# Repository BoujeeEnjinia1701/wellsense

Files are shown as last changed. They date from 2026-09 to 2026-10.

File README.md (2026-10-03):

# WellSense

     

**Area:** Water Security · **TRL:** 3 of 9 (proof of concept on paper) · **Value-engineering target:** $200 USD for WellSense parts (estimated $262.40), FieldNode core costed separately · **Difficulty:** 2 of 5

A well and borehole water level logger with a submersible pressure sensor and FieldNode telemetry, showing seasonal drawdown so communities can manage shared groundwater.

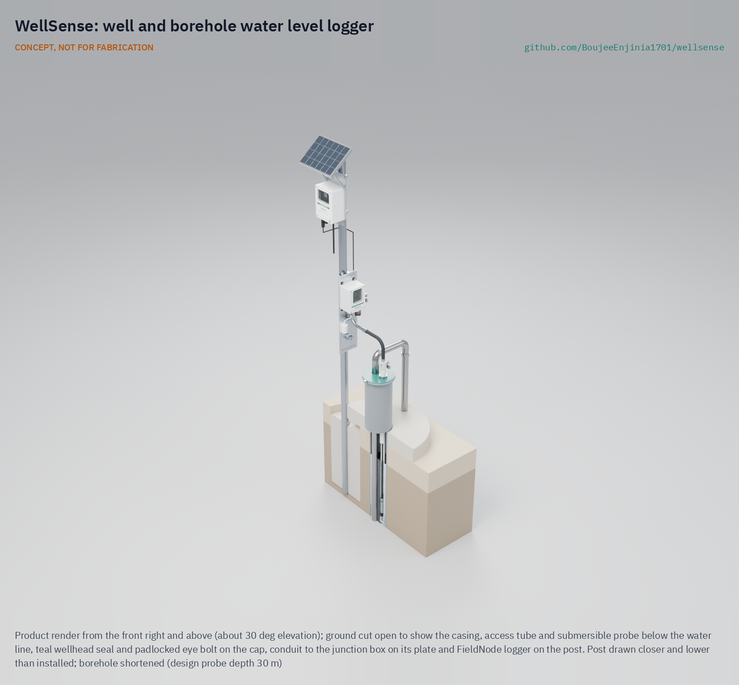
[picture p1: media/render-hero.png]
WellSense: well and borehole water level logger, product render


[Exploded render](media/render-exploded.png) · [Detail render](media/render-detail.png) · [Interactive 3D model](media/viewer.html) · [Concept blueprint (PDF)](media/concept-blueprint.pdf) · [General arrangement WLS-DWG-001 (PDF)](cad/drawings/WLS-DWG-001.pdf) · [Sizing calculations](docs/04-calcs/01-sizing.md) · [Prototype build plan](docs/05-build-plan.md) · [Design decisions register](docs/06-design-decisions.md) · [Review note](docs/REVIEW.md)

## Concept rationale

Measurement is the first step to shared management of an aquifer. A vented pressure transducer hung in a well gives a continuous water level record with millimetre resolution, and it is the same method groundwater agencies use ([USGS, 2011](https://pubs.usgs.gov/tm/1a1/)). WellSense puts that method in the wells people already draw from, on the lab's shared FieldNode core, so the only new parts are the probe, an access tube, a wellhead seal and a small interface board. A manual tape check each quarter keeps the record honest.

It is open and garage-buildable because the communities that share falling aquifers are rarely the ones that own monitoring equipment. Commercial loggers are closed and costly; a design built from plumbing parts, a stock industrial transducer and off-the-shelf modules can be made, checked and repaired locally, and its data belong to the community that hosts the well.

## Burning platform

Groundwater provides about half of the water withdrawn for domestic use worldwide, including drinking water for most rural people, and about 25 % of irrigation water ([UNESCO, WWDR 2022](https://www.unesco.org/reports/wwdr/2022/en)). Across 1,693 aquifer systems, rapid declines of more than 0.5 m a year are widespread in the twenty-first century, and declines have accelerated over four decades in 30 % of regional aquifers ([Jasechko et al., Nature, 2024](https://www.nature.com/articles/s41586-023-06879-8)).

When levels fall unmeasured, the response is to drill deeper: in the United States, typical wells are being built deeper 1.4 to 9.2 times more often than shallower, which the authors call an unsustainable stopgap ([Perrone and Jasechko, 2019](https://www.nature.com/articles/s41893-019-0325-z)). The same global study shows that levels recover where pumping is regulated, as in the Bangkok basin, so a shared record that people trust is worth having early.

## Where it could be used

### By industry

| Industry | Use |
| --- | --- |
| Rural water supply and WASH programmes | Warn handpump and borehole committees before the static level nears the pump intake |
| Irrigated agriculture | Let farmer groups see seasonal drawdown in their own wells and agree pumping or cropping rules |
| Groundwater agencies and utilities | Densify official networks with low-cost community wells between observation boreholes |
| Drought early warning | Feed well levels into local drought indicators alongside rainfall |
| Mining, construction and dewatering | Track the effect of dewatering on neighbouring wells |
| Education and research | Teach aquifer response to pumping, recharge and air pressure with open data |

### By country or region

| Country or region | Why it matters there |
| --- | --- |
| India | The largest groundwater user in the world, over a quarter of the global total; groundwater serves more than 60 % of irrigated agriculture and 85 % of drinking water supplies ([World Bank](https://www.worldbank.org/en/news/feature/2012/03/06/india-groundwater-critical-diminishing)). |
| Sub-Saharan Africa | Groundwater storage is estimated at more than 100 times annual renewable freshwater, and boreholes can support handpumps ([MacDonald et al., 2012](https://iopscience.iop.org/article/10.1088/1748-9326/7/2/024009)), yet about one in four handpumps is out of service at any time ([Foster et al., 2019, via IRC](https://www.ircwash.org/resources/functionality-handpump-water-supplies-review-data-sub-saharan-africa-and-asia-pacific)). |
| Iran and the Arabian Peninsula | Named among regions of rapid decline in the global synthesis, which also reports slowing decline in the Saq aquifer after policy changes ([Jasechko et al., 2024](https://www.nature.com/articles/s41586-023-06879-8)). |
| United States (California) | The 2014 Sustainable Groundwater Management Act requires local agencies to reach sustainability within 20 years under monitored plans ([California DWR](https://water.ca.gov/programs/groundwater-management/sgma-groundwater-management)). |
| Southeastern Spain | Aquifer declines there are too small in area for satellite gravity to detect, so they must be measured in wells ([Jasechko et al., 2024](https://www.nature.com/articles/s41586-023-06879-8)). |
| Thailand (Bangkok) | Levels that fell in the late twentieth century recovered after regulation ([Jasechko et al., 2024](https://www.nature.com/articles/s41586-023-06879-8)), a case for measuring and managing early. |

## What sparked the idea

The starting point was the Andhra Pradesh Farmer Managed Groundwater Systems project, launched in 2003 in seven drought-prone districts of southern India ([FAO](https://www.fao.org/land-water/overview/projects/previous-projects/andhra-pradesh-farmer-managed-groundwater-systems/en/)). There, farmers took fortnightly measurements of static and pumping water levels in their own wells, kept rain gauges, and used the numbers to draw up a crop-water budget before each winter season; about half a million farmers in 661 habitations took part ([FAO, *Smallholders and Sustainable Wells*, 2013](https://www.fao.org/4/i3320e/i3320e.pdf)). The project showed that people who share an aquifer will manage it when they can see the water level themselves. WellSense asks what that practice looks like with a continuous, low-cost record in place of a hand reading every two weeks, so that the daily pumping cycle and the seasonal decline are visible between visits.

## Problem

Groundwater is falling in many regions, yet most wells have no measurement, so over-pumping is noticed only when wells run dry. Design with, not for: requirements must come from co-design with the communities that share the aquifer, through a local partner.

## Concept

A well and borehole water level logger with a submersible pressure sensor and FieldNode telemetry, showing seasonal drawdown so communities can manage shared groundwater. A vented 4 to 20 mA transducer hangs in its own access tube beside the pump, a sealed wellhead plate keeps the well clean, and the lab's FieldNode core reads it every 15 minutes and sends the level over LoRaWAN to an open dashboard.

TRL 3 calculations ([WLS-CAL-001](docs/04-calcs/01-sizing.md)): 0.52 mm resolution; 12.5 mm accuracy by root sum square after a two-point tape calibration with a 0.25 % class probe, 27.1 mm worst case, so the ±20 mm target is at risk; a 24 V boost on the interface board, because FieldNode's 12 V rail cannot drive the loop; 38.2 mWh a day of sensor energy, 1.6 % of FieldNode's allowance; a 22 mm probe with 2.3 mm radial clearance in the 1 in access tube; and $262.40 in WellSense parts at a 30 m probe depth for the constructable design with its locks, against a $200 value-engineering target, a hypothetical control target ($401.40 with the FieldNode core). Eight of sixteen requirements are met on paper; drinking water evidence (R9) is not. See the [design precis](docs/02-concept.md), [requirements](docs/03-requirements.md) and decision records [WLS-DDR-001](docs/decisions/0001-trl2-review-decisions.md), [WLS-DDR-002](docs/decisions/0002-recommendations-accepted.md) [WLS-DDR-003](docs/decisions/0003-panel-tilt-direction.md) and [WLS-DDR-004](docs/decisions/0004-design-for-construction.md).

Full design precis: [docs/02-concept.md](docs/02-concept.md)

## Key components

- Vented submersible pressure transducer, 4 to 20 mA, 0 to 10 m, 0.25 % class, 22 mm diameter or less
- Vented cable with desiccant breather
- 25 mm PVC access tube, drilled at the bottom, with a tube cap, cross bolt and cable support grip
- Split HDPE seal plate with spigot rings, EPDM gasket and wraps, rim band and tube collar
- Galvanized conduit with a flexible tail over the surface cable from the tube cap to the junction box
- 4 to 20 mA interface board with 24 V boost, and barometric reference sensor
- Junction box on an aluminium plate with V-blocks and band clamps
- FieldNode core (shared lab node, built to its own build plan) on a mounting post set in a concrete footing, with FieldNode's sun shield at hot sites
- Open community dashboard, plus a shared manual water level tape for checks

The priced bill of materials is in [bom/bom.csv](bom/bom.csv). The parametric model is `cad/src/model.py`, with STEP and STL exports in `cad/step/` and `cad/stl/`.

## Building the prototype

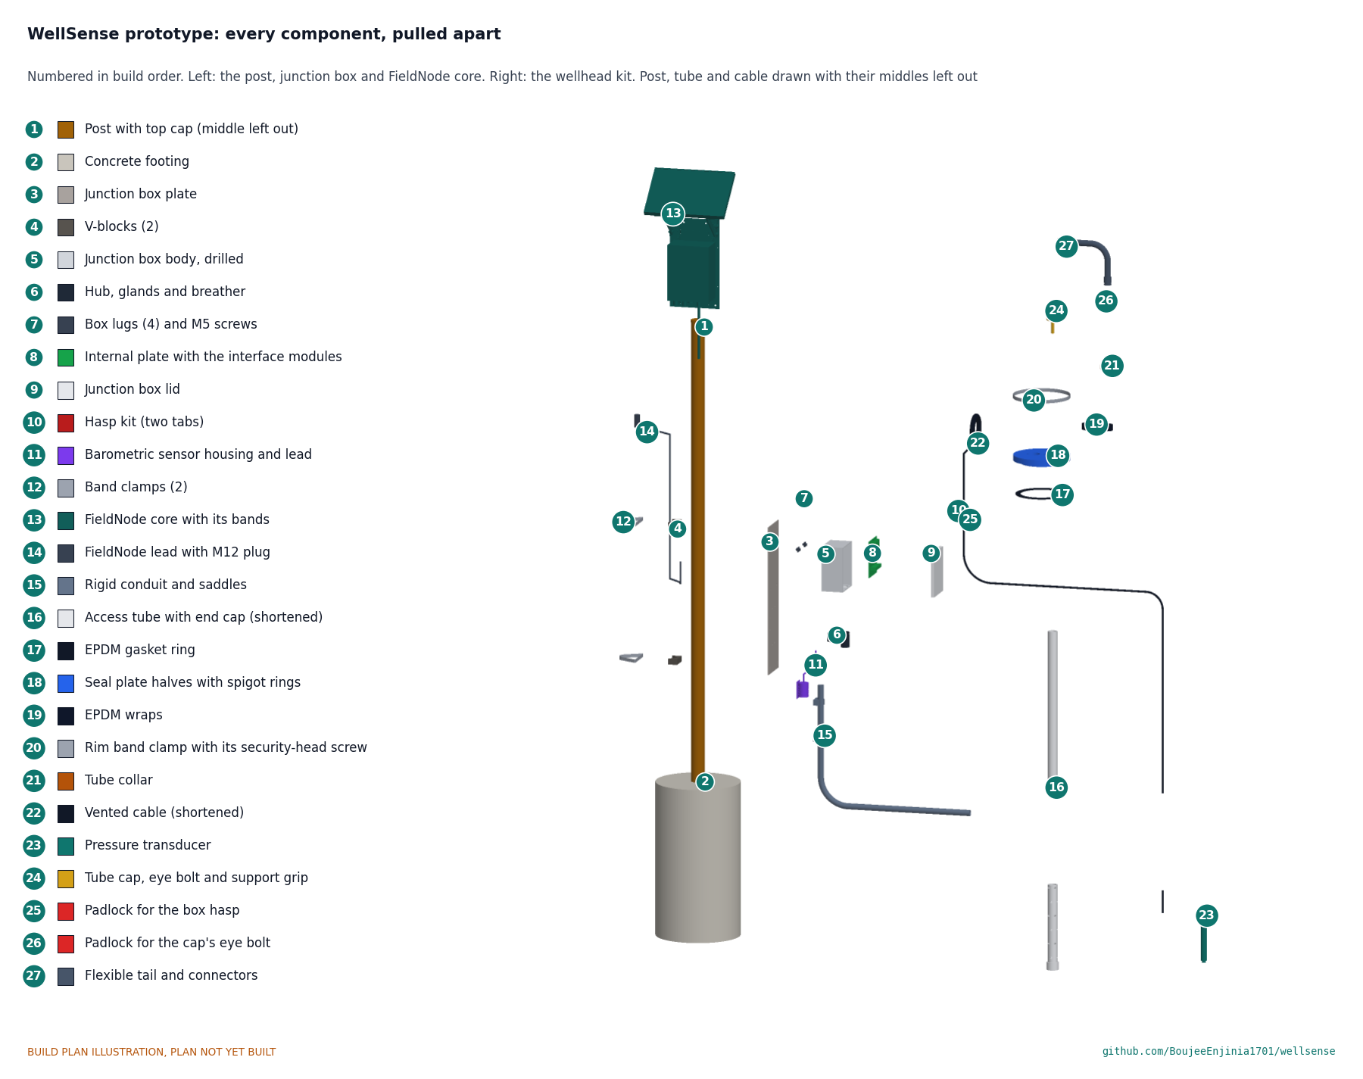
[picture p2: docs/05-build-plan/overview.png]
Every component of the WellSense prototype, pulled apart and numbered in build order


The [prototype build plan](docs/05-build-plan.md) (WLS-BLD-001, plan, not yet built) shows how to make each component and fit it to the next, in 9 making sketches, 11 joint close-ups and 18 assembly steps drawn from the model. The post, junction box plate, V-blocks and conduit are sawn, drilled and bent from steel and aluminium stock; the seal plate is cut from HDPE sheet with a jigsaw; the access tube and its cap are drilled PVC; the junction box's internal plate is 3D printed; the FieldNode core is built to its own plan. Writing the plan made the design constructable: eleven changes, such as a split seal plate that fits round an installed riser, a tube collar, a cross bolt and support grip that carry the probe, a flexible conduit tail so the cap can lift for calibration, and a junction box plate on V-blocks, are recorded in [WLS-DDR-004](docs/decisions/0004-design-for-construction.md). The parts now cost about $244, $44 over the $200 value-engineering target, a hypothetical control target; the [design decisions register](docs/06-design-decisions.md) lists the savings worth trying.

## Safety

> Keep the wellhead sealed to protect water quality and use materials suitable for drinking water contact for anything in the well. Disinfect everything lowered into a supply well.
>
> Isolate and lock off any mains-powered pump before working at the wellhead. Never leave an open well unattended; open wells are a fall and drowning hazard.
>
> The FieldNode core contains a lithium iron phosphate cell; follow its fusing and charging limits.

## Repository layout

| Folder | Contents |
| --- | --- |
| `docs/` | Problem, concept, requirements, calculations and design decisions |
| `cad/src/` | build123d Python source, the source of truth for all geometry |
| `cad/step/`, `cad/stl/` | Exported models for FreeCAD, other CAD tools and printing |
| `cad/drawings/` | 2D sketches and dimensioned drawings |
| `bom/` | Bill of materials |
| `electronics/` | KiCad schematics and PCB layouts |
| `firmware/` | Microcontroller code |
| `media/` | Renders, perspectives and photos |
| `build-log/` | Dated prototyping notes |

## Documentation

Controlled documents follow the portfolio [documentation standard](.kit/STANDARDS.md). Each carries a document ID (WLS-PRC-001 for the precis), a version and a revision history. Branded PDFs are built with `python .kit/render.py` and attached to GitHub Releases when a document is tagged, for example `WLS-PRC-001/v1.0`.

## Credits

Designed by Amish Chadha. See [CONTRIBUTORS.md](CONTRIBUTORS.md) for roles. To cite this design, use [CITATION.cff](CITATION.cff) (GitHub shows it as "Cite this repository").

AI assistance (Claude) was used to accelerate concept renders, prototype documentation and first-pass sizing calculations. Design direction and all decisions are Amish Chadha's, recorded in this repository's decision records (`docs/decisions/`).

## Licenses

- **Hardware** (CAD, drawings, BOM, electronics): [CERN-OHL-S v2](LICENSE)
- **Software** (firmware, scripts, notebooks): [MIT](LICENSE-SOFTWARE)

A project of the [Design Molecule](https://designmolecule.com) lab.

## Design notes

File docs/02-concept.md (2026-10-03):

---
doc_id: WLS-PRC-001
title: WellSense design precis
project: WellSense
doc_type: Design precis
version: "0.8"
status: Draft
date: '2026-10-02'
author: Amish Chadha
license: CERN-OHL-S-2.0
revisions:
- version: "0.1"
  date: '2026-09-25'
  author: Amish Chadha
  change: Initial scaffold
- version: "0.2"
  date: '2026-09-25'
  author: Amish Chadha
  change: Populate to TRL 2 (architecture, first-order numbers, safety, media)
- version: "0.3"
  date: '2026-09-25'
  author: Amish Chadha
  change: TRL 3 update from WLS-CAL-001 and WLS-DDR-001 (24 V loop boost, 0.25 % class probe, two-point calibration, numbers checked, choices adopted for TRL 3 pending review)
- version: "0.4"
  date: '2026-09-25'
  author: Amish Chadha
  change: Recommendations accepted by Amish (DDR-002)
- version: "0.5"
  date: '2026-09-26'
  author: Amish Chadha
  change: Budget approved by Amish; parts within the $200 budget
- version: "0.6"
  date: '2026-10-02'
  author: Amish Chadha
  change: Constructable design (WLS-DDR-004) and build plan WLS-BLD-001; cost against the value-engineering target
- version: "0.7"
  date: '2026-10-02'
  author: Amish Chadha
  change: Pinout, battery-only, hot-site, locking and partner points from Amish's decisions of 2026-10-02 (WLS-DEC-001)
- version: "0.8"
  date: '2026-10-02'
  author: Amish Chadha
  change: Locks modelled and priced (BOM line 16); cost USD 262.40; R16 met on design review; figures and tables brought into line with WLS-CAL-001 v0.5
---

# WellSense design precis

## Summary

WellSense hangs a vented submersible pressure transducer in its own access tube inside an existing well and reads it every 15 minutes through the lab's shared FieldNode core, which sends the level over LoRaWAN to an open community dashboard. The TRL 3 calculations (WLS-CAL-001) give 0.52 mm resolution and a sensor load of 38.2 mWh a day, 1.6 % of FieldNode's 100 mW allowance. They also found that FieldNode's 12 V rail cannot drive the current loop, so the interface board carries a 24 V boost. After a two-point field calibration against a manual tape, a 0.25 % class probe reaches 12.5 mm by root sum square against the ±20 mm target, but 27.1 mm if every error adds, so accuracy is at risk. Amish accepted all recommendations on 2026-09-25 (WLS-DDR-002): the budget rises to $190 for the 30 m design well, the probe is limited to 22 mm so it runs freely in the 1 in access tube (2.3 mm radial clearance), a galvanized conduit protects the surface cable, FieldNode's sun shield is fitted at hot sites, and pumping tests on a public network send every 30 min. Writing the prototype build plan (WLS-BLD-001) made the design constructable (WLS-DDR-004): a split HDPE seal plate that closes round the riser and pump cable, a collar that carries the tube, a cross bolt and support grip that carry the probe, a flexible conduit tail so the cap can lift for calibration, and a junction box on a plate with V-blocks. Value-engineering target: USD 200. Estimated cost of the constructable design: USD 262.40 at a 30 m probe depth (USD 62.40 over the target), and $401.40 with the FieldNode core. The design choices below are decided by Amish (WLS-DDR-001 and WLS-DDR-002); the changes for construction were accepted by Amish on 2026-10-02 (WLS-DEC-001).

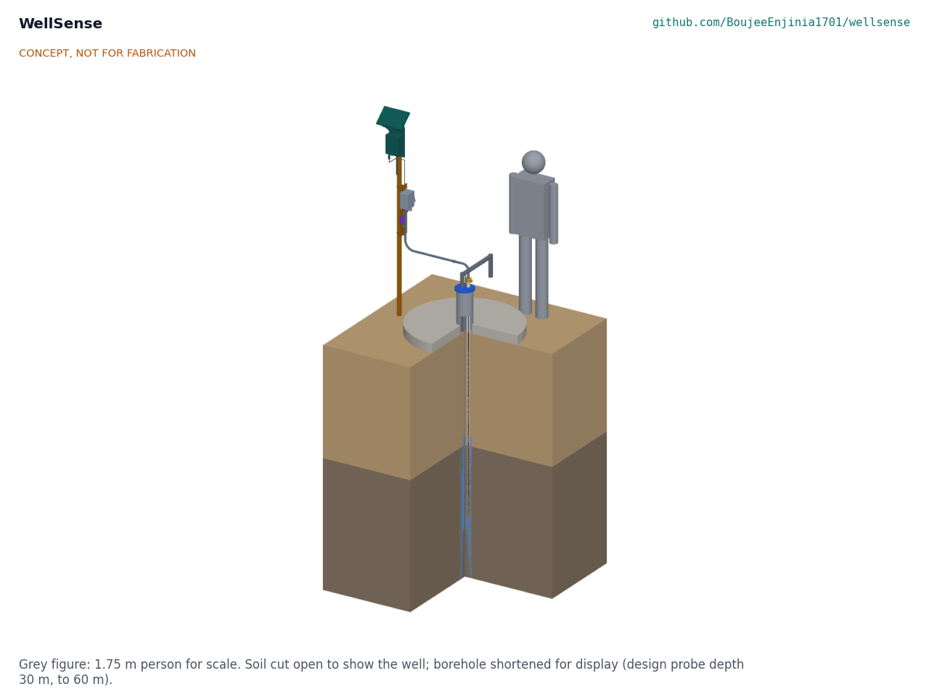
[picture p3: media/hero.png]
Hero render


Figure 1. Concept massing model in a borehole with a pump and riser, soil cut open, 1.75 m person for scale. The borehole is shortened for display. CONCEPT, NOT FOR FABRICATION.

## How it works

1. **Sense.** The transducer measures the pressure of the water column above it. Its cable carries a capillary vent tube to the surface, so the sensor reads gauge pressure and air pressure changes cancel out. Water above the probe is h = p / (ρg), about 102 mm per kPa.
2. **Keep clear of the pump.** The probe, 22 mm in diameter or less, hangs at a recorded depth inside a 25 mm PVC access tube, slotted at the bottom, so it cannot tangle with the pump cable or riser and can be pulled for checks without touching the pump.
3. **Seal the wellhead.** A split HDPE seal plate replaces or supplements the existing well cap: its two halves close round the riser, the pump cable and the access tube on EPDM wraps, a spigot ring locates it in the casing and a band round its rim holds it shut. A collar on the tube rests on the plate. The probe hangs from a cable support grip on a cross bolt in the tube cap; the cable leaves the cap through a short flexible tail and runs to the junction box inside a 1/2 in galvanized conduit.
4. **Read.** FieldNode switches its 12 V rail on sensor port 1 for about 2 s every 15 min. A boost on the interface board raises it to 24 V, because 12 V leaves the transducer 4.44 V short of its 12 V minimum through the shunt and 62 m of cable (WLS-CAL-001, section B). The 4 to 20 mA loop current develops 0.6 to 3.0 V across a 150 Ω precision shunt, read by a 16-bit ADC over I2C. A barometric sensor on the post logs air pressure.
5. **Convert and send.** Firmware converts current to water above the probe, then to depth to water below the measuring point: depth = probe depth below the measuring point minus water above the probe. FieldNode stores each reading and sends it in a short LoRaWAN uplink. During a pumping test at 1 min, readings are batched: every 15 min on a private TwinKit gateway, every 30 min on a public network to stay within fair use (22.7 s a day at SF9).
6. **Show.** An open dashboard plots level below ground, daily pumping drawdown and recovery, and the change against the same month last year. The community owns the data and can export CSV.
7. **Check.** At installation a caretaker measures depth to water with a manual electric tape, as in USGS procedures ([Cunningham and Schalk, 2011](https://pubs.usgs.gov/tm/1a1/)), then lifts the cap and probe a measured 1 m, the cable feeding from a service loop in the junction box, and reads again; the two points fix offset and span. Each quarter a tape reading checks and corrects drift.

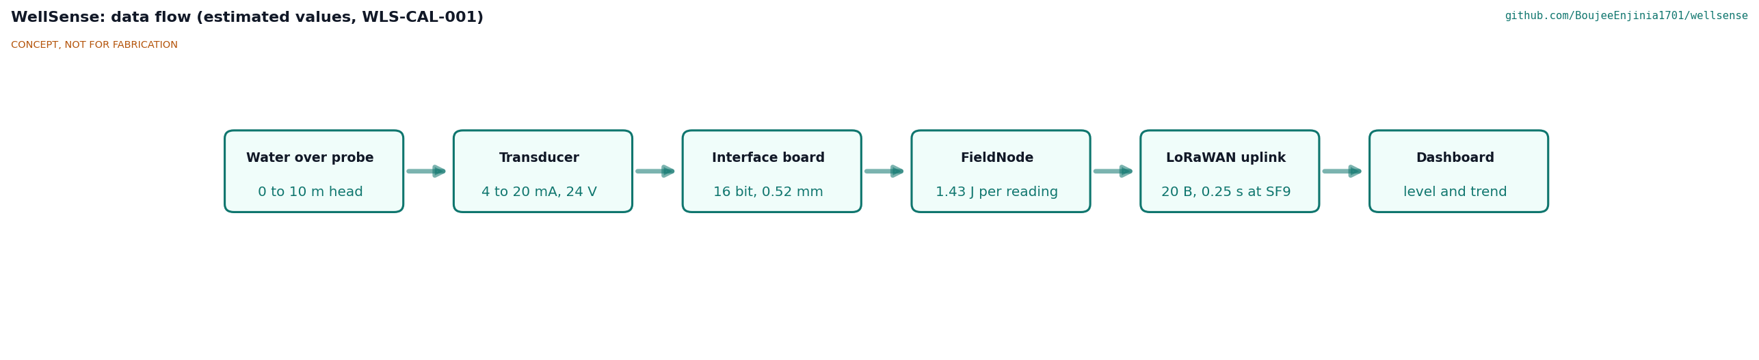
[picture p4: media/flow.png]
Data flow


Figure 2. Data flow from probe to dashboard. Values are estimates from WLS-CAL-001.

## Main components

Table 1. Main components, numbered as in the BOM and the exploded view.

| # | Component | Adopted choice | Notes |
| --- | --- | --- | --- |
| 1 | Pressure transducer | Vented 4 to 20 mA, 0 to 10 m, 0.25 % full scale class, 316 stainless, 22 mm diameter or less, IP68 | Range and type per DDR-001, D2 and D3; diameter per DDR-002 |
| 2 | Vented cable | PU or PE jacket, two 0.2 mm² cores, 400 N strain member, vent capillary, about 7 mm | Probe depth plus 2.7 m, to 60 m |
| 3 | Access tube | 25 mm (1 in) Sch 40 PVC, 26.6 mm bore, drilled with 8 mm holes over the bottom 0.5 m, slip cap on the end | Where a pump or riser shares the casing (DDR-001, D4); 2.3 mm radial clearance for a 22 mm probe (DDR-002) |
| 4 | Wellhead seal plate | Two 20 mm HDPE halves, 200 mm diameter, with spigot rings, EPDM gasket and wraps, a rim band with a security-head screw and a tube collar, for 150 mm casing | Fits round an installed riser and pump cable; keeps surface water and insects out |
| 5 | Tube cap and support grip | PVC slip cap with an M5 eye bolt as the cross bolt, padlocked; stainless cable support grip | Sets and records probe depth; lifts off for calibration |
| 6 | Junction box | IP66 box with lugs, a padlock hasp, two glands, a conduit hub and a silica gel breather in its floor | Desiccant changed every visit |
| 7 | Interface board | 150 Ω 0.1 % 10 ppm/K shunt, 16-bit ADC with series input resistor, 12 to 24 V boost, 3.3 V regulator, TVS surge protection | Off-the-shelf modules, no custom PCB |
| 8 | FieldNode core | Lab shared node: enclosure, 6 W panel, LiFePO4 cell, LoRaWAN radio; sun shield at hot sites | See the FieldNode repo (FND-DDR-002 for the shield) |
| 9 | Barometric sensor | BMP390 or BME280 class, in a vented housing on the post | Aquifer air pressure response; vent check |
| 10 | Mounting post | 48.3 mm galvanized pipe, 2.7 m, 2.1 m above ground, 0.75 m from the well; junction box plate with V-blocks and band clamps | FieldNode base at 1.75 m (FND-DDR-001, D11) |
| 13 | Post footing | 300 mm diameter, 0.6 m deep, one 25 kg bag of concrete | Added at TRL 3 |
| 14 | Surface cable conduit | 1/2 in (21.3 mm OD) galvanized rigid conduit, about 0.95 m with one bend, on two saddles; 0.3 m flexible tail to the tube cap | Added under DDR-002 for R16; tail and saddles under DDR-004 |
| 15 | FieldNode lead | Four-core lead with an M12 plug, junction box to FieldNode port A (pins 1 to 4 of FieldNode's standard pinout) | Added under DDR-004 |
| 16 | Locking | One security-head screw and bit, two keyed-alike padlocks, one hasp kit | Decided 2026-10-02 (WLS-DEC-001); lockable steel wellhead cover only at exposed sites |

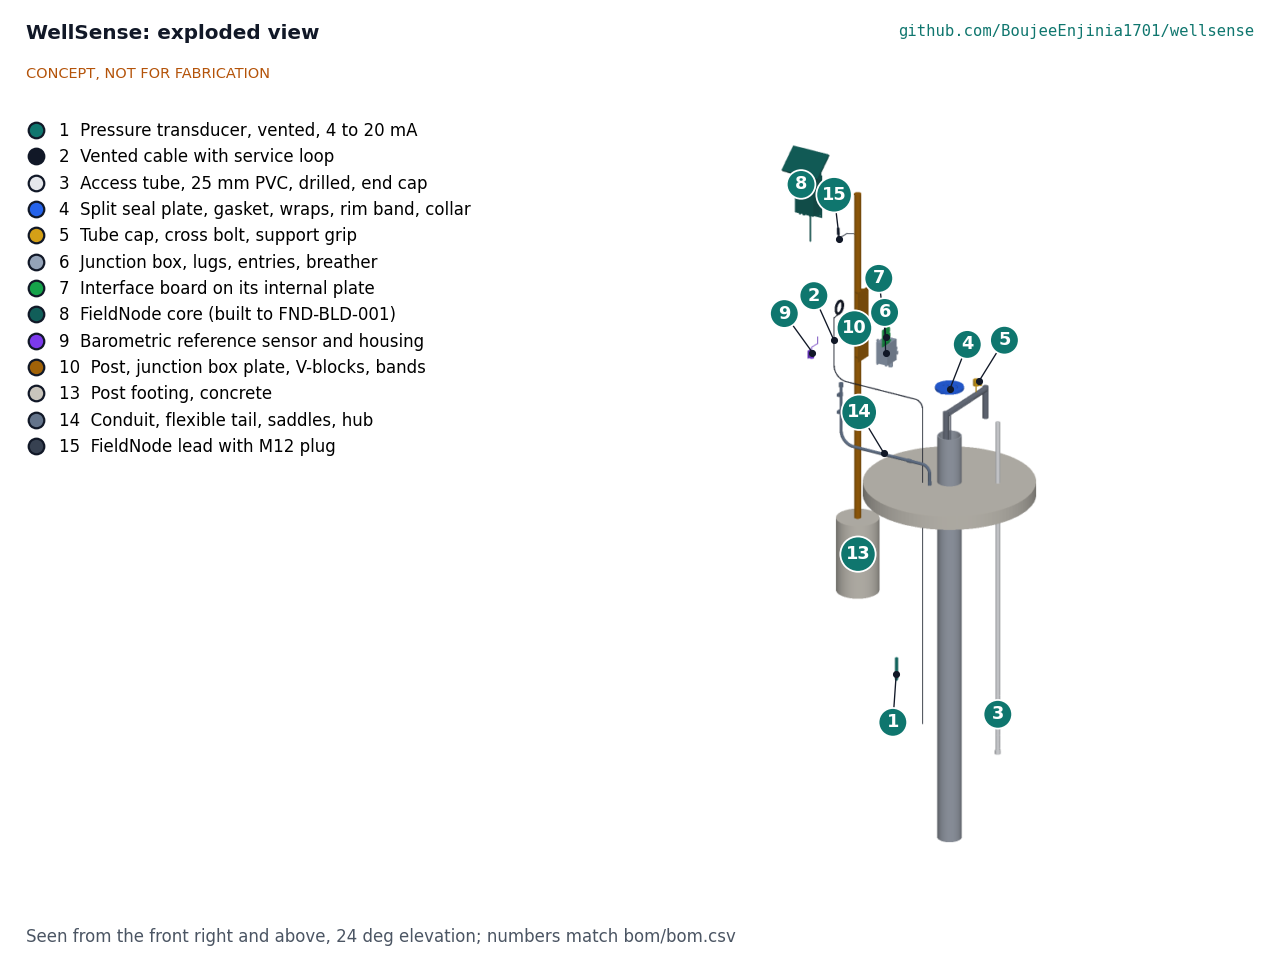
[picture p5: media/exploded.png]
Exploded view


Figure 3. Exploded view with BOM callouts. CONCEPT, NOT FOR FABRICATION.

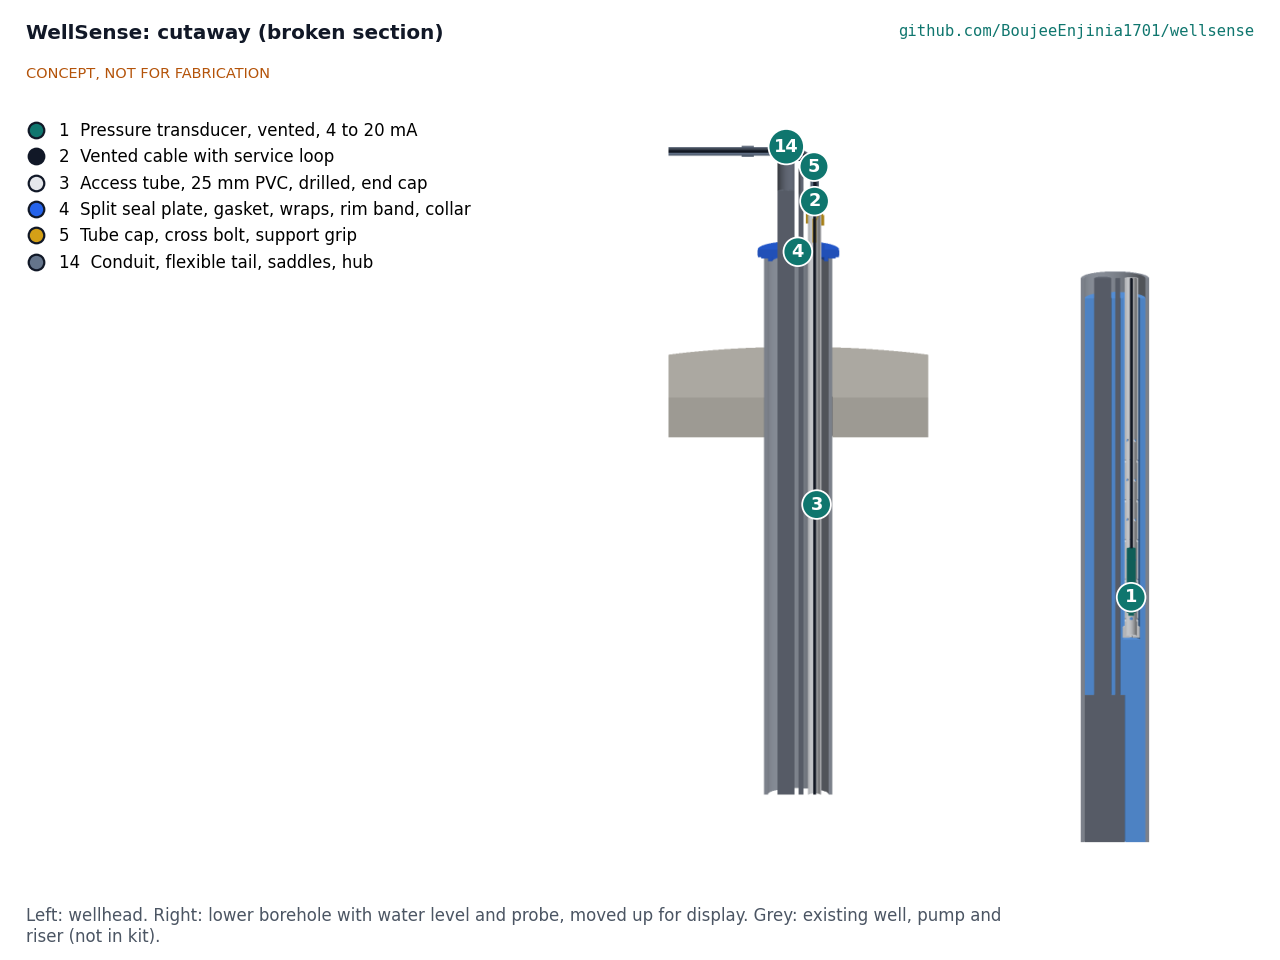
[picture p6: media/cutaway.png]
Cutaway


Figure 4. Broken section: wellhead (left) and lower borehole with water level and probe (right).

## Numbers checked at TRL 3

All values come from WLS-CAL-001, where the assumptions are stated.

Table 2. Key numbers from WLS-CAL-001.

| Quantity | Value | Basis | Requirement |
| --- | --- | --- | --- |
| Full-scale pressure | 98.07 kPa | 10 m × 1,000 kg/m³ × 9.80665 m/s² | R1 met |
| Resolution | 0.52 mm | 16 mA × 150 Ω = 2.4 V; 125 µV ADC step; 19,200 steps over 10 m | R3 met |
| Loop voltage at the transducer | 7.56 V from 12 V; 20.16 V with the 24 V boost | 22 mA, 150 Ω shunt, 62 m of cable, diode | 12 V minimum; boost required |
| Accuracy, datasheet only | 50 mm (0.5 % class); 25 mm (0.25 % class) | Percentage of 10 m full scale | |
| Accuracy after two-point calibration | 12.5 mm RSS; 27.1 mm worst case | 0.25 % class probe; Table 2 of WLS-CAL-001 | R4 at risk |
| Density change, 4 to 25 °C | 0.29 %, 29 mm at 10 m | Fixed site density in firmware | |
| Absolute sensor without compensation | ±306 mm | ±3 kPa weather swing | Reason for the vented design |
| Energy per reading | 1.43 J | 24 V × 22 mA × 2 s through boost and rail, plus the controller | |
| Sensor energy per day | 38.2 mWh | 96 readings | R8 met: 1.6 % of 100 mW |
| Pumping test airtime, public network | 22.7 s/day | 30-reading batch every 30 min at SF9 | R6 met, within 30 s fair use |
| Energy at 1 min interval | 0.573 Wh/day | 1,440 readings | 24 % of the allowance during tests |
| Storage per year | 1.12 MB | 35,040 readings × 32 bytes | R7 met: 6.7 % of 16 MB |
| Probe clearance in the tube | 2.3 mm radial | 22 mm probe in 26.6 mm bore | R10 at risk (pump may need pulling) |
| Hanging loads at 60 m | 35 N cable (factor 11.5); 264 N tube (factor 58) | Dry, worst case | R2 met |
| WellSense parts per well | $262.40 | bom/bom.csv, 30 m probe depth, constructable design with its locks | R12: $62.40 over the $200 value-engineering target |
| With FieldNode core | $401.40 | Adds line 8 ($139.00, FND-CAL-001 v0.3); $410.40 with the hot-site shield | Counted in the FieldNode repo (DDR-001, D1) |
| Depth-dependent cost | $1.80 per metre | Cable plus access tube | |

## Key design choices

Decided by Amish, 2026-09-25: go with recommendation (WLS-DDR-001 and WLS-DDR-002).

- **Vented 4 to 20 mA transducer rather than an absolute-pressure sensor with barometric compensation (D2).** The current loop is robust over long cables and the reading needs no compensation. The costs are desiccant maintenance at the vent and a 24 V boost, since the loop needs more than FieldNode's 12 V rail. A sealed absolute sensor with RS-485 and a surface barometer is kept as a variant.
- **0 to 10 m range (D3),** with a 0 to 20 m variant for wells whose seasonal swing plus drawdown exceeds 9 m.
- **Own access tube where a pump is present (D4).** Standard practice to protect the probe and the pump; also the hardest part to fit in an existing well (R10 at risk). The tube ends above the pump.
- **FieldNode as the core (D8).** Reuses the lab's shared enclosure, solar charging, storage and radio, so WellSense designs only the well side. The interface board connects to sensor port 1 (switched 12 V rail and I2C); WellSense signs off FieldNode's proposed standard pinout (pin 1 switched rail, pin 2 data A, pin 3 ground, pin 4 data B, pin 5 analog), with I2C on data A and B, and keeps the standard core with its panel; no battery-only variant is asked for (decided by Amish, 2026-10-02, WLS-DEC-001).
- **Manual tape as the reference (D6).** A shared electric tape sets the datum and the two-point calibration at installation and checks drift each quarter.
- **Levels only (D7).** No camera, audio or pump data; the dashboard shows water level so that sharing the data carries little risk.
- **1 in access tube with a probe of 22 mm or less (DDR-002).** Keeps the tube small enough to pass a centered riser in 150 mm casing; a 1-1/4 in tube would fit only 200 mm casing.
- **Galvanized conduit over the surface cable (DDR-002).** Protects the cable from livestock, mowing and tampering between the tube cap and the junction box.
- **Hot sites (DDR-002).** R15 stays at 55 °C; where the design maximum air temperature exceeds 30 °C (FND-CAL-001 v0.2), the FieldNode core carries FieldNode's sun shield (FND-DDR-002). Until FieldNode confirms the shielded core at 55 °C ambient, WellSense is not sited where the design maximum exceeds 45 °C (decided by Amish, 2026-10-02, WLS-DEC-001).
- **Pumping-test uplinks (DDR-002).** Every 30 min on a public network, every 15 min on a private TwinKit gateway.

## Safety

> **Safety:** Drinking water. Anything lowered into a supply well can contaminate it. Disinfect the probe, cable and tube before installation (for example with a chlorine solution as local water authorities advise), use only materials suitable for drinking water contact, and keep the wellhead sealed so surface water, insects and animals cannot enter. Involve the well owner or water authority before opening a public supply well.

> **Safety:** Electrical and pump hazards. Many wells contain a submersible pump on mains power. Isolate and lock off the pump supply before working at the wellhead, and keep the logger wiring separate from the pump cable. WellSense itself runs at 24 V or less (extra-low voltage).

> **Safety:** Lithium cell. The FieldNode core contains a lithium iron phosphate cell of about 19 Wh; follow the FieldNode safety notes on fusing and charging temperature limits.

> **Safety:** Working at an open well. An open dug well or large borehole is a fall and drowning hazard, especially for children. Never leave a wellhead open, and cover large-diameter wells while working.

> **Safety:** Lifting and cable handling. A long cable with a probe and tube can be heavy; lower it slowly with two people so it does not run away into the well, and never let the cable carry more than the rated load of its strain member.

## Open questions

- [ ] Can an access tube be added beside an installed pump without pulling it? Only an installation trial can tell.
- [ ] Real long-term drift of low-cost vented transducers; is a quarterly tape check enough?
- [ ] Which drinking water material certifications can low-cost suppliers show for cable, seals and probe?
- [ ] How should the dashboard present drawdown so that non-specialists read it correctly? To be answered in co-design.
- [x] Locking of the seal plate, tube cap and junction box (R16): a security-head screw on the rim band, a padlock through the eye of the cross bolt (an eye bolt) and a padlockable hasp with a padlock on the box, fitted from the start; a lockable steel cover at exposed sites (decided by Amish, 2026-10-02, WLS-DEC-001). In the model and the BOM (line 16, $16.50, and $1.50 for the eye bolt).
- [ ] First partner and region for co-design: approach ACWADAM in Pune, India, the first candidate (decided by Amish, 2026-10-02, WLS-DEC-001).
- [x] Cost at the 30 m design depth with the conduit included ($197.60). Budget set to $200 to cover the priced BOM: decided by Amish, 2026-09-26 (WLS-DDR-002). Since 2026-10-01 the $200 is a value-engineering target; the constructable design with its locks is estimated at $262.40.

Open decisions are tracked in the [design decisions register](06-design-decisions.md).

Concept media: [blueprint sheet](../media/concept-blueprint.pdf), [interactive 3D model](../media/viewer.html).

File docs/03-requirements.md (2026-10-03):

---
doc_id: WLS-REQ-001
title: WellSense requirements
project: WellSense
doc_type: Requirements
version: "0.8"
status: Draft
date: '2026-10-02'
author: Amish Chadha
license: CERN-OHL-S-2.0
revisions:
- version: "0.1"
  date: '2026-09-25'
  author: Amish Chadha
  change: Initial scaffold
- version: "0.2"
  date: '2026-09-25'
  author: Amish Chadha
  change: First measurable requirements for TRL 2, with status against the concept
- version: "0.3"
  date: '2026-09-25'
  author: Amish Chadha
  change: TRL 3 status from WLS-CAL-001; R1, R6 and R12 restated under WLS-DDR-001 (D1, D3, D5); assumptions updated
- version: "0.4"
  date: '2026-09-25'
  author: Amish Chadha
  change: Recommendations accepted by Amish (DDR-002)
- version: "0.5"
  date: '2026-09-26'
  author: Amish Chadha
  change: Budget approved by Amish; R12 target $200, status Not met to Met
- version: "0.6"
  date: '2026-10-02'
  author: Amish Chadha
  change: Constructable design (WLS-DDR-004); R12 reported against the $200 value-engineering target; R2 status names the tube collar
- version: "0.7"
  date: '2026-10-02'
  author: Amish Chadha
  change: R15 and R16 notes record Amish's decisions of 2026-10-02 (WLS-DEC-001); no status changed
- version: "0.8"
  date: '2026-10-02'
  author: Amish Chadha
  change: Locks modelled and priced (BOM line 16); R16 now Met on design review; R12 restated at $262.40; R11 estimate 125 min
---

# WellSense requirements

These requirements are checked by calculation in WLS-CAL-001 v0.5 against the constructable design of WLS-DDR-004 and WLS-PRC-001 v0.8. Targets remain proposals, to be revised after co-design. Under WLS-DDR-001 (decided by Amish, 2026-09-25: go with recommendation), R1 names the 0 to 10 m range (D3), R6 states how 1 min readings are sent (D5), and R12 costs the WellSense parts only, with the FieldNode core costed in the FieldNode repo (D1). Under WLS-DDR-002, R12 is restated at $190 for the 30 m design well (raised to $200 by Amish on 2026-09-26 to cover the priced BOM), R10 limits the probe to 22 mm in the 1 in tube, R6 adds the 30 min uplink rule for pumping tests on public networks, and R15 requires FieldNode's sun shield at hot sites. No target was relaxed. Under the 2026-10-01 portfolio rule, `budget_usd` is a value-engineering target, a hypothetical control target rather than a limit, so R12 is reported as over or under that target. On paper, 8 requirements are met, 3 are at risk, 1 is not met (R9), 3 cannot be verified at TRL 3, and R12 is $62.40 over its value-engineering target.

Table 1. Requirements and status at TRL 3 (WLS-CAL-001 v0.5, Table 3).

| ID | Requirement | Target | Verification (TRL 3 or later) | Status at TRL 3 |
| --- | --- | --- | --- | --- |
| R1 | Measurement range (water above the probe) | 0 to 10 m (DDR-001, D3), with a 0 to 20 m variant | Datasheet | Met: 98.07 kPa full scale; swings to 9 m fit with 1 m headroom |
| R2 | Installation depth below the wellhead | Probe to 60 m or more | Cable and tube length; hanger load | Met: cable factor 11.5 and tube factor 58 at 60 m; a split collar carries the tube on the seal plate (0.24 MPa bearing) |
| R3 | Resolution | 1 mm or better | ADC and shunt calculation | Met: 0.52 mm (1.04 mm on the 20 m variant) |
| R4 | Accuracy after field calibration against a manual tape | ±20 mm over the range | Calculation, then side-by-side with a manual tape | **At risk:** 12.5 mm root sum square, 27.1 mm worst case, with a 0.25 % class probe and two-point calibration; a 0.5 % class probe does not meet it |
| R5 | Long-term drift | 20 mm a year or less, checked by a manual reading each quarter | Field record | Not verifiable at TRL 3: drift of low-cost transducers is not published; a quarterly check leaves at most 5 mm uncorrected |
| R6 | Reading interval | 15 min default; 1 min during a pumping test, logged and sent in batches (DDR-001, D5); on a public network a test sends every 30 min, on a private TwinKit gateway every 15 min (DDR-002) | Firmware configuration | Met by design: 30 min batches use 22.7 s a day at SF9, within 30 s fair use |
| R7 | Local storage | 1 year of 15 min readings without a link | Storage calculation | Met: 1.12 MB a year, 6.7 % of FieldNode flash |
| R8 | Energy | Probe and interface use 5 % or less of the FieldNode sensor energy budget at 15 min | Power budget | Met: 38.2 mWh a day, 1.6 % of the 100 mW allowance |
| R9 | Water safety | All wetted parts 316 stainless steel or materials certified for drinking water contact; well sealed against surface water | Material certificates | **Not met on evidence:** no certificate in hand for low-cost cable, seals or probe |
| R10 | Compatibility with the existing pump | Probe of 22 mm or less in its own 1 in access tube (DDR-002); no contact with pump, riser or pump cable | Design review, installation trial | **At risk:** tube and probe fit the 150 mm design well with 2.3 mm radial clearance, but fitting a tube may need the pump pulled |
| R11 | Installation | Two trained people, hand tools, 2 h or less when an access tube already exists | Installation trial | Not verifiable at TRL 3: 125 min estimate with the locks fitted, 5 min over the limit |
| R12 | Cost | Value-engineering target: WellSense parts $200 per well at a 30 m probe depth (`budget_usd`, a hypothetical control target), plus $1.80 per metre beyond; FieldNode core costed in the FieldNode repo (DDR-001, D1) | Priced BOM | **Over the target:** $262.40 at 30 m for the constructable design with its locks (WLS-DDR-004, WLS-DEC-001), $62.40 over; $401.40 with the FieldNode core |
| R13 | Data use | Dashboard shows level below ground, daily drawdown and change against the same month last year on a basic phone; CSV export | Demonstration with sample data | Not verifiable at TRL 3 (software not started) |
| R14 | Data ownership and privacy | Water level, time and well ID only; the hosting community controls sharing | Design review | Met by design |
| R15 | Environment | Probe IP68 at 1.5 times range; above-ground parts IP65, -10 to 55 °C; FieldNode sun shield fitted at hot sites (DDR-002) | Datasheets, later field test | **At risk:** met on datasheets for WellSense parts; with its shield the FieldNode core stays at 48.5 to 52.2 °C inside at 45 °C ambient (FND-CAL-001 v0.2), but it is rated to 45 °C ambient, not 55 °C. Until FieldNode confirms 55 °C, sites above 45 °C are not used (decided by Amish, 2026-10-02, WLS-DEC-001) |
| R16 | Tamper resistance | Wellhead parts lockable; no exposed cable at reachable height | Design review | **Met on design review:** the surface cable runs in galvanized conduit and a short flexible tail from the tube cap to the junction box (DDR-002, DDR-004), and the locking decided by Amish on 2026-10-02 (WLS-DEC-001) is modelled and priced (BOM line 16, $16.50, and $1.50 for the eye bolt): a security-head screw on the rim band, a padlock through the eye of the cap's cross bolt and a padlockable hasp with a padlock on the box. The padlock on the cap stops the eye bolt being unscrewed; it does not stop the cap being lifted off the tube, which the lockable steel wellhead cover does at exposed sites |

## Assumptions

- The full list of assumptions is in WLS-CAL-001, Table 1. The main ones follow.
- Water density 1,000 kg/m³ nominal; 1 m of water is 9.81 kPa. Density changes by 0.29 % between 4 and 25 °C, so firmware uses a fixed site density set from the groundwater temperature at installation, and local gravity rather than standard gravity.
- A vented (gauge) transducer (DDR-001, D2), so the reading is already referenced to air pressure. The barometric sensor records the aquifer's response to air pressure and detects a blocked vent.
- Accuracy after a two-point field calibration: the tape reading at installation and again after lifting the probe a measured 1 m. Nonlinearity, hysteresis and repeatability of a 0.25 % class probe taken as 0.10 % of full scale (typical, not measured).
- Loop powered at 24 V from a boost on the interface board, fed by FieldNode's switched 12 V rail at 90 % efficiency; 22 mA for 2 s per reading.
- Design case: 150 mm casing, 4 in pump on a 1-1/4 in riser, probe 30 m below the top of the casing.

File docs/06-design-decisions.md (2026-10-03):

---
doc_id: WLS-DEC-001
title: WellSense design decisions register
project: WellSense
doc_type: Design decisions register
version: "0.3"
status: Draft
date: '2026-10-02'
author: Amish Chadha
license: CERN-OHL-S-2.0
revisions:
  - version: "0.1"
    date: '2026-10-02'
    author: Amish Chadha
    change: Register opened with the build plan; budget treated as a value-engineering target
  - version: "0.2"
    date: '2026-10-02'
    author: Amish Chadha
    change: Amish approved the recommendations for open items 1 to 9 on 2026-10-02 (WLS-DDR-004 accepted with A1 and A2, ACWADAM as first candidate partner, standard FieldNode core and pinout, R15 kept with hot sites held, render items); moved to decisions made
  - version: "0.3"
    date: '2026-10-02'
    author: Amish Chadha
    change: Locks modelled and priced (BOM line 16); value-engineering cost restated at USD 262.40
---

# WellSense design decisions register

Every design decision still to be made, and every decision made, in one place. Each decision is argued in full in its decision record under `docs/decisions/`; this register is the index Amish works from. The build plan (`docs/05-build-plan.md`) describes the design as it stands and does not list open decisions.

## Open decisions

None. All open decisions were decided on 2026-10-02.

## To confirm when parts are bought

| # | What to confirm | Why it matters | Source |
| --- | --- | --- | --- |
| 1 | Drinking-water certificates for the probe, the vented cable, the HDPE sheet and the EPDM (gasket and wraps) | R9 is not met without them | WLS-REQ-001, R9; WLS-DDR-004 |
| 2 | The riser and pump cable diameters at the well | They set the seal plate's split holes (designed for a 42.2 mm riser and a 12 mm cable) | WLS-DDR-004, P6 |
| 3 | The junction box model, its boss spacing (80 x 110 mm assumed) and its lug kit | They set the internal plate holes and the lug holes in the plate | WLS-DDR-004, P3 |
| 4 | The shaft collar's rated axial grip on PVC pipe, at least 264 N | It carries the tube at 60 m | WLS-CAL-001, [D5] |
| 5 | The cable support grip suits 6 to 8 mm cable and carries at least 35 N | It carries the probe and cable at 60 m | WLS-CAL-001, [D6] |
| 6 | The probe body is 22 mm or less, and its supplier's price | 2.3 mm radial clearance in the tube; the BOM assumes the 26 to 28 mm class price | WLS-DDR-002; BOM line 1 |
| 7 | The flexible tail's connector fits a 22.5 mm hole in a 1 in PVC cap, with its locknut inside | The cap is the connector's only support | WLS-DDR-004, P5 and P8 |

## Value engineering

Value-engineering target: USD 200 (a hypothetical control target, not a limit). Estimated cost of the constructable design: USD 262.40 for the WellSense parts at the 30 m design depth (USD 62.40 over the target); USD 401.40 with the FieldNode core, which is costed in the FieldNode repo. Main cost drivers and savings worth trying:

- The largest lines are the transducer (USD 50), the access tube (USD 31 at 30 m), the post with its plate, V-blocks and bands (USD 32), the vented cable (USD 26.40 at 30 m), the seal plate set (USD 23) and the conduit set (USD 20). Cable and tube scale with depth at USD 1.80 a metre.
- Making the design constructable added USD 46.80: the seal plate set (+8), tube cap and grip (+4), junction box lugs, glands and internal plate (+6), terminal strip (+1), junction box plate and V-blocks (+10), flexible tail, saddles and hub (+10), the FieldNode lead (+7) and 1 m more cable (+0.80).
- The locks decided on 2026-10-02 added USD 18.00: line 16 (security-head screw and bit USD 3.50, two padlocks USD 9.00, hasp kit USD 4.00) and USD 1.50 for the eye bolt in line 5. The lockable steel wellhead cover is priced only when a site visit calls for it.
- Savings worth trying: fit the conduit set only where livestock or tampering is likely (USD 20); leave the access tube out where no pump shares the casing (USD 31 at 30 m, already the rule); mount the barometric module inside the junction box, which breathes through its desiccant, instead of in its own housing (about USD 4); buy the junction box with a pole-mount kit if one is offered at less than the plate, V-blocks and bands (up to USD 10); cut the seal plate from offcuts shared across several wells.

## Decisions made

| Date | Decision | Decided by | Record |
| --- | --- | --- | --- |
| 2026-09-25 | TRL 2 items D1 to D8: FieldNode core costed in its own repo; vented 4 to 20 mA transducer; 0 to 10 m range; own access tube where a pump shares the casing; 15 min readings, 1 min in pumping tests; quarterly manual tape check; levels only, community controls sharing; FieldNode as the core | Amish: "i accept all your recommendations, go with them across all repos." | WLS-DDR-001, WLS-DDR-002 |
| 2026-09-25 | TRL 3 items A9 to A13: design depth 30 m; 1 in tube with a probe of 22 mm or less; galvanized conduit over the surface cable; FieldNode sun shield at hot sites; pumping tests send every 30 min on a public network | Amish, same instruction | WLS-DDR-002 |
| 2026-09-26 | `budget_usd` set to $200 | Amish: "i approve all the budget items." | WLS-DDR-002, N1 |
| 2026-09-27 | FieldNode panel tilt corrected to face the way the node faces | Amish: "resolve the challenges for ConePro, BridgePulse, Grainguard and WellSense." | WLS-DDR-003 |
| 2026-09-30 | Make the design physically buildable while drawing the build plan | Amish: "If you are realising that the design cannot be built as per concept - fix the design assumptions to match and be physically feasible as you draw the illustrations." Changes made under this instruction; open for his review (open decision 1) | WLS-DDR-004 |
| 2026-10-01 | `budget_usd` is a value-engineering target, not a limit | Amish: "the budgets are a hypothethical control target to ensure we are thinking along a value engineering lens. its ok to ensure wording reflects that the hypothesis budget was x - the real cost being accrued is y" | STANDARDS section 18; this register |
| 2026-10-02 | Design for construction accepted: the changes P1 to P11 of WLS-DDR-004, as made | Amish: "APPROVED: The open decisions from the last wave (TremorTrace to ZeerBox) came in after the review and aren't on the page either." | WLS-DDR-004 |
| 2026-10-02 | Locking (R16): option (a) is fitted on the prototype from the start: a security-head screw on the rim band, a padlock through the cross bolt's head and a padlockable hasp kit on the junction box; the lockable steel wellhead cover is used at sites where the first site visit shows open access or livestock | Amish: "APPROVED: The open decisions from the last wave (TremorTrace to ZeerBox) came in after the review and aren't on the page either." | WLS-DDR-004, A1; WLS-PRC-001 open questions |
| 2026-10-02 | First partner and region: a participatory groundwater management group in India that works with farmer groups on shared aquifers; the first candidate to approach is ACWADAM in Pune, with its well sizes setting the design well and the FieldNode core at its sites on the IN865 band | Amish: "APPROVED: The open decisions from the last wave (TremorTrace to ZeerBox) came in after the review and aren't on the page either." | WLS-DDR-001, O1 |
| 2026-10-02 | Battery-only FieldNode variant: the standard FieldNode core with its panel is kept; no battery-only variant is asked of FieldNode until a site shows the panel cannot be placed | Amish: "APPROVED: The open decisions from the last wave (TremorTrace to ZeerBox) came in after the review and aren't on the page either." | WLS-DDR-001, O2 |
| 2026-10-02 | FieldNode sensor port pinout: FieldNode's proposed standard pinout is signed off for port A (pin 1 switched rail, pin 2 data A, pin 3 ground, pin 4 data B, pin 5 analog), with data A and B carrying I2C; the switched rail voltage is confirmed against the boost module input | Amish: "APPROVED: The open decisions from the last wave (TremorTrace to ZeerBox) came in after the review and aren't on the page either." | FND-DDR-001, O2; FND-DEC-001 |
| 2026-10-02 | FieldNode core above 45 °C: R15 stays at 55 °C, as decided on 2026-09-25 (WLS-DDR-002, A12); the FieldNode project is asked to confirm the shielded core at 55 °C ambient, and until it does WellSense is not sited where the design maximum exceeds 45 °C | Amish: "APPROVED: The open decisions from the last wave (TremorTrace to ZeerBox) came in after the review and aren't on the page either." | REVIEW.md, cross-repo actions; WLS-DDR-002, A12 |
| 2026-10-02 | FieldNode geometry in `cad/vendor/`: kept as a copy and re-exported whenever FieldNode's general arrangement is revised, as a line in the review checklist | Amish: "APPROVED: The open decisions from the last wave (TremorTrace to ZeerBox) came in after the review and aren't on the page either." | WLS-DDR-004, A2 |
| 2026-10-02 | Photoreal render layout: the post drawn closer to the well and lower than installed is accepted, for renders only | Amish: "APPROVED: The open decisions from the last wave (TremorTrace to ZeerBox) came in after the review and aren't on the page either." | REVIEW.md, 2026-09-26, render item 1 |
| 2026-10-02 | Exploded render: grouping the post, tube and cable together is accepted | Amish: "APPROVED: The open decisions from the last wave (TremorTrace to ZeerBox) came in after the review and aren't on the page either." | REVIEW.md, 2026-09-26, render item 5 |

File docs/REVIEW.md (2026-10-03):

# Review note: WellSense

## Session 2026-09-25: /populate to a strong TRL 2

### What was done

- `docs/01-problem.md` (WLS-PRB-001 v0.2): problem with cited figures, users and context, constraints, prior work, out of scope, open questions; co-design checklist kept.
- `docs/03-requirements.md` (WLS-REQ-001 v0.2): 16 measurable requirements (R1 to R16) with targets, verification and a status column that marks what is not met.
- `docs/02-concept.md` (WLS-PRC-001 v0.2): how it works, numbered components, first-order numbers with assumptions, design choices, safety section, open questions.
- `cad/src/concept_media.py`: massing model of a 150 mm borehole with an existing pump and riser (grey, not in kit), the WellSense parts in color with BOM numbers, and the FieldNode core on a post. The hero is re-rendered with the soil cut open; the cutaway is a broken section (wellhead and lower borehole side by side) so the 24 mm probe is readable. The borehole is shortened for display and captions say so.
- `media/`: `hero.png`, `concept-blueprint.png`, `.pdf` and `.svg`, `exploded.png` (callouts 1 to 10), `cutaway.png`, `flow.png` (data flow, estimated values), `model.glb` and `viewer.html`. Temporary `_views*` folders are removed by the script.
- `bom/bom.csv`: 12 rows with indicative prices, rows 1 to 10 matching the exploded view; `bom/bom-notes.md` explains what is and is not in the per-well cost.
- `README.md`: hero and links line, concept rationale, burning platform, where it could be used (by industry and by country or region), what sparked the idea, and updated concept, components and safety.
- `docs/pdf/`: branded PDFs of the three controlled documents.
- `project.yaml`: unchanged. The pitch and problem remain accurate.

### Key results (estimates, to be checked at TRL 3)

| Quantity | Estimate | Requirement |
| --- | --- | --- |
| Range | 0 to 10 m of water (98 kPa) | R1 met |
| Resolution | about 0.5 mm | R3 met |
| Datasheet accuracy | about ±50 mm (0.5 % of full scale) | **R4 (±20 mm) not met** |
| Sensor energy | about 18 mWh a day at 15 min, about 0.6 % of FieldNode's sensor budget | R8 met |
| Storage | about 0.3 MB a year | R7 met |
| WellSense parts per well (30 m) | about $170 | R12 met with FieldNode counted separately |
| Complete logger with FieldNode core | about $296 | **Over the $180 budget** |
| Depth-dependent cost | about $1.80 per metre | |

Requirements not met or at risk:

- **R4 accuracy not met:** about ±50 mm on datasheet against ±20 mm; needs a 0.25 % sensor plus two-point field calibration, unverified.
- **R5 drift unverified and at risk:** long-term drift of low-cost transducers is not published.
- **R9 water safety not met on evidence:** drinking water certification of low-cost cable and seals is unknown.
- **R10 pump compatibility at risk:** fitting an access tube may require pulling the pump.
- **R12 not met if the FieldNode core is counted** in the WellSense budget.
- **R16 tamper resistance at risk:** the cable run from wellhead to post is exposed in the concept.
- R11 and R13 are unverified (installation trial and dashboard not started).

### Proposed, awaiting Amish (status updated 2026-09-25: items 1 to 7 decided; 8 and 9 still open)

1. **Budget treatment of FieldNode.** Options: (a) count the FieldNode core in the FieldNode repo and hold WellSense to $180 for its own parts (about $170 now); (b) raise `budget_usd` to about $300 for a complete logger; (c) cut cost with a battery-only node or cheaper transducer. Recommendation: (a), with the complete cost stated in the README as done here. `budget_usd` is unchanged. **Decided by Amish, 2026-09-25: go with recommendation** (WLS-DDR-002).
2. **Sensor type.** Option A: vented 4 to 20 mA gauge transducer (proposed; simple, no compensation, needs desiccant care). Option B: sealed absolute sensor with RS-485 and surface barometric compensation (no vent; adds error and a digital probe). Recommendation: A for the first build, with B kept as a variant. **Decided by Amish, 2026-09-25: go with recommendation** (WLS-DDR-002).
3. **Range.** 0 to 10 m (recommended; better resolution and accuracy) or 0 to 20 m for wells with large pumping drawdown. **Decided by Amish, 2026-09-25: go with recommendation** (WLS-DDR-002).
4. **Access tube** fitted wherever a pump shares the casing (recommended), versus hanging the probe freely where there is no pump. **Decided by Amish, 2026-09-25: go with recommendation** (WLS-DDR-002).
5. **Default interval** of 15 min, with 1 min during pumping tests. **Decided by Amish, 2026-09-25: go with recommendation** (WLS-DDR-002).
6. **Manual tape check** each quarter as part of the method, with one shared tape per community or partner. **Decided by Amish, 2026-09-25: go with recommendation** (WLS-DDR-002).
7. **Data ownership:** levels only, community controls sharing, CSV export. **Decided by Amish, 2026-09-25: go with recommendation** (WLS-DDR-002).
8. **First partner and region** for co-design (an Indian farmer group, an African handpump programme, or a US groundwater agency).
9. **Battery-only FieldNode variant** without the panel, given the very small load; to be discussed with the FieldNode project, not changed here.

### Safety concerns

- Contamination of a drinking water well by the probe, cable, tube or an unsealed wellhead.
- Mains-powered submersible pumps at the wellhead; isolation and lock-off before work.
- Open wells as fall and drowning hazards, especially for children.
- Lithium iron phosphate cell in the FieldNode core.
- Heavy cable and probe running away into the well during installation.

### Problems and notes

- The web search budget for this session ran out before searching; all citations were checked by fetching the source pages directly. Figures for community groundwater programmes in India (for example Atal Bhujal Yojana) and for Mexico could not be verified, so they were left out.
- The transducer and cable prices are estimates from general market knowledge, not quotes.
- The exploded view shows the tube cap (item 5) and probe (item 1) small at full-well scale; the cutaway shows both clearly.
- The legacy `cad/src/model.py` placeholder is untouched (TRL 3 work).

### Recommended next step

Review this note and the media, then decide items 1 to 3. If approved, run `/advance-trl3` to check accuracy, drift allowance, energy and cable load by calculation and produce the parametric model and drawing sheet.

## Session 2026-09-25: TRL 3

On 2026-09-25 Amish asked for this batch of repos to go through the usual process with the instruction "you know the drill, nothing gets past TRL 3". He has not reviewed this repo's TRL 2 items one by one, so every item that carried a recommendation is adopted as recommended for TRL 3 under Amish's 2026-09-25 instruction, open for his review. This session ran `/advance-trl3` on that basis and stopped at TRL 3.

### What was done

- `docs/decisions/0001-trl2-review-decisions.md` (WLS-DDR-001 v0.1, status proposed): eight items adopted as recommended for TRL 3, open for Amish's review (D1 to D8), and two left open (O1, O2).
- `docs/04-calcs/01-sizing.md` (WLS-CAL-001 v0.1) and `docs/04-calcs/sizing.py`: range and resolution, loop supply and energy, accuracy error budget and drift, fit in the casing and hanging loads, storage and airtime, vent desiccant, installation time and cost, with a status for every requirement. The script imports the model, reads the BOM and `project.yaml`, prints every number the note quotes and writes `docs/04-calcs/results.csv`.
- `cad/src/model.py`: parametric build123d model (existing casing, pump and riser as grey context; access tube with slots and plug, probe, seal plate with glands, tube cap and hanger, vented cable, post and footing, junction box, interface board, barometric sensor, and a FieldNode core massing with dimensions copied from the FieldNode model). The borehole is shortened for display; the 30 m design case lives in `DESIGN`. Exports `cad/step/` and `cad/stl/` for `wellsense-assembly`, `wellsense-wellhead`, `wellsense-probe` and `wellsense-post`.
- `cad/src/sheets.py` and `cad/drawings/WLS-DWG-001.svg`, `.pdf`, `.png`: general arrangement at Rev P1, 1:25 above z = -700 mm, with a 1:5 detail of the probe zone, marked "CONCEPT, NOT FOR FABRICATION" and "PRELIMINARY, NOT FOR FABRICATION". WLS-DWG-001 was free because the concept blueprint is WLS-DWG-010.
- `bom/bom.csv` (13 lines, all priced with a supplier or supplier type) and `bom/bom-notes.md`: $187.60 for WellSense parts against the $180 budget.
- `cad/src/concept_media.py` now builds from the model; all of `media/` was re-rendered and every image checked; temporary `_views` folders are deleted by the script.
- WLS-PRB-001, WLS-PRC-001 and WLS-REQ-001 revised to v0.3; `README.md` (badge, TRL line, links, concept figures, key components) and `project.yaml` (`trl: 3`, `trl_target: 3`, evidence list) updated. The pitch and problem lines are unchanged, since no rewording was recommended. PDFs rebuilt in `docs/pdf/`.

### Requirement status (WLS-CAL-001, Table 3)

2 not met, 4 at risk, 3 not verifiable at TRL 3, 7 met.

| ID | Status | Key number |
| --- | --- | --- |
| R9 Water safety | **Not met** (no evidence) | No drinking water certificate in hand for low-cost cable, seals or probe |
| R12 Cost | **Not met** | $187.60 at 30 m against $180; met to 25.8 m; $313.60 with the FieldNode core |
| R4 Accuracy | At risk | 12.5 mm RSS, 27.1 mm worst case after two-point calibration (0.25 % class); 0.5 % class misses |
| R10 Pump compatibility | At risk | 1.3 mm radial clearance for a 24 mm probe in a 1 in tube; fitting may need the pump pulled |
| R15 Environment | At risk | FieldNode rated to 45 °C ambient against WellSense's 55 °C |
| R16 Tamper resistance | At risk | Cable exposed from the wellhead to the post |
| R5, R11, R13 | Not verifiable at TRL 3 | Drift unknown; install 120 min estimate at the limit; dashboard not started |
| R1, R2, R3, R6, R7, R8, R14 | Met | 98.07 kPa; factors 11.5 and 58 at 60 m; 0.52 mm; 1.12 MB a year; 38.2 mWh/day (1.6 %) |

Key numbers and changes from TRL 2: the FieldNode 12 V rail leaves the transducer 7.56 V against its 12 V minimum, so the interface board gains a 24 V boost (20.16 V at the probe); energy per reading rises from 0.66 J to 1.43 J and daily energy from 18 to 38.2 mWh; storage uses FieldNode's 32-byte record (1.12 MB a year, not 0.3 MB); parts rise from about $170 to $187.60.

### Decisions recorded (WLS-DDR-001)

Adopted as recommended for TRL 3 under Amish's 2026-09-25 instruction (now decided by Amish, 2026-09-25: go with recommendation; see WLS-DDR-002): D1 budget covers WellSense parts, FieldNode core costed in its own repo, `budget_usd` unchanged (R12 restated); D2 vented 4 to 20 mA transducer, absolute RS-485 sensor as a variant; D3 0 to 10 m range, 0 to 20 m variant; D4 access tube wherever a pump shares the casing; D5 15 min default, 1 min in pumping tests; D6 quarterly manual tape check with a shared tape; D7 levels only, community controls sharing, CSV export; D8 FieldNode as the core. Detail choices within D2 and D8 that Amish should see: 24 V boost and 3.3 V regulator on the interface board, 0.25 % class probe, two-point calibration by lifting the probe 1 m, a longer post for FieldNode's 1.75 m mounting height, and a footing concrete line.

### Still awaiting Amish (status updated 2026-09-25: items 3 to 7 decided; O1 and O2 still open)

1. **O1, first partner and region for co-design.** No preference stated.
2. **O2, battery-only FieldNode variant.** For discussion with the FieldNode project; no recommendation to adopt.
3. **New, cost at the design depth (R12).** Options: (a) keep $180 and state R12 at a 25 m design depth; (b) raise `budget_usd` to $190 to cover a 30 m design well, with $1.80 per metre beyond; (c) cost down, for example a cheaper probe (fails R4) or no access tube where there is no pump. Recommendation: (b), $190. Not applied; `budget_usd` stays at $180. **Decided by Amish, 2026-09-25: go with recommendation** (WLS-DDR-002).
4. **New, access tube bore (R10).** Options: (a) keep the 1 in tube and require a probe of 22 mm or less; (b) 1-1/4 in tube, which takes 24 to 28 mm probes but fits beside a centered riser only in 200 mm casing. Recommendation: (a). Not applied. **Decided by Amish, 2026-09-25: go with recommendation** (WLS-DDR-002).
5. **New, surface cable protection (R16).** Options: (a) galvanized conduit from the seal plate to the junction box, about $10 (estimate); (b) a buried conduit; (c) accept the exposed run. Recommendation: (a). Not applied and not in the BOM total. **Decided by Amish, 2026-09-25: go with recommendation** (WLS-DDR-002).
6. **New, hot-site rating (R15).** FieldNode is rated -20 to +45 °C ambient, and its own review recommends a sun shield for hot-climate sites. Options: (a) keep R15 at 55 °C and require the FieldNode shield at hot sites; (b) restate R15 to FieldNode's range. Recommendation: (a), following FieldNode's item 4. Not applied. **Decided by Amish, 2026-09-25: go with recommendation** (WLS-DDR-002).
7. **New, pumping-test uplinks.** A 1 min test batch uses 31.6 s a day at SF9, over public fair use. Recommendation: on a public network send every 30 min during a test; use a TwinKit gateway where possible. Not applied. **Decided by Amish, 2026-09-25: go with recommendation** (WLS-DDR-002).

### Cross-repo consistency

- FieldNode (read-only): cost $126.00, 12 V switched rail, M12 port with the candidate pinout (pin 1 rail, 2 and 4 data, 3 ground, 5 analog), 32-byte records in 16 MB flash, 90 % rail efficiency and the 100 mW allowance (115 mW ceiling) are all used as FieldNode states them. WellSense fits either allowance (1.6 % or 1.4 %).
- Conflict 1: WellSense R15 asks for 55 °C above-ground parts; FieldNode is rated to 45 °C ambient and misses its interior temperature target in hot sun (FND-CAL-001). Recorded here as item 6; FieldNode not edited.
- Conflict 2: the WellSense loop needs 24 V, which a FieldNode port does not offer; the boost sits on the WellSense interface board, so FieldNode needs no change. The FieldNode port pinout is still open (FND-DDR-001, O2); WellSense assumes I2C on port 1.
- TwinKit is assumed as the private gateway, as FieldNode does. No other shared component is used. No other repo was edited.

### Safety concerns

- Drinking water contamination by the probe, cable, tube, seal plate or an unsealed wellhead; R9 has no evidence yet. Disinfection and certified materials remain conditions of any installation.
- Mains-powered submersible pumps at the wellhead: isolate and lock off before work; keep logger wiring apart from the pump cable. WellSense itself is extra-low voltage (24 V boost).
- A tube lowered past an installed riser may snag the pump cable and damage its insulation; this is part of the R10 risk.
- Open wells as fall and drowning hazards; heavy cable and tube (up to 264 N of tube at 60 m) running away into the well during installation; the seal plate needs a tube clamp.
- Lithium iron phosphate cell and heat in the FieldNode core, as in the FieldNode review.

### Gaps and notes

- Citations: the TRL 2 note flagged no unchecked citations. It left out figures for Atal Bhujal Yojana and Mexico; one WebFetch attempt (World Bank press page 404; the scheme's site timed out) did not verify them, so they stay out.
- Transducer, cable, tube and board prices are estimates, not quotes. The accuracy budget's largest term (nonlinearity, 0.10 % of full scale) is a typical value.
- The kit's cutaway was not used (`cut=False`, as at TRL 2); `concept_media.py` renders its own broken section of the wellhead and the probe zone. The exploded view still shows the small wellhead parts (callouts 4, 5, 6 and 7) small at full-installation scale; the cutaway and drawing detail A show them clearly.
- Existing material beyond TRL 3: `build-log/README.md` (scaffold) is present, untouched and not extended. No test, build or firmware material exists.

### Recommended next step

TRL 4 is on hold by Amish's instruction; this repo stops at TRL 3. Amish's review is needed on items 3 to 7 above, on O1 and O2, and on the adopted items D1 to D8. For the record only, TRL 4 would need: a bench build of the interface board with a chosen transducer; a lab test report (TST, `environment: lab`) covering calibration and linearity against a water column, loop supply at the far end of 60 m of cable, temperature drift of the shunt and ADC, and probe fit in the chosen access tube; supplier drinking water certificates for wetted parts; and build log entries. None of this has been started.

## Session 2026-09-25: recommendations accepted

On 2026-09-25 Amish wrote: "i accept all your recommendations, go with them across all repos." Every item in this note and in WLS-DDR-001 that carried a recommendation is now decided by Amish, 2026-09-25: go with recommendation. The decisions and their effects are recorded in `docs/decisions/0002-recommendations-accepted.md` (WLS-DDR-002 v0.1).

### Decisions applied and what changed

| Decision | Before | After |
| --- | --- | --- |
| D1 to D8 (WLS-DDR-001) | Adopted for TRL 3, open for review | Decided; no design change beyond the items below |
| Cost at the design depth, option (b) | `budget_usd` $180; R12 at $180 | `budget_usd` $190 for a 30 m design well, $1.80 per metre beyond; R12 restated |
| Access tube bore, option (a) | 24 mm probe, 1.3 mm radial clearance in the 1 in tube | Probe 22 mm or less, 2.3 mm radial clearance; model, BOM line 1, R10 updated |
| Surface cable protection, option (a) | Cable exposed from the tube cap to the junction box; not in the BOM | Galvanized 1/2 in conduit, BOM line 14, $10.00; modeled and on the drawing |
| Hot-site rating, option (a) | R15 at risk on the FieldNode 45 °C rating | R15 kept at 55 °C with FieldNode's sun shield required at hot sites (48.5 to 52.2 °C inside at 45 °C, FND-CAL-001 v0.2); still at risk above 45 °C ambient |
| Pumping-test uplinks | 15 min batches, 31.6 s a day at SF9, over public fair use | Every 30 min on a public network: 22.7 s a day; 15 min on a TwinKit gateway; R6 text updated. Firmware on hold (TRL 4) |
| WellSense parts at 30 m | $187.60 ($7.60 over $180); $313.60 with FieldNode | $197.60 ($7.60 over $190); $323.60 with FieldNode; $331.60 with the hot-site shield |

Files changed: `project.yaml` (`budget_usd`, evidence list); `bom/bom.csv` (line 1 respecified, line 14 added) and `bom/bom-notes.md`; `cad/src/model.py` (probe 22 mm, `conduit` part) and re-exported STEP and STL; `cad/src/sheets.py` and WLS-DWG-001 at Rev P2; `cad/src/concept_media.py` and all of `media/` re-rendered (hero, blueprint, exploded and cutaway checked; `_views` folders deleted); `docs/04-calcs/sizing.py`, `results.csv` and WLS-CAL-001 v0.2; WLS-PRB-001 v0.4, WLS-PRC-001 v0.4, WLS-REQ-001 v0.4, WLS-DDR-001 v0.2, new WLS-DDR-002 v0.1; `README.md` (budget, concept figures, components, and a rewritten "What sparked the idea" citing the Andhra Pradesh Farmer Managed Groundwater Systems project). All PDFs rebuilt, and all generated files now carry designmolecule.com.

### Requirement status (WLS-CAL-001 v0.2, Table 3)

2 not met, 4 at risk, 3 not verifiable at TRL 3, 7 met.

| ID | Status | Key number |
| --- | --- | --- |
| R9 Water safety | **Not met** (no evidence) | No drinking water certificate in hand for low-cost cable, seals or probe |
| R12 Cost | **Not met** | $197.60 at 30 m against $190 ($187.60 without the conduit); met to 25.8 m |
| R4 Accuracy | At risk | 12.5 mm RSS, 27.1 mm worst case |
| R10 Pump compatibility | At risk | 2.3 mm radial clearance with a 22 mm probe; fitting a tube may need the pump pulled |
| R15 Environment | At risk | Shielded FieldNode core rated to 45 °C ambient against 55 °C |
| R16 Tamper resistance | At risk | Cable now in conduit; locking of the seal plate, tube cap and box not specified |
| R5, R11, R13 | Not verifiable at TRL 3 | Drift unknown; install 120 min estimate; dashboard not started |
| R1, R2, R3, R6, R7, R8, R14 | Met | R6 now with the 30 min public-network rule (22.7 s a day) |

### Still awaiting Amish

1. **O1, first partner and region for co-design.** No preference stated.
2. **O2, battery-only FieldNode variant.** No recommendation to adopt.
3. **New, N1, cost with the conduit.** The $190 budget and the $10.00 conduit together give $197.60 at 30 m. Options: (a) raise `budget_usd` to $200; (b) keep $190 and state R12 at a 25 m design depth; (c) keep $190 and fit the conduit only where livestock or tampering is likely. No option applied. **Decided by Amish, 2026-09-26: budget set to $200** (WLS-DDR-002).

### Cross-repo actions (other repos not edited)

- **FieldNode:** confirm how the shielded core behaves at 55 °C ambient, or state the limit, since WellSense R15 asks for 55 °C and FieldNode is rated to 45 °C ambient.
- **FieldNode:** WellSense now cites only the published 100 mW sensor allowance (no longer 115 mW), and uses the sun shield (BOM line 14, $8.00) at hot sites.
- **FieldNode:** the sensor port pinout (FND-DDR-001, O2) is still open; WellSense assumes I2C on port 1.

### TRL 4

TRL 4 remains on hold by Amish's instruction. `trl` and `trl_target` stay at 3. The firmware uplink rule, the interface board build, the probe fit test, supplier drinking water certificates and any purchasing are decided in principle where recommended but have not been started.

## Session 2026-09-26: budget approved

Amish wrote on 2026-09-26: "i approve all the budget items." Budget set to $200 to cover the priced BOM: decided by Amish, 2026-09-26. This closes N1.

- `project.yaml` `budget_usd` $190 to **$200**. The priced WellSense parts are unchanged at $197.60 at a 30 m probe depth (lines 1 to 7, 9, 10, 13 and 14; the FieldNode core and the shared tape stay outside the budget).
- R12 (cost): target $190 to $200; status **Not met to Met**, $2.40 under, and the budget now holds to a 31.3 m probe depth (was 25.8 m). Requirement status is now 1 not met (R9), 4 at risk (R4, R10, R15, R16), 3 not verifiable at TRL 3 (R5, R11, R13), 8 met.
- Files changed: `project.yaml`, `README.md`, WLS-PRB-001 v0.5, WLS-PRC-001 v0.5, WLS-REQ-001 v0.5, WLS-CAL-001 v0.3 (`sizing.py` and `results.csv` rerun; R12 status now computed from the budget), WLS-DDR-002 v0.2, `bom/bom-notes.md`, `cad/src/concept_media.py` (blueprint key figure); media and PDFs regenerated, temporary `media/_views*` folders deleted.
- Still awaiting Amish: O1 (co-design partner and region) and O2 (battery-only FieldNode variant). `trl: 3` and `trl_target: 3` are unchanged; TRL 4 remains on hold.

## Session 2026-09-26: product appearance model and photoreal renders

Amish chose WellSense for the first batch of product renders on 2026-09-26. This session adds an appearance model for photoreal renders; the renders themselves (`media/render-hero.png`, `media/render-exploded.png`, `media/render-detail.png`) are produced later by the orchestrator.

### What was done

- `cad/src/product_model.py` (new): `product_parts()` returns 84 parts (48 shell, 11 internal, 15 accessory, 10 context), each valid and tessellating, with material, BOM line, group and exploded-view offset. It also defines `TITLE` and three `RENDER_VIEWS`: hero (front right, about 30 deg, ground cut open), exploded (front right, about 28 deg) and detail (front right, about 14 deg, the logger on its post without the well).
- What the appearance model adds:
  - FieldNode core (line 8): filleted enclosure with side ribs, lid parting line and gasket, lid screws, clear lid window over the controller board, lit green status light, lid label, M12 port 1 with the WellSense lead plugged in and port 2 capped, whip antenna, 6 W panel with frame and cell grid on flat-bar legs, back plate with V-blocks and band clamps.
  - Junction box (line 6) and interface board (line 7): filleted IP66 box with side ribs, lid gasket and screws, clear lid window over the board (shunt, ADC and boost modules, inductor, terminal block, lit power light), WellSense label with the teal band, top cable gland, galvanized conduit hub and a clear desiccant breather showing orange indicating silica gel.
  - Barometric sensor (line 9): louvered housing on a small bracket.
  - Wellhead: teal split seal plate (line 4) with a split line, EPDM gasket, stainless bolts and glands; PVC tube cap with a stainless cable-grip hanger (line 5); galvanized conduit (line 14) with swept bends and a compression gland at the tube cap.
  - In the well: slotted access tube (line 3) with an end plug, shown in half section; the 22 mm stainless transducer (line 1) with a black nose guard, teal band and strain relief, on its vented cable (line 2).
  - Context: a compact block of ground cut open on the viewer's side (dry soil over the saturated aquifer), a small concrete apron, the steel casing in half section, the pump riser and the well water (clear).
- `README.md`: hero image now `media/render-hero.png`; an exploded render link added at the start of the links line.
- Self-check previews (matplotlib, clear parts left out) were reviewed for all three views; they are scratch files and are not in the repo.

### Differences from model.py (appearance model only)

Each is **Proposed, awaiting Amish**. `model.py`, the BOM, the drawing and the docs are unchanged.

1. **Render layout.** For a compact render the post is drawn 330 mm from the well instead of 750 mm, and everything on it 350 mm lower than installed (FieldNode base 1.40 m instead of 1.75 m, junction box center 0.90 m instead of 1.25 m); the relative positions on the post and all part sizes are unchanged. The borehole is shortened further than in `model.py` (probe tip 0.58 m and water 0.15 m below the ground, against a 30 m design depth), and the concrete apron is drawn 640 mm across instead of 1.2 m. The hero caption says the post is drawn closer and lower and the borehole is shortened. Recommendation: accept for renders only; the installed layout stays in `model.py` and WLS-DWG-001.
2. **Solar panel tilt direction.** `model.py` rotates the FieldNode panel by -40 deg about X, which turns its cells toward +Y (toward the post) with the high edge at the front. The FieldNode model (FND-DWG-001) tilts the panel toward -Y, the direction the node faces, and the product model follows FieldNode. Recommendation: correct the sign in `model.py` in the next media refresh, so the massing, the drawing and the renders agree with FieldNode.
3. **Conduit route at the tube cap.** `model.py` leaves the cap vertically for 30 mm and then runs a short diagonal up to the 720 mm route height; the product model rises vertically to 720 mm and turns with a 42 mm bend radius. End points, route height and the entry under the junction box are unchanged. Recommendation: accept; a single bend is what a rigid conduit installer would fit.
4. **Seal plate gasket.** The lower 2.5 mm of the 25 mm seal plate is drawn as the EPDM gasket, so the plate top stays at 475 mm. Recommendation: accept as appearance only.
5. **Groups for the views.** The post, access tube and vented cable are drawn in two parts each; the lower post, footing, upper tube and upper cable are grouped with the context so the exploded view stays compact, and the probe is shown on the slotted bottom section. Recommendation: accept.

### Status

Appearance only: no tolerances, no fabrication detail, nothing past TRL 3. `trl: 3` and `trl_target: 3` are unchanged, and TRL 4 remains on hold. Still awaiting Amish: O1 (co-design partner and region), O2 (battery-only FieldNode variant) and the five render items above.

## Session 2026-09-27: owner decision applied

On 2026-09-27 Amish wrote: "resolve the challenges for ConePro, BridgePulse, Grainguard and WellSense." For WellSense this applies the recommendation for render item 2 of the 2026-09-26 session (solar panel tilt direction). Decided by Amish on 2026-09-27.

### What changed

- `cad/src/model.py`: `derived()` adds `panel_rot_x` (+40 deg about X), and `build_parts()` rotates the FieldNode panel by it instead of -40 deg, so the cells face -Y (the way the node faces, as in FND-DWG-001) with the high edge at the back toward the post. The two panel legs now end at the panel underside 60 mm behind its center line so they still meet the tilted panel. Tilt angle, panel size and center, enclosure, post and every interface are unchanged; the overall height stays 2,206 mm and the FieldNode massing is one valid solid clear of the post.
- `cad/src/product_model.py`: the panel rotation now comes from `derived()["panel_rot_x"]` instead of its own opposite-sign rotation of `fnd_tilt`; the docstring and comment say so. The product geometry is unchanged (still 84 valid parts).
- `cad/src/sheets.py`: WLS-DWG-001 reissued at Rev P3 ("FieldNode panel tilt corrected to face -Y (WLS-DDR-003)", 2026-09-27).
- `docs/decisions/0003-panel-tilt-direction.md` (new, WLS-DDR-003 v0.1), listed in `project.yaml` `trl_evidence` and linked from `README.md`.
- Regenerated: `cad/step/*.step`, `cad/stl/*.stl`, `cad/drawings/WLS-DWG-001.*`, `media/hero.png`, `media/concept-blueprint.*`, `media/cutaway.png`, `media/exploded.png`, `media/flow.png`, `media/model.glb`, `media/viewer.html` and `docs/pdf/`.
- No other document stated the old tilt direction; the BOM, requirements and calculations are unaffected.

### Result

The massing model, the drawing and the appearance model now agree with FieldNode: the panel faces -Y in all three. Photoreal renders (`media/render-*.png`) do **not** need regenerating: the appearance model already drew the panel facing -Y, and no part in the hero, exploded or detail views changes shape, size or position.

### Still awaiting Amish

O1 (co-design partner and region), O2 (battery-only FieldNode variant) and render items 1, 3, 4 and 5 of the 2026-09-26 session remain "Proposed, awaiting Amish". `trl: 3` and `trl_target: 3` are unchanged, and TRL 4 remains on hold.

## Session 2026-09-27: kit 1.5.0 and image quality

- Kit 1.5.0 synced: STANDARDS v1.5 (sections 12 to 15: product renders, storefront images and image quality, public release, authorship and signing), `.kit/cards.py`, `.kit/image_qc.py`, `.kit/release_gate.py`, issue templates, and the `/render-product` and `/release` commands. `CLAUDE.md` now matches `.kit/CLAUDE.md`.
- Every `media/render-*.png` recaptioned from its original render with the new layout: the title, concept label and repository sit in a band above the render and the view note in a band below it, each line wrapped to the image width, so no text overlaps other text or the render or runs off the image. `media/card.png` and `media/social-preview.png` regenerated with the same rules.
- `python .kit/image_qc.py` and `python .kit/release_gate.py` pass. trl stays 3.

## Session 2026-10-02: kit 1.7.0, design for construction and prototype build plan

Kit 1.7.0 installed (`.kit/`, `.claude/commands/`; `CLAUDE.md` now matches `.kit/CLAUDE.md`). Following Amish's 2026-09-30 instruction ("If you are realising that the design cannot be built as per concept - fix the design assumptions to match and be physically feasible as you draw the illustrations"), the model was checked with build123d and made constructable, and the prototype build plan and the design decisions register were written. TRL stays 3; nothing was built or tested.

### Design changes made for construction (WLS-DDR-004, open for Amish's review)

| # | Change |
| --- | --- |
| P1 | FieldNode core is now FieldNode's constructable design on its own V-blocks and bands, geometry vendored from the FieldNode model (`cad/vendor/`); WellSense uses sensor port A (the massing floated 17.9 mm off the post). |
| P2 | Junction box on a 140 x 530 x 3 mm aluminium plate with two V-blocks and two band clamps through slots; box held by its maker's four lugs (it was drawn into the post, overlapping it by 602 mm³). |
| P3 | Junction box hollow with moulded bosses; printed internal plate carrying the interface modules and a terminal strip; four entries in the floor (hub, M16 gland, M12 gland, breather). |
| P4 | Barometric housing screwed to the plate below the box, lead through the M12 gland (it floated beside the post). |
| P5 | Rigid conduit with one 100 mm radius bend, a hub and two spacer saddles; 0.3 m flexible tail to the tube cap; 1.1 m service loop in the box so the probe can be lifted 1 m for calibration (the conduit was a solid rod with mitred corners fixed to the cap). |
| P6 | Split seal plate: two 20 mm HDPE halves with spigot half rings, EPDM gasket and wraps, a rim band; adds a split hole for the pump's power cable. |
| P7 | Split shaft collar on the tube, resting on the seal plate, carries the tube (264 N at 60 m). |
| P8 | Tube cap: slip cap (not glued) with a conduit connector, an M5 cross bolt and a cable support grip that carries the probe. |
| P9 | Access tube drilled with ten rings of 8 mm holes instead of lengthwise slots; bought slip cap with a drain hole on the bottom. |
| P10 | New FieldNode lead with an M12 plug through a gland in the box floor with a drip loop (BOM line 15). |
| P11 | Push-in cap on the post. |

The model now runs 99 constructability checks (`python cad/src/model.py --check`): all pass.

### What was done

- `cad/src/model.py`: rewritten as components (`build_components`) with the changes above and the checks; `cad/vendor/fieldnode-node.step` and `fieldnode-bands.step` exported read-only from the approved FieldNode model; STEP and STL regenerated.
- `bom/bom.csv`: lines 2 to 10 and 14 respecified or repriced, line 15 added; `bom/bom-notes.md` rewritten.
- `docs/04-calcs/sizing.py` and WLS-CAL-001 v0.4: surface cable run 2.7 m (loop margin still 8.16 V), new load-path checks [D5] collar on HDPE 0.24 MPa and [D6] cross bolt on the cap walls 0.79 MPa, cost against the value-engineering target.
- `cad/drawings/WLS-DWG-001` Rev P5 (`cad/src/sheets.py`); making sketches WLS-DWG-101 to 109.
- `cad/src/build_plan_media.py`: overview, 9 making sketches, 3 hole layouts (plate, box floor, seal plate), 9 joint pictures (joints 6 to 8 as true 2D sections), 17 assembly step pictures and a block-level wiring diagram, in `docs/05-build-plan/` and `cad/drawings/`.
- `docs/05-build-plan.md` (WLS-BLD-001 v0.1), `docs/06-design-decisions.md` (WLS-DEC-001 v0.1), `docs/decisions/0004-design-for-construction.md` (WLS-DDR-004 v0.1, Draft).
- WLS-REQ-001 v0.6 and WLS-PRC-001 v0.6 updated; `project.yaml` (`design_state: constructable`, evidence list); `README.md` (links line, "Building the prototype" section, key components, value-engineering wording).
- Concept media regenerated from the model (`python cad/src/concept_media.py`); PDFs rebuilt for every controlled document changed.

### Key results

- Value-engineering target: USD 200. Estimated cost of the constructable design: USD 244.40 at a 30 m probe depth (USD 44.40 over the target); $383.40 with the FieldNode core ($139.00, FND-CAL-001 v0.3). The register lists savings worth trying.
- Requirement status: 1 not met (R9, no drinking-water certificates), 4 at risk (R4, R10, R15, R16), 3 not verifiable at TRL 3 (R5, R11, R13), 7 met, R12 over its value-engineering target.

### Proposed, awaiting Amish

All open items are in the design decisions register, `docs/06-design-decisions.md`: review of WLS-DDR-004 (P1 to P11); locking of the wellhead and box (R16; recommendation: security screw on the rim band, padlock through the cross bolt, hasp kit on the box); first partner and region (O1); battery-only FieldNode (O2); FieldNode port pinout and 55 °C rating (FieldNode decisions); keeping the vendored FieldNode geometry up to date; render items 1 and 5.

### Render items (made on Amish's Mac)

The photoreal renders and storefront images need regenerating with Blender from the appearance model; see the 2026-10-02 section "Approved follow-ups carried out", which brings the appearance model and render scenes up to date.

### Safety

Unchanged hazards (drinking water contamination, mains-powered pumps, open wells, lithium cell in the FieldNode core, cable and tube running away during lowering) are carried as safety stops S1 to S8 in the build plan. New: the seal plate now carries the tube's weight through a friction collar, whose grip rating must be confirmed at purchase.

### Recommended next step

Amish reviews WLS-DDR-004 and the register. TRL 4 remains on hold; if approved, TRL 4 would build this plan and record the first checks of WLS-BLD-001 section 5 in a test report.

## Session 2026-10-02: open decisions decided

Amish, 2026-10-02: "APPROVED: The open decisions from the last wave (TremorTrace to ZeerBox) came in after the review and aren't on the page either." This approves the recommendation written for each open decision in the design decisions register (WLS-DEC-001), as he did for the other 555 open decisions ("i approve your recommendations for all 555 open decisions."). trl stays 3; no build or test work was done, and the model, BOM quantities and prices, and pictures are unchanged.

### Decisions recorded

Nine decisions, all moved to Decisions made in WLS-DEC-001, dated 2026-10-02:

1. Design for construction accepted: the changes P1 to P11 of WLS-DDR-004, as made.
2. Locking (R16): option (a) is fitted on the prototype from the start: a security-head screw on the rim band, a padlock through the cross bolt's head and a padlockable hasp kit on the junction box; the lockable steel wellhead cover is used at sites where the first site visit shows open access or livestock.
3. First partner and region: a participatory groundwater management group in India that works with farmer groups on shared aquifers; the first candidate to approach is ACWADAM in Pune, with its well sizes setting the design well and the FieldNode core at its sites on the IN865 band.
4. Battery-only FieldNode variant: the standard FieldNode core with its panel is kept; no battery-only variant is asked of FieldNode until a site shows the panel cannot be placed.
5. FieldNode sensor port pinout: FieldNode's proposed standard pinout is signed off for port A (pin 1 switched rail, pin 2 data A, pin 3 ground, pin 4 data B, pin 5 analog), with data A and B carrying I2C; the switched rail voltage is confirmed against the boost module input.
6. FieldNode core above 45 °C: R15 stays at 55 °C, as decided on 2026-09-25 (WLS-DDR-002, A12); the FieldNode project is asked to confirm the shielded core at 55 °C ambient, and until it does WellSense is not sited where the design maximum exceeds 45 °C.
7. FieldNode geometry in `cad/vendor/`: kept as a copy and re-exported whenever FieldNode's general arrangement is revised, as a line in the review checklist.
8. Photoreal render layout: the post drawn closer to the well and lower than installed is accepted, for renders only.
9. Exploded render: grouping the post, tube and cable together is accepted.

### Documents changed

- `docs/06-design-decisions.md` (WLS-DEC-001 v0.2): open decisions moved to Decisions made.
- `docs/decisions/0004-design-for-construction.md` (WLS-DDR-004 v0.2): acceptance recorded in the status line; A1 and A2 decided (record stays Draft).
- `docs/decisions/0001-trl2-review-decisions.md` (WLS-DDR-001 v0.3) and `docs/decisions/0002-recommendations-accepted.md` (WLS-DDR-002 v0.3): O1 and O2 recorded as decided.
- `docs/01-problem.md` (WLS-PRB-001 v0.6): partner and region answered.
- `docs/02-concept.md` (WLS-PRC-001 v0.7): pinout, battery-only, hot-site, locking and partner points.
- `docs/03-requirements.md` (WLS-REQ-001 v0.7): R15 and R16 notes; no status changed.

### Follow-up actions to carry approved decisions into the design

1. Decision 2 (model): Model the security-head screw on the rim band, the padlock through the tube cap's cross bolt and the padlockable hasp kit on the junction box, with clearance checks.
2. Decision 2 (BOM): Add the security-head screw and bit, two padlocks and the hasp kit to the BOM with a price basis.
3. Decision 2 (calculations): Re-run the cost (R12) and restate R16's status in WLS-CAL-001 once the locking parts are priced and modelled.
4. Decision 2 (pictures): Show the locks in the general arrangement, the wellhead and junction box build plan pictures and a locking step in the build plan.
5. Decision 5 (pictures): Redraw the FieldNode lead wiring (build plan section 3.5.1) to FieldNode's standard pinout, with I2C on pins 2 and 4 and the rail on pin 1.
6. Decision 3 (docs): Approach ACWADAM in Pune for the design well sizes and the first sites; record IN865 for the FieldNode core at those sites as a cross-repo note to FieldNode.
7. Decisions 5 and 6 (docs): Cross-repo: send WellSense's sign-off of the standard pinout to FieldNode, with the request to confirm the switched rail voltage and the shielded core at 55 °C ambient.

### Points found in the review

- Item 5 is no longer only a FieldNode decision: FieldNode decided its proposed standard pinout on 2026-10-02 and is waiting for adopting projects to sign it off.
- Item 3 puts the first WellSense site outside North America, so the FieldNode core there uses IN865 rather than FieldNode's default US915 (a cross-repo point for FieldNode).
- Item 6 overlaps a decision already made: on 2026-09-25 Amish kept R15 at 55 °C with FieldNode's sun shield at hot sites (WLS-DDR-002, A12); the open point is only FieldNode's confirmation at 55 °C.
- BOM line 8 prices the FieldNode core at USD 139.00 (its constructable design) while other repos still quote USD 126.00.

## Session 2026-10-02: approved follow-ups carried out

Amish, 2026-10-02: "497 follow-up actions that need CAD, drawing, picture, BOM or calculation work ... APPROVED CHANGES, COMPLETE THESE", and the product renders are to be redone afterwards. trl stays 3; nothing was built or tested.

### Follow-ups

| # | Follow-up | Result |
| --- | --- | --- |
| 1 | Model the locks, with clearance checks | Done. `cad/src/model.py`: security-head screw on the rim band housing; the cross bolt is now an M5 eye bolt with a padlock hung through its eye; hasp tabs on the box body and lid with a padlock through both holes. 19 checks added (118 of 118 pass), including that each shackle passes through its eye or holes and stays clear of every neighbour. STEP and STL regenerated. |
| 2 | Add the locks to the BOM with a price basis | Done. Line 16 added at $16.50 (screw $1.00, bit $2.50, two padlocks $9.00, hasp kit $4.00, marketplace listing prices) and line 5 repriced to $11.50 for the eye bolt (+$1.50). |
| 3 | Re-run R12 and restate R16 | Done. WLS-CAL-001 v0.5: R12 over the target by $62.40 (was $44.40); R16 restated from At risk to Met on design review, with the limit that the cap can still be lifted off the tube and the steel wellhead cover is what stops that at exposed sites; installation estimate 125 min (5 min over the R11 limit), new check [D7]. |
| 4 | Show the locks in the general arrangement, build plan pictures and a locking step | Done. WLS-DWG-001 Rev P6; WLS-DWG-109 Rev P2; new joint pictures 10 (cap padlock) and 11 (hasp) and step 18 (fit the padlocks); overview, step 14 and step 16 redrawn; build plan WLS-BLD-001 v0.2. |
| 5 | Redraw the FieldNode lead wiring to FieldNode's standard pinout | Done. The wiring picture names port A pins 1 (rail), 2 (data A, SDA), 3 (ground), 4 (data B, SCL) and 5 (analog, not used); build plan section 3.5.1 and the lead's parts line match. |
| 6 | Approach ACWADAM in Pune; record IN865 for the FieldNode core as a cross-repo note | Not done: outreach by Amish. The IN865 note for FieldNode is listed under Cross-repo actions. |
| 7 | Send the pinout sign-off to FieldNode with the 55 degC and rail-voltage requests | The WellSense side is done (the wiring is drawn to the standard pinout, and the 12 V switched rail feeds the boost module's 12 to 24 V input in WLS-CAL-001 [B1]); sending it is a cross-repo action, listed below. |

### Key results

- Value-engineering target: USD 200. Estimated cost of the constructable design: USD 262.40 (USD 62.40 over the target); USD 401.40 with the FieldNode core. `budget_usd` is unchanged. The repo records no mass figure, so none was updated.
- Requirement status: R16 At risk to Met (design review); R12 still over its target, now by $62.40; R11 still not verifiable, estimate 125 min. Counts: 1 not met, 3 at risk, 3 not verifiable at TRL 3, 8 met, R12 over its target.
- Honest limit of the cap lock: the padlock hung through the eye of the cross bolt stops the bolt being unscrewed, so the grip and probe cannot be freed, but a slip cap that lifts off for calibration can still be lifted. At sites with open access or livestock the lockable steel wellhead cover (decision 2) is what closes that.

### Pictures and models regenerated

- General arrangement WLS-DWG-001 Rev P6; making sketch WLS-DWG-109 Rev P2.
- Build plan: overview, step 14, step 16, step 18 (new), joint 10 and joint 11 (new), wiring.
- Concept media (hero, blueprint, cutaway, exploded, flow, model.glb and viewer) from the model.
- Appearance model `cad/src/product_model.py` brought into line with the constructable design: the plate, V-blocks, bands, lugs, hasp, padlocks, split seal plate with rim band, security screw and collar, slip cap with eye bolt, flexible tail, conduit hub, saddles, barometric housing on the plate, drilled tube with slip end cap and the lead come from the constructable parts in `cad/src/model.py`. Render scenes exported to `/home/claude/renders/wellsense`: hero, exploded and detail (one .npz and .json each, and `wellsense__jobs.json`). Photoreal renders, `media/card.png` and `media/social-preview.png` are for Amish's Mac.

### Proposed, awaiting Amish

- The rigid conduit in the render scene uses a 70 mm bend radius instead of 100 mm, because the junction box is drawn 350 mm lower than installed (decision 8 accepts the post layout for renders only). Appearance deviation for renders only.

### Documents changed

WLS-BLD-001 v0.2, WLS-CAL-001 v0.5, WLS-REQ-001 v0.8, WLS-PRC-001 v0.8, WLS-DEC-001 v0.3, WLS-DDR-004 v0.3; `bom/bom.csv`, `bom/bom-notes.md`, `README.md`.

### Cross-repo actions

- FieldNode: WellSense signs off the standard sensor port A pinout (pin 1 switched rail, 2 data A, 3 ground, 4 data B, 5 analog), with data A and B carrying I2C. Asked of FieldNode: confirm the switched rail voltage against the boost module input (12 V assumed in WLS-CAL-001 [B1]) and confirm the shielded core at 55 degC ambient (R15).
- FieldNode: record IN865 for the FieldNode core at the first sites, if ACWADAM (Pune) is approached.
- Any repo that quotes WellSense at $244.40 or $383.40 (parts or with the FieldNode core) should quote $262.40 and $401.40.

### Safety

No new hazard. The padlocks and security-head screw keep people out of the wellhead and the box; they do not make an open well safe, and the pump isolation and lock-off stops S1 to S8 are unchanged.

### Recommended next step

Amish reviews the cap lock limit (the cap can be lifted) and renders the scenes on his Mac. TRL 4 remains on hold.

## 2026-10-02: photoreal renders redone on the constructable design

Rendered with Blender Cycles on Amish's Mac from the updated appearance model; captioned with `.kit/photo_caption.py`; `media/card.png` and `media/social-preview.png` regenerated with `.kit/cards.py`. Views: hero, exploded, detail. image_qc passes. Appearance deviations are those logged above as proposed, awaiting Amish.

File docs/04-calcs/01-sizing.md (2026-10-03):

---
doc_id: WLS-CAL-001
title: WellSense sizing calculations
project: WellSense
doc_type: Calculation
version: "0.5"
status: Draft
date: '2026-10-02'
author: Amish Chadha
license: CERN-OHL-S-2.0
revisions:
- version: "0.1"
  date: '2026-09-25'
  author: Amish Chadha
  change: First issue for TRL 3 (range and resolution, loop supply and energy, accuracy and drift, fit in the well and hanging loads, storage and airtime, vent desiccant, installation, cost)
- version: "0.2"
  date: '2026-09-25'
  author: Amish Chadha
  change: Recommendations accepted by Amish (DDR-002)
- version: "0.3"
  date: '2026-09-26'
  author: Amish Chadha
  change: Budget approved by Amish; budget $200 covers the priced BOM, so R12 is met and holds to 31.3 m (WLS-DDR-002 v0.2)
- version: "0.4"
  date: '2026-10-02'
  author: Amish Chadha
  change: Constructable design (WLS-DDR-004); surface cable run, wellhead load paths and cost recomputed; budget treated as a value-engineering target
- version: "0.5"
  date: '2026-10-02'
  author: Amish Chadha
  change: Locks added under WLS-DEC-001 decision 2; cost, R16 status and installation time recomputed; new check [D7]
---

# WellSense sizing calculations

On paper, WellSense meets eight of its sixteen requirements, has three at risk, misses one, leaves three that only field work can settle and is over its value-engineering target on cost. The miss is water safety. With the decisions of WLS-DDR-002 applied (a 22 mm probe in the 1 in tube, a galvanized conduit over the surface cable and a 30 min uplink rule for pumping tests on public networks) and the design made constructable under WLS-DDR-004, the WellSense parts cost $262.40 at the 30 m design depth, locks included. Value-engineering target: USD 200 (`budget_usd`, a hypothetical control target, not a limit). Estimated cost of the constructable design: USD 262.40 (USD 62.40 over the target). No drinking water certificate is in hand for the low-cost cable, seal or probe (R9). The calculations changed the interface: the FieldNode 12 V rail cannot drive a 4 to 20 mA loop through a 150 Ω shunt and 62 m of cable to the transducer's 12 V minimum (it delivers 7.56 V), so the interface board gains a 24 V boost. That doubles the sensor energy of the TRL 2 estimate to 38.2 mWh a day, still only 1.6 % of the FieldNode allowance. Accuracy (R4) is at risk rather than not met: a 0.25 % class probe after a two-point field calibration against a manual tape gives 12.5 mm by root sum square against the ±20 mm target, but 27.1 mm if every term adds. Every number in this note is printed by `docs/04-calcs/sizing.py`; the tag in brackets, for example [B3], is the line of that script's output that carries it.

> **Safety:** These are first-principles estimates for a paper proof of concept. They do not show that anything lowered into a well is safe for drinking water, that the wellhead is sealed, or that work at a well with a mains-powered pump is safe. See WLS-PRC-001, Safety.

## Scope and method

The note checks every requirement in WLS-REQ-001 v0.4 against the design in WLS-PRC-001 v0.4 and the parametric model `cad/src/model.py`. The script imports the model's `PARAMS`, `DESIGN` and `derived()`, so the tube, probe, casing, post and seal plate used here are the ones in the STEP files and in drawing WLS-DWG-001. It also reads `bom/bom.csv` and `budget_usd` in `project.yaml`. Run it from the repo root with `python docs/04-calcs/sizing.py`; it also writes `docs/04-calcs/results.csv`.

The design case is a 150 mm (6 in) borehole with a 4 in submersible pump on a 1-1/4 in riser, the probe hung 30 m below the top of the casing (up to 60 m for R2) in a 1 in PVC access tube, and a FieldNode core on a post 0.75 m from the well, reading every 15 min (DDR-001, D5).

## Assumptions

*Table 1. Main assumptions.*

| Area | Assumption | Basis |
| --- | --- | --- |
| Pressure | Water 1,000 kg/m³ nominal; standard gravity 9.80665 m/s² in the sensor's kPa calibration; local gravity from the WGS 84 formula | Physical constants |
| Loop | 150 Ω shunt; ADS1115 class 16-bit ADC at ±4.096 V; loop ceiling 22 mA; rail on 2 s per reading; FieldNode 12 V rail 5 % low, 90 % efficient; boost to 24 V at 85 %; transducer minimum supply 12 V; two 0.2 mm² copper cores at 0.087 Ω/m; 0.3 V reverse-polarity diode | BOM lines 1, 2 and 7; FND-CAL-001 for the rail |
| Node | Controller awake 2 s at 8 mA, 3.3 V, per reading; published sensor allowance 100 mW; 32-byte stored record; 16 MB flash; 20-byte uplink | FND-CAL-001 v0.2 |
| Accuracy | After a two-point calibration: nonlinearity, hysteresis and repeatability 0.10 % of full scale (0.25 % class) or 0.20 % (0.5 % class); probe thermal effect 0.02 % of full scale per K over 2 K of groundwater change; shunt 10 ppm/K and ADC gain 7 ppm/K over 30 K in the junction box; tape reading ±3 mm (0.01 ft) | Typical datasheet ranges and USGS tape practice; not measured |
| Mechanical | Vented cable 0.055 kg/m, probe 0.25 kg, strain member 400 N; PVC 1,400 kg/m³ and 48 MPa tensile | Typical catalogue values |
| Fit | 3 mm running clearance; 2 mm radial clearance for a probe in its tube; riser coupling OD 40 mm (1 in riser in 100 mm casing), 52 mm (1-1/4 in, in 125 and 150 mm casing), 73 mm (2 in, in 200 mm casing); tube coupling OD 40 mm (1 in) and 50 mm (1-1/4 in) | Common pipe sizes |
| Desiccant | 1.4 L of air in the junction box, 1.5 mm vent capillary, 30 K daily swing, 24 g/m³ humid air, 10 g of silica gel with 20 % usable uptake | Screening values |

## A. Range and resolution (R1, R3)

- **Range.** Full scale is 10 m of water, 98.07 kPa; 1 kPa is 102.0 mm of water [A1]. R1 is met by the 0 to 10 m transducer (DDR-001, D3).
- **Resolution.** The 150 Ω shunt turns 4 to 20 mA into 0.60 to 3.00 V. At 125 µV per ADC step that is 19,200 steps, or 0.52 mm per step over 10 m, and 1.04 mm on the 0 to 20 m variant [A2]. R3 is met; the 20 m variant just misses 1 mm.
- **Placement.** With the probe at least 1 m below the lowest pumping level, seasonal swing plus pumping drawdown of up to 9 m stays in range with 1 m of headroom; larger swings need the 0 to 20 m variant [A3].

## B. Loop supply and energy (R8)

- **The 12 V rail cannot drive the loop.** At 22 mA through 63 m of cable (10.9 Ω; 60 m down the well plus the 2.7 m surface run of WLS-DDR-004) and the shunt, the transducer gets 7.56 V from a rail 5 % low, 4.44 V short of its 12 V minimum. A 24 V boost on the interface board gives it 20.16 V, a margin of 8.16 V [B1]. The boost and a 3.3 V regulator for the ADC and barometric sensor are added to BOM line 7 (+$2).
- **ADC protection.** A 25 mA fault puts 3.75 V on the shunt, above the ADC's 3.6 V limit at a 3.3 V supply, so the ADC input needs a series resistor [B1b].
- **Energy.** Each reading takes 1.38 J in the loop (24 V at 22 mA for 2 s, through the boost and the FieldNode rail) plus 0.053 J for the controller, 1.43 J in all [B2]. At 15 min that is 38.2 mWh a day, 1.59 mW on average: 1.6 % of FieldNode's published 100 mW allowance [B3]. **R8 is met.** During a pumping test at 1 min the load is 0.573 Wh a day, 23.9 mW, or 24 % of the allowance [B4]. The TRL 2 estimate, 0.66 J and 18 mWh a day, assumed the loop ran straight from the 12 V rail [B5].

## C. Accuracy and drift (R4, R5)

- **Gravity and density.** Converting kPa to head with standard gravity misreads 10 m by +27 mm at the equator, so firmware uses local gravity and the calibration absorbs the rest [C1]. Water density falls 0.29 % from 4 to 25 °C, 29 mm at 10 m [C2]; groundwater temperature at one well changes little, so firmware uses a fixed site density set at installation.
- **Calibration method.** At installation the caretaker reads depth to water with the tape, then lifts the probe a measured 1 m in its tube and reads again. The two points fix offset and span, removing the datasheet offset and span error, the gravity error and the cable length error. What remains is in Table 2.

*Table 2. Error budget at full scale after a two-point calibration, 0.25 % class probe [C3.1] to [C4].*

| Term | Error |
| --- | --- |
| Nonlinearity, hysteresis and repeatability | 10.0 mm |
| Probe thermal effect, 2 K | 4.0 mm |
| Density at a fixed site value, 2 K | 3.2 mm |
| Shunt drift, 30 K | 3.8 mm |
| ADC gain drift, 30 K | 2.6 mm |
| ADC resolution | 0.5 mm |
| Manual tape reference | 3.0 mm |
| Root sum square | 12.5 mm |
| Worst-case sum | 27.1 mm |

- **R4 is at risk.** The root sum square meets ±20 mm; the worst-case sum does not, and the nonlinearity figure, the largest term, is a typical value rather than a measured one [C4]. A 0.5 % class probe gives 21.4 mm root sum square and 37.1 mm worst case, so it does not meet R4 even after calibration [C5]; BOM line 1 is therefore specified in the 0.25 % class. Without field calibration the datasheet figures are 50 mm and 25 mm [C6]. An absolute sensor without barometric compensation would read weather as water level, ±306 mm for ±3 kPa [C7], which is why the vented design was adopted (DDR-001, D2).
- **R5 cannot be verified at TRL 3.** A quarterly tape check leaves at most 5 mm of a 20 mm-a-year drift uncorrected between checks, close to the 3 mm tape uncertainty [C8]. The real drift of low-cost probes is unknown.

## D. Fit in the well and hanging loads (R2, R10)

- **Model.** In the 150 mm design well the tube sits 32.2 mm clear of the riser and 18.3 mm from the casing wall. Under WLS-DDR-002 the 1 in tube is kept and the probe body is limited to 22 mm, which gives 2.3 mm radial clearance in the 26.6 mm bore of 1 in Sch 40 PVC [D1], against 1.3 mm for the 24 mm probe of v0.1. Joints must be flush inside so a solvent bead does not catch the probe.
- **Tube size.** The 1 in tube takes probes up to 22 mm with 2 mm of radial clearance and fits beside a centered riser in 150 and 200 mm casings, and beside a riser against the wall in all four sizes checked. A 1-1/4 in tube takes probes up to 28 mm but fits beside a centered riser only in 200 mm casing [D2]. The tube ends above the pump, so the pump body does not limit the fit.
- **R10 is at risk.** The tube and a 22 mm probe fit the design well, but lowering a tube past the riser, cable ties and pump cable of an installed pump may snag them or need the pump pulled. Only an installation trial can settle it.
- **Loads.** Cable and probe hanging 60 m in air weigh 35 N against a 400 N strain member, a factor of 11.5 [D3]. Sixty metres of tube hanging dry weigh 264 N, a stress of 0.82 MPa against 48 MPa, a factor of 58; a split collar on the tube carries the 264 N onto the seal plate [D4]. **R2 is met.**
- **Load paths of the constructable wellhead (WLS-DDR-004).** The collar bears on the 20 mm HDPE seal plate at 0.24 MPa, about a factor of 82 under HDPE's compressive strength; the collar's grip on the tube is its maker's rating, to be confirmed at purchase [D5]. The probe and cable (35 N at 60 m) hang from a cable support grip on an M5 eye bolt (the cross bolt) through the tube cap; the bolt bears on the two 4.4 mm cap walls at 0.79 MPa against about 50 MPa for PVC, and the cap sits on the tube end, so the load reaches the collar through the tube [D6]. The padlock hung on the eye adds 1.0 N (0.81 MPa on the cap walls); it stops the eye bolt being unscrewed but not the cap being lifted off the tube, so exposed sites need the lockable steel wellhead cover [D7].

## E. Storage and airtime (R6, R7)

- **R7 is met.** A year of 15 min readings is 35,040 records of 32 bytes, 1.12 MB, 6.7 % of the FieldNode's 16 MB flash [E1]. A 7-day pumping test at 1 min adds 0.32 MB [E2].
- **R6 is met.** The 15 min default and the 1 min test rate are firmware settings. At 1 min the readings are logged and sent 15 at a time in the normal 15 min uplink. That 38-byte batch takes 328.7 ms at SF9, 31.6 s a day, slightly over the 30 s a day fair use of a public network; on a private TwinKit gateway only the regional duty cycle applies [E3]. Under WLS-DDR-002, a test on a public network sends every 30 min instead: a 30-reading batch of 68 bytes takes 472.1 ms, 22.7 s a day, within fair use [E4]. On a private TwinKit gateway the 15 min batch is kept.

## F. Vent desiccant (maintenance)

The vent capillary holds 111 mL at 62.7 m. With the box and vent breathing 0.15 L a day at a 30 K swing, humid air carries at most 3.6 mg of water a day; 10 g of gel would last about 552 days even if the whole box breathed through it, a factor of 6.1 over the quarterly change [F1]. The quarterly desiccant change has ample margin, provided the box gaskets are intact.

## G. Installation (R11)

With an access tube already in place, ten steps from isolating the pump to fitting the padlocks are estimated at 125 min for two people, 5 min over the R11 limit once the locks are fitted, with the post footing set and cured on an earlier visit [G1]. **R11 cannot be verified at TRL 3**; only a timed installation can.

## H. Cost (R12)

- **BOM.** All 16 lines are priced. The design case uses 33 m of cable (30 m down the well and a 2.7 m surface run that includes a 1.1 m service loop in the junction box for the 1 m calibration lift) and 30.61 m of tube (31 m in the BOM) [H1].
- **R12, over the value-engineering target.** Value-engineering target: USD 200 (`budget_usd`, a hypothetical control target, not a limit). Estimated cost of the constructable design: USD 262.40 for lines 1 to 7, 9, 10 and 13 to 16 (USD 62.40 over the target); with the $139.00 FieldNode core (FND-CAL-001 v0.3) the complete logger is $401.40, and $410.40 at a hot site with FieldNode's $9.00 sun shield [H2]. Making the design constructable (WLS-DDR-004) repriced lines 4, 5, 6, 7, 10 and 14 and added line 15, the FieldNode lead; the concept total was $197.60 [H2c]. The locks decided on 2026-10-02 add $18.00: line 16 at $16.50 and $1.50 for the eye bolt in line 5 [H2d]. Without the $20.00 conduit set (line 14) the parts would be $242.40 [H2b]. The fixed parts alone are $208.40, so the target is not met at any depth. Cable and tube add $1.80 per metre of depth; at 60 m the parts cost $316.40, and without an access tube (no pump in the casing) $231.40 [H3]. Savings worth trying are listed in the design decisions register (WLS-DEC-001).

## L. Results against every requirement

*Table 3. Requirement status from this note [L].*

| ID | Requirement | Value | Target | Status |
| --- | --- | --- | --- | --- |
| R9 | Water safety | No drinking water certificate in hand for low-cost cable, seal or probe | Wetted parts 316 stainless or certified for drinking water; well sealed | **Not met** (no evidence) |
| R4 | Accuracy after field calibration | 12.5 mm RSS, 27.1 mm worst case (0.25 % class) | ±20 mm | **At risk** |
| R10 | Pump compatibility | 2.3 mm radial clearance with a 22 mm probe; tube may need the pump pulled | Own tube, no contact with pump, riser or cable | **At risk** |
| R15 | Environment | Probe IP68 on datasheet; FieldNode shield at hot sites gives 48.5 to 52.2 °C inside at 45 °C; FieldNode rated to 45 °C ambient | Above-ground parts IP65, -10 to 55 °C; FieldNode shield at hot sites | **At risk** |
| R16 | Tamper resistance | Cable in galvanized conduit from the tube cap to the box; by design review the seal plate (security-head screw), cross bolt (padlock on its eye) and junction box (hasp and padlock) are each lockable; lifting the cap at exposed sites needs the steel cover [D7] | Lockable; no exposed cable at reachable height | **Met** (design review) |
| R5 | Long-term drift | Unknown; a quarterly check leaves at most 5 mm | 20 mm a year or less | Not verifiable at TRL 3 |
| R11 | Installation | 125 min estimate with the locks fitted [G1] | 2 h or less with a tube in place | Not verifiable at TRL 3 |
| R13 | Data use | Dashboard not started | Level, drawdown, year-on-year, CSV | Not verifiable at TRL 3 |
| R1 | Range | 0 to 10 m, 98.07 kPa | 0 to 10 m; 0 to 20 m option | Met |
| R2 | Installation depth | Cable factor 11.5, tube factor 58 at 60 m | 60 m or more | Met |
| R3 | Resolution | 0.52 mm | 1 mm or better | Met |
| R6 | Reading interval | 15 min; 1 min logged, sent every 30 min on a public network (22.7 s/day) | 15 min; 1 min in tests | Met |
| R7 | Local storage | 1.12 MB a year, 6.7 % of flash | 1 year | Met |
| R8 | Energy | 38.2 mWh/day, 1.6 % of 100 mW | 5 % or less | Met |
| R12 | Cost | $262.40 at 30 m; $401.40 with FieldNode | Value-engineering target $200 for WellSense parts at 30 m | Over the target by $62.40 |
| R14 | Data ownership | Levels, time and well ID only | Community controls sharing | Met (by design) |

Counts: 1 not met, 3 at risk, 3 not verifiable at TRL 3, 8 met, and R12 over the value-engineering target.

## Checks against the TRL 2 figures

| TRL 2 claim (WLS-PRC-001 v0.2) | This note | Action |
| --- | --- | --- |
| Resolution about 0.5 mm | 0.52 mm | Stands |
| Datasheet accuracy about ±50 mm | 50 mm (0.5 %), 25 mm (0.25 %); 12.5 mm RSS after calibration | Precis and REQ updated; R4 now at risk |
| Energy about 0.66 J per reading, 18 mWh/day | 1.43 J and 38.2 mWh/day with the 24 V boost | Precis updated |
| About 0.6 % of a 2.8 Wh/day allowance | 1.6 % of 100 mW (2.4 Wh/day) | Precis updated |
| Storage about 0.3 MB a year at 8 bytes | 1.12 MB at FieldNode's 32-byte record | Precis and REQ updated |
| Parts about $170; about $296 with FieldNode | $187.60 and $313.60 in v0.1; $197.60 and $323.60 in v0.2 | Precis, README and REQ updated |
| Depth-dependent about $1.80 per metre | $1.80 per metre | Stands |
| 12 V rail powers the loop directly | Short by 4.44 V; 24 V boost needed | Precis and BOM updated |

## Changes in v0.2 (WLS-DDR-002)

| Item | v0.1 | v0.2 |
| --- | --- | --- |
| `budget_usd` | $180 | $190; $200 in v0.3 (approved by Amish, 2026-09-26) [H2] |
| Probe body and clearance | 24 mm, 1.3 mm radial | 22 mm maximum, 2.3 mm radial [D1] |
| Surface cable | Exposed from the tube cap to the box | Galvanized conduit, BOM line 14, $10.00 |
| WellSense parts at 30 m | $187.60 ($7.60 over $180) | $197.60 ($7.60 over $190; $2.40 under the $200 budget of v0.3) [H2] |
| Pumping test uplinks, public network | 15 min batches, 31.6 s/day | 30 min batches, 22.7 s/day [E4] |
| R15 hot sites | FieldNode 45 °C rating only | FieldNode shield required at hot sites (FND-DDR-002) |
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

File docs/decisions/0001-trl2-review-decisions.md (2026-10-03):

---
doc_id: WLS-DDR-001
title: WellSense TRL 2 review decisions
project: WellSense
doc_type: Design decision record
version: "0.3"
status: Draft
date: '2026-10-02'
author: Amish Chadha
license: CERN-OHL-S-2.0
revisions:
- version: "0.1"
  date: '2026-09-25'
  author: Amish Chadha
  change: Record the TRL 2 review recommendations adopted for TRL 3 work under Amish's 2026-09-25 instruction, and the items that remain open
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

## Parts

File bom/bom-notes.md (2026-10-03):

# BOM notes

All costs are indicative estimates in USD at quantity 1 (September 2026), not quotes. Every line is priced, with a supplier or supplier type. The total is compared with the value-engineering target, `budget_usd` in `project.yaml`, by `docs/04-calcs/sizing.py` (WLS-CAL-001, section H). `budget_usd` is a hypothetical control target that keeps the design on a value-engineering lens, not a spending limit (Amish, 2026-10-01).

- Rows 1 to 10 and 13 to 16 are numbered to match the parts in `cad/src/model.py` and the callouts in `media/exploded.png`. Rows 11 and 12 are not modeled. Row 16 (locking) is modelled as the security-head screw on the rim band (shown with row 4), the eye bolt and padlock on the tube cap (with row 5) and the hasp tabs and padlock on the junction box (with row 6).
- The design case is a probe 30 m below the top of the casing: 33 m of cable (30 m plus a 2.7 m surface run that includes a 1.1 m service loop in the junction box) and 31 m of access tube.
- Value-engineering target: USD 200. Estimated cost of the constructable design (rows 1 to 7, 9, 10 and 13 to 16): **USD 262.40** (USD 62.40 over the target); USD 244.40 before the locking parts of row 16 and the eye bolt of row 5 were added. The concept, before the design was made constructable, was $197.60.
- Changes for construction (WLS-DDR-004): row 4 becomes a split HDPE seal plate with spigot rings, EPDM gasket and wraps, a rim band and a tube collar (+$8.00); row 5 a drilled slip cap with a cross bolt and cable support grip (+$4.00); row 6 gains lugs and glands (+$6.00); row 7 a terminal strip and printed internal plate (+$1.00); row 10 a junction box plate, two V-blocks and a post cap (+$10.00); row 14 a flexible tail, spacer saddles and a hub (+$10.00); row 15, the FieldNode lead, is new (+$7.00); row 2 is 1 m longer (+$0.80).
- Row 8, the FieldNode core, is now FieldNode's constructable base node ($139.00 in FND-CAL-001 v0.3, was $126.00) and is costed in the FieldNode repo under WLS-DDR-001, D1. With it a complete logger is $401.40, and $410.40 at a hot site with FieldNode's $9.00 sun shield (FND-DDR-002).
- Locking (WLS-DEC-001, decision 2, 2026-10-02): row 16 is new (+$16.50: security-head screw $1.00 and bit $2.50, two keyed-alike padlocks at $4.50, hasp kit $4.00, all marketplace listing prices) and row 5 gains an eye bolt for a plain bolt (+$1.50), +$18.00 in all. The lockable steel wellhead cover for exposed sites is priced only when a site visit calls for it.
- Changes at TRL 3: row 1 specified in the 0.25 % class (+$5, to reach R4 after calibration); row 7 gains a 12 to 24 V boost and a 3.3 V regulator (+$2), because the FieldNode 12 V rail cannot drive the loop; rows 2 and 3 are priced per metre; row 10 is lengthened so the FieldNode core sits at 1.75 m (+$2); row 13, footing concrete, is new (+$6).
- Changes under WLS-DDR-002: row 1 limited to a 22 mm body (price assumed unchanged, to be confirmed); row 14, galvanized surface conduit, added (+$10.00).
- Row 11, the manual water level meter, is shared by a community or partner and is not in the per-well cost.
- The LoRaWAN gateway (TwinKit or a public network) is not included.
- Cable and access tube scale with probe depth: $1.80 per metre of depth together. Savings worth trying are listed in the design decisions register (`docs/06-design-decisions.md`).

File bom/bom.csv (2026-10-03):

item | qty | spec | supplier | unit_cost_usd | make_buy | notes
1 Pressure transducer | 1 | Submersible gauge (vented) level transducer, 0 to 10 m water (0 to 98 kPa), 4 to 20 mA two-wire, 12 to 30 V supply, 0.25 % full scale class, 316 stainless body 22 mm diameter or less (WLS-DDR-002), IP68 | Industrial sensor distributor or online marketplace | 50.00 | buy | Indicative price (estimate); 0.25 % class assumed about $5 above the 0.5 % class; 22 mm bodies are narrower than the common 26 to 28 mm class and the price is assumed unchanged | [' to be confirmed with suppliers; range and type adopted for TRL 3 (WLS-DDR-001 D2 and D3); wetted materials must be certified for drinking water (R9)']
2 Vented cable (per metre) | 33 | Vented polyurethane or polyethylene jacketed cable, two cores of 0.2 mm2 or more, aramid strain member rated 400 N or more, capillary vent tube, about 7 mm diameter | Supplied with the transducer or by the metre from the same distributor | 0.80 | buy | Indicative price per metre (estimate); 30 m probe depth plus a 2.7 m surface run (tube top to the terminals, including a 1.1 m service loop coiled in the junction box for the 1 m calibration lift; WLS-DDR-004); sized per well to 60 m
3 Access tube (per metre), drilled, with end cap | 31 | 25 mm (1 in) Sch 40 PVC pressure pipe, 33.4 mm OD, 26.6 mm bore, in 3 m lengths with solvent-weld couplings; bottom 0.5 m drilled with 8 mm holes, four to a ring, rings 50 mm apart; 1 in Sch 40 slip cap solvent-welded on the bottom end | Local plumbing supplier | 1.00 | buy | Indicative price per metre (estimate), end cap and couplings included; probe depth plus 0.5 m below and 0.1 m above the casing; only where a pump or riser shares the casing (WLS-DDR-001 D4); drilled holes replace the concept's sawn slots (WLS-DDR-004) | [' with a probe of 22 mm or less for 2.3 mm radial clearance (WLS-DDR-002)']
4 Split seal plate, gasket, wraps, rim band and collar | 1 | Two half plates cut from one 200 mm disc of 20 mm HDPE (drinking-water grade), split on the line through the riser, pump cable and tube holes; two 10 mm HDPE spigot half rings (148 mm OD, 128 mm ID) screwed underneath; 3 mm EPDM gasket ring (184 x 150 mm, cut once); 2 mm EPDM wrap strips for the riser, pump cable and tube; stainless worm-drive band clamp round the rim (180 to 210 mm); split aluminium shaft collar for 1-5/16 in (33.4 mm) pipe; stainless screws | Plastics stockist, rubber supplier, hardware store | 23.00 | make | Indicative price (estimate); made in the workshop (drawing WLS-DWG-101); fits round an installed riser and pump cable without pulling the pump; the collar carries the hanging tube (264 N at 60 m); HDPE and EPDM must be certified for drinking water (R9); replaces the concept's one-piece plate with glands (WLS-DDR-004)
5 Tube cap, cross bolt and support grip | 1 | 1 in Sch 40 PVC slip cap (not glued), drilled 22.5 mm in the top for the conduit connector and 5 mm across for a stainless M5 x 50 eye bolt (swing eye, eye about 7.5 mm inside) with nyloc nut as the cross bolt; stainless single-eye cable support grip for 6 to 8 mm cable hooked on the cross bolt | Plumbing supplier, electrical wholesaler | 11.50 | buy | Indicative price (estimate); the grip carries the probe and cable (35 N at 60 m) and sets the recorded probe depth; the cap lifts off with the probe for the two-point calibration (WLS-DDR-004); eye bolt instead of a plain bolt so a padlock can hang from it (+$1.50: marketplace price of a stainless M5 eye bolt about $2.00 against $0.50 for a plain M5 x 50 bolt; WLS-DEC-001 decision 2)
6 Junction box, lugs, entries and breather | 1 | IP66 polycarbonate box 160 x 120 x 90 mm with four moulded bosses inside the back wall and the maker's kit of four external mounting lugs; one M16 gland (4 to 8 mm cable) and one M12 gland (3 to 6.5 mm); replaceable silica gel breather (about 10 g) in an M20 hole; four M5 x 16 button-head screws with nyloc nuts | Electrical supplier | 18.00 | buy | Indicative price (estimate); bottom face drilled for four entries (drawing WLS-DWG-106); desiccant changed every quarterly visit; lugs and glands added for construction (WLS-DDR-004)
7 4 to 20 mA interface board with 24 V boost | 1 | 150 ohm 0.1 % 10 ppm/K shunt, 16-bit ADC (ADS1115 class) with a series input resistor, 12 to 24 V boost module, 3.3 V regulator for the ADC and barometric sensor, reverse polarity diode and TVS surge protection, pluggable terminal strip; on a 3D-printed ASA internal plate (100 x 130 x 3 mm) on the box's bosses with M3 screws and nylon standoffs; I2C to FieldNode sensor port A | Electronics distributor | 13.00 | buy | Indicative price (estimate); boost added at TRL 3 because the 12 V rail cannot supply the loop (WLS-CAL-001 section B); no custom PCB for the first build; internal plate and terminal strip added for construction (WLS-DDR-004)
8 FieldNode core | 1 | Lab shared node built to the FieldNode build plan (FND-BLD-001): IP65 enclosure, 6 W panel on its bracket, LiFePO4 cell, power modules, STM32WL-class LoRaWAN radio, two M12 sensor ports, back plate with V-blocks and two band clamps for a 48 mm pole | See the fieldnode repo (FND-CAL-001 v0.3) | 139.00 | make | Cost of the constructable base node from FND-CAL-001 v0.3 (was $126.00); counted in the FieldNode repo and not in the WellSense value-engineering target (WLS-DDR-001 D1); geometry vendored from the FieldNode model in cad/vendor/
9 Barometric reference sensor | 1 | BMP390 or BME280 class module in a small louvred housing, 36 mm diameter x 50 mm, with a flat mounting flange (two M4 screws) and a 0.3 m lead into the junction box through the M12 gland | Electronics distributor | 8.00 | buy | Indicative price (estimate); housing on the junction box plate below the box (WLS-DDR-004); logs air pressure for barometric response and as a vent check
10 Post, junction box plate, V-blocks and bands | 1 | 48.3 x 3.2 mm (1-1/2 in) galvanized pipe 2.7 m long, 2.1 m above ground, push-in top cap; junction box plate 140 x 530 x 3 mm aluminium (5052 or 6061 class) with band slots; two V-blocks 60 x 33 x 20 mm from 60 x 40 mm aluminium bar; two 12 mm stainless worm-drive band clamps; M4 countersunk and M5 screws with nyloc nuts | Local steel and aluminium supplier, hardware store | 32.00 | buy | Indicative price (estimate); the plate and V-blocks replace the concept's two bands round the box, which could not hold a flat box on a round post (WLS-DDR-004); FieldNode's own band clamps are in line 8
11 Manual water level meter (shared) | 1 | Electric tape water level meter, 50 m, for the install datum, two-point calibration and quarterly checks | Well and drilling supplier | 80.00 | buy | Indicative price (estimate); one per community or partner and not in the per-well cost; not modeled
12 Dashboard | 1 | Open web dashboard: level below ground, drawdown, season comparison, CSV export | Open source (this repo) | 0.00 | make | Software; not modeled; not started
13 Post footing concrete | 1 | 25 kg bag of premixed concrete for a 300 mm diameter, 0.6 m deep footing | Builders merchant | 6.00 | buy | Indicative price (estimate); added at TRL 3 (missing from the TRL 2 BOM)
14 Surface cable conduit, flexible tail, saddles and hub | 1 | 1/2 in (21.3 mm OD) galvanized rigid conduit, about 0.95 m with one 90 degree bend of 100 mm radius; 0.3 m of 1/2 in liquid-tight flexible conduit with two straight connectors (one into the tube cap, one to the rigid end); two 1/2 in spacer saddles; 1/2 in conduit hub into the junction box floor | Electrical supplier | 20.00 | buy | Indicative price (estimate); added under WLS-DDR-002 for R16 (no exposed cable at reachable height); flexible tail, saddles and hub added for construction (WLS-DDR-004) so the cap can lift off for calibration
15 FieldNode lead | 1 | 4-core screened sensor cable, about 0.2 mm2, 1.5 m, with an M12 A-coded 5-pin plug (IP67) on one end; cable ties | Electrical wholesaler or electronics distributor | 7.00 | buy | Indicative price (estimate); joins the junction box (M16 gland) to FieldNode sensor port A; missing from the concept (WLS-DDR-004)
16 Locking: security-head screw and bit, two padlocks, hasp kit | 1 | One stainless security-head (pin-in or one-way) screw for the rim band clamp, replacing its hex screw, with a bit for it; two keyed-alike 20 mm stainless padlocks with a 4 mm shackle (one on the eye bolt of line 5, one on the box hasp); one padlockable stainless hasp kit for the line 6 box (two tabs, one on the body and one on the lid, two M3 screws each with sealing washers) | Fastener and security hardware supplier, hardware store | 16.50 | buy | Indicative price (estimate): security screw $1.00 and bit $2.50 (marketplace listings for a single screw and a one-bit tool), padlocks 2 x $4.50 = $9.00 (marketplace price of a keyed-alike 20 mm stainless padlock, $4 to $5), hasp kit $4.00 (marketplace price of a small stainless hasp pair); keyed alike so one key opens both; fitted from the start on the prototype (WLS-DEC-001, decision 2); the lockable steel wellhead cover for exposed sites is not in this line and is priced when a site visit calls for it

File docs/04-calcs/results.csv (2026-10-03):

tag | result
A1 | Full scale 10 m of water = 98.07 kPa; 1 kPa = 102.0 mm of water
A2 | Shunt 150 ohm gives 0.60 to 3.00 V; ADC step 125 uV; 19,200 steps; resolution 0.52 mm (0 to 10 m), 1.04 mm (0 to 20 m variant)
A3 | Placement rule: probe at least 1 m below the lowest pumping level; seasonal swing plus pumping drawdown up to 9 m then stays in range with 1 m of headroom; larger swings need the 0 to 20 m variant
B1 | Loop at 22 mA, 63 m cable (10.9 ohm): from the 12 V rail (low 11.4 V) the transducer gets 7.56 V against 12 V minimum (short by 4.44 V); with a 24 V boost it gets 20.16 V (margin 8.16 V)
B1b | Shunt voltage at a 25 mA fault is 3.75 V, above the ADC's 3.6 V limit at 3.3 V supply; a series input resistor is needed
B2 | Per reading: loop 1.38 J (24 V x 22 mA x 2 s, boost 85 %, rail 90 %) + controller 0.053 J = 1.43 J
B3 | At 15 min: 38.2 mWh/day, 1.59 mW average; 1.6 % of FieldNode's published 100 mW allowance
B4 | At 1 min (pumping test): 0.573 Wh/day, 23.9 mW average; 24 % of the 100 mW allowance
B5 | TRL 2 figure for comparison: 0.66 J per reading, 18 mWh/day (12 V direct, 80 %)
C1 | Gravity 9.7803 m/s2 at the equator, 9.8062 at 45 deg, 9.8192 at 60 deg: using standard g misreads 10 m by +27 mm at the equator; firmware uses local g, and calibration absorbs the rest
C2 | Density 1000.00 kg/m3 at 4 degC, 999.13 at 15 degC, 997.08 at 25 degC: 0.29 % or 29 mm at 10 m across 4 to 25 degC
C3.1 | nonlinearity, hysteresis, repeatability: 10.0 mm
C3.2 | probe thermal effect, 2 K: 4.0 mm
C3.3 | density at a fixed site value, 2 K: 3.2 mm
C3.4 | shunt drift, 30 K: 3.8 mm
C3.5 | ADC gain drift, 30 K: 2.6 mm
C3.6 | ADC resolution: 0.5 mm
C3.7 | manual tape reference: 3.0 mm
C4 | 0.25 % class after two-point calibration: RSS 12.5 mm, worst-case sum 27.1 mm (target 20 mm)
C5 | 0.5 % class after two-point calibration: RSS 21.4 mm, worst-case sum 37.1 mm
C6 | Datasheet only, no field calibration: 50 mm (0.5 % class), 25 mm (0.25 % class)
C7 | Absolute sensor without compensation, +/-3 kPa weather: +/-306 mm
C8 | Drift: with a tape check every quarter, a transducer drifting 20 mm a year leaves at most 5 mm uncorrected between checks, close to the 3 mm tape uncertainty; real drift of low-cost probes is unknown
D1 | Model: probe 22 mm in a 26.6 mm bore: 2.3 mm radial clearance; tube 32.2 mm from the riser and 18.3 mm from the casing wall in the 150 mm design well
D2 1 in (DN25) | bore 26.6 mm takes probes up to 22 mm with 2 mm radial clearance; fits beside a centered riser in casings of 150, 200 mm; beside a riser against the wall in 100, 125, 150, 200 mm
D2 1-1/4 in (DN32) | bore 35.1 mm takes probes up to 28 mm with 2 mm radial clearance; fits beside a centered riser in casings of 200 mm; beside a riser against the wall in 100, 125, 150, 200 mm
D3 | Cable and probe hanging in air at 60 m: 35 N against a 400 N strain member (factor 11.5)
D4 | Access tube 320 mm2, 0.45 kg/m; 60 m hanging dry: 264 N, stress 0.82 MPa against 48 MPa (factor 58); the tube collar carries 264 N onto the seal plate
D5 | Collar on the HDPE seal plate: 264 N on 1087 mm2, 0.24 MPa bearing against about 20 MPa for HDPE (factor 82); the collar's friction grip on the tube is the maker's rating, to confirm at purchase
D6 | Probe and cable (35 N at 60 m) hang from the support grip on the M5 eye bolt (the cross bolt): bearing on the two 4.4 mm cap walls 0.79 MPa against about 50 MPa for PVC; the cap sits on the tube end, so the load reaches the collar through the tube
D7 | Locking (WLS-DEC-001): the padlock hangs from the eye bolt with 1.0 N, so the cap walls carry 36 N instead of 35 N (0.81 MPa); the cap still lifts off the tube once the padlock is open, so the padlock stops the eye bolt being unscrewed and the grip and probe being freed, and the lockable steel wellhead cover is what stops the cap being lifted at exposed sites
E1 | One year at 15 min: 35,040 readings x 32 B = 1.12 MB, 6.7 % of the 16 MB flash
E2 | A 7-day pumping test at 1 min adds 10,080 readings, 0.32 MB
E3 | Airtime at SF9: 20-byte uplink 246.8 ms, 23.7 s/day at 15 min (FieldNode figure); pumping test batch of 15 readings (38 bytes) 328.7 ms, 31.6 s/day, over the 30 s/day fair use on a public network; fits a private TwinKit gateway
E4 | Rule (WLS-DDR-002): on a public network a pumping test sends every 30 min, a batch of 30 readings (68 bytes) 472.1 ms, 22.7 s/day, within 30 s/day; on a private TwinKit gateway the 15 min batch is kept
F1 | Vent capillary 111 mL at 62.7 m; box and vent breathe 0.15 L/day at a 30 K swing, carrying 3.6 mg of water at worst; 10 g of gel lasts about 552 days if the whole box breathes through it (quarterly change: factor 6.1)
G1 | Estimated 125 min for two people (10 steps) against 120 min, 5 min over the limit with the locks fitted; post footing set and cured on an earlier visit
H1 | BOM 16 lines, 16 priced; cable 33 m and tube 30.61 m (BOM 31 m) at 30 m probe depth
H2 | WellSense parts (lines 1 to 7, 9, 10, 13 to 16): $262.40 against the $200 value-engineering target (budget_usd, a hypothetical control target, not a limit): $62.40 over the target; with the FieldNode core $401.40; with FieldNode's hot-site shield (+$9.00, FND-DDR-002) $410.40
H2c | Lines repriced or added for construction (WLS-DDR-004): 4 $23.00, 5 $11.50, 6 $18.00, 7 $13.00, 10 $32.00, 14 $20.00, 15 $7.00; the concept total was $197.60
H2d | Locking (WLS-DEC-001, decision 2): line 16 $16.50 (security-head screw and bit, two padlocks, hasp kit) and $1.50 more in line 5 for an eye bolt, $18.00 in all; without the locking parts the cost would be $244.40
H2b | Without the conduit (line 14, $20.00) the parts would be $242.40, $42.40 over the target
H3 | Depth-dependent $1.80/m; the fixed parts alone are $208.40, over the target even at zero depth; at 60 m $316.40; without an access tube (no pump in the casing) $231.40
L R9 | Not met: No drinking water certificate in hand for low-cost cable, seal or probe
L R4 | At risk: RSS 12.5 mm, sum 27.1 mm (0.25 % class, calibrated)
L R10 | At risk: 2.3 mm radial clearance with a 22 mm probe; tube may need the pump pulled
L R15 | At risk: FieldNode shield at hot sites (48.5 to 52.2 degC inside at 45 degC); FieldNode rated to 45 degC ambient against 55 degC
L R16 | Met: Cable in conduit from the tube cap to the box; by design review the seal plate, cross bolt and junction box are each lockable (security-head screw, padlock on the eye bolt, hasp and padlock); lifting the cap at exposed sites needs the steel cover
L R5 | Not verifiable at TRL 3: Drift unknown; quarterly check leaves 5 mm
L R11 | Not verifiable at TRL 3: 125 min estimate
L R13 | Not verifiable at TRL 3: Dashboard not started
L R1 | Met: 0 to 10 m, 98.07 kPa
L R2 | Met: Cable factor 11.5, tube factor 58 at 60 m
L R3 | Met: 0.52 mm
L R6 | Met: 15 min; 1 min logged, sent every 30 min on a public network (22.7 s/day)
L R7 | Met: 1.12 MB a year
L R8 | Met: 38.2 mWh/day, 1.6 % of 100 mW
L R12 | Over the value-engineering target: $262.40 at 30 m against the $200 target, $62.40 over
L R14 | Met: Levels, time and well ID only
L | 1 not met, 3 at risk, 8 met, 3 not verifiable at TRL 3, 1 over the value-engineering target

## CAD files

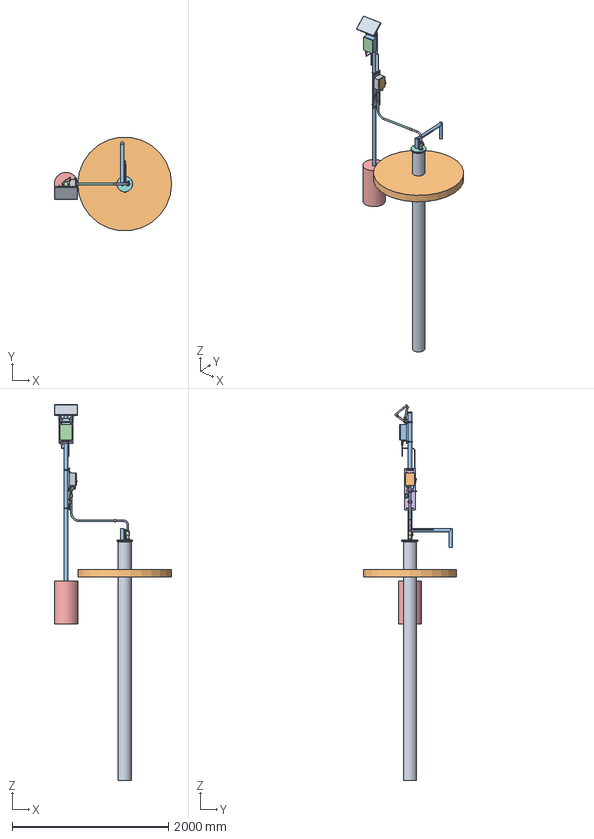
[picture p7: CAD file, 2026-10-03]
cad/step/wellsense-assembly.step
1500.0 x 1191.3 x 4805.8 mm

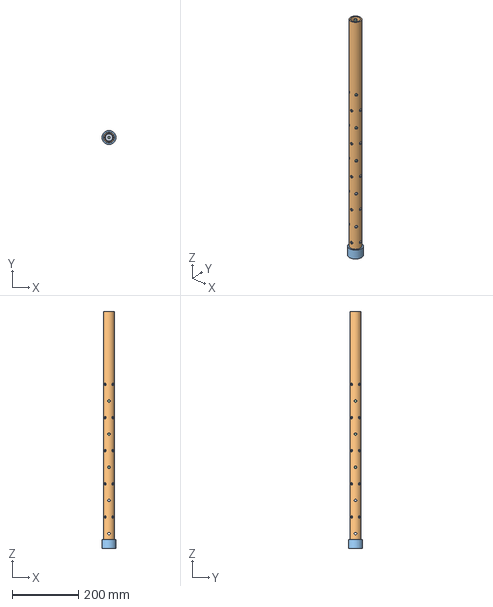
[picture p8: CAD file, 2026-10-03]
cad/step/wellsense-probe.step
42.2 x 42.2 x 715.0 mm

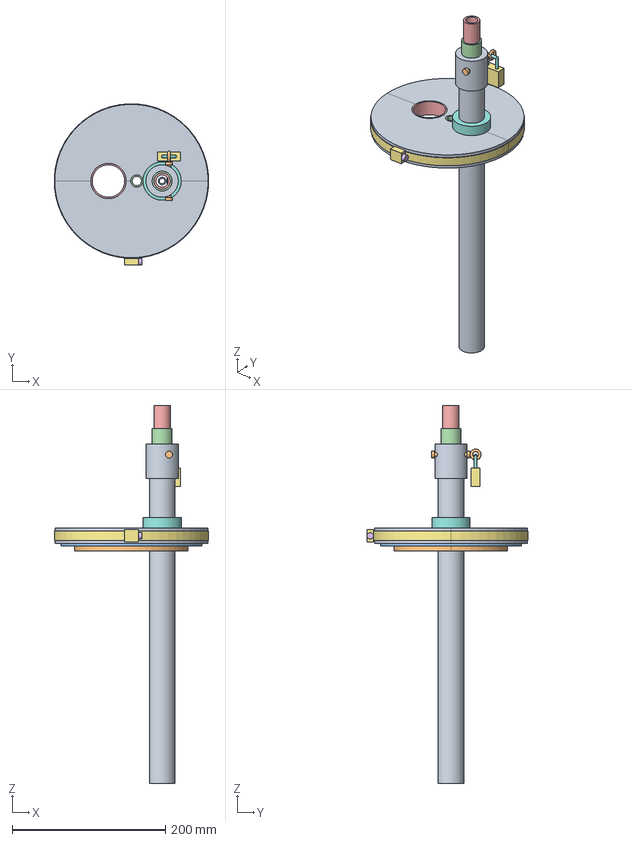
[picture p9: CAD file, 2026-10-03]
cad/step/wellsense-wellhead.step
201.5 x 210.5 x 493.0 mm

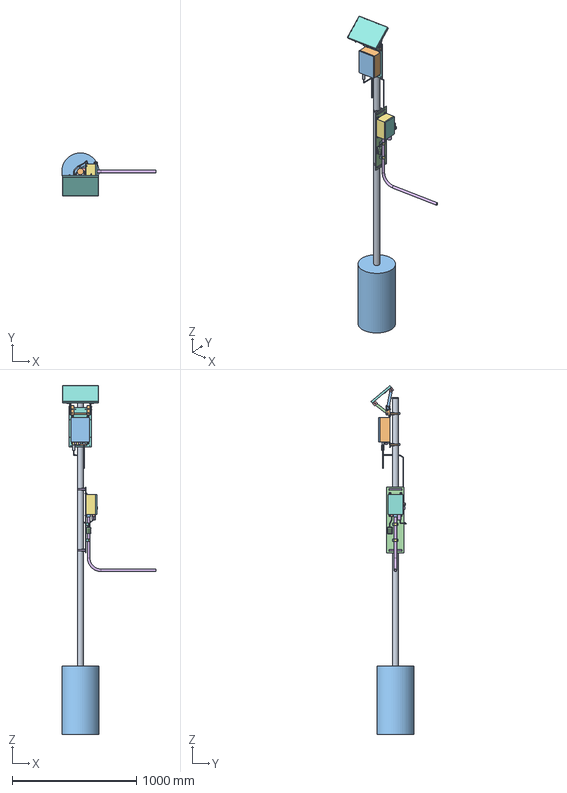
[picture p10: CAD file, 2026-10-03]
cad/step/wellsense-post.step
759.7 x 347.0 x 2805.8 mm

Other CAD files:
cad/stl/wellsense-assembly.stl
cad/stl/wellsense-post.stl
cad/stl/wellsense-probe.stl
cad/stl/wellsense-wellhead.stl

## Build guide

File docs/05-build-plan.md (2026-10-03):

---
doc_id: WLS-BLD-001
title: WellSense prototype build plan
project: WellSense
doc_type: Build plan
version: "0.2"
status: Draft
date: '2026-10-02'
author: Amish Chadha
license: CERN-OHL-S-2.0
revisions:
  - version: "0.1"
    date: '2026-10-02'
    author: Amish Chadha
    change: First build plan, with pictures by component and step; design made constructable (WLS-DDR-004)
  - version: "0.2"
    date: '2026-10-02'
    author: Amish Chadha
    change: Locks added as decided on 2026-10-02 (security-head screw, eye bolt and padlock, hasp and padlock, Figures 9a and 23a, step 18); wiring redrawn to FieldNode's standard port pinout
---

# WellSense prototype build plan

**Plan, not yet built.** How to build the first proof-of-concept prototype, component by component. Building and testing to it is TRL 4 work. The decisions behind the design are recorded in the design decisions register ([docs/06-design-decisions.md](06-design-decisions.md)).

## 1. What you are building

Figure 1. Every component, pulled apart and numbered in build order

*Figure 1. Every component pulled apart and numbered in build order. The access tube, cable and probe are drawn with the middle of the borehole left out.*

The prototype is one complete WellSense on a mock-up well: a short length of 150 mm casing standing in for the well, with a stand-in 1-1/4 in riser and pump cable, and the post set in the ground beside it. At a real well the steps are the same; only the access tube and cable are made to the well's depth. A vented pressure probe hangs on its cable inside a 1 in plastic access tube beside the riser. A split plastic seal plate closes the top of the casing round the riser, the pump cable and the tube. The cable leaves the tube through a cap, runs in a short flexible tail and a bent steel conduit to a junction box on the post, and the junction box feeds a FieldNode core higher up the same post. Figure 1 shows the 26 components in the order you make or fit them. Nine are made or worked in a small workshop: the post, the junction box plate, two V-blocks, the drilled junction box, the printed internal plate, the bent conduit, the seal plate with its spigot rings, the drilled access tube and the drilled tube cap. Everything else is bought and fitted, and the FieldNode core is built to its own plan. The work is sawing, drilling and filing aluminium, plastic and steel pipe, bending one length of conduit, one 3D print, cutting rubber sheet, and wiring bought modules with screw terminals. The WellSense parts cost about $262 at a 30 m probe depth, from the bill of materials.

> **Safety:** A real well is drinking water and often has a mains-powered pump. Before any work at a real well, isolate and lock off the pump supply, disinfect everything that goes into the well, and never leave the wellhead open. WellSense itself runs at 24 V or less. The FieldNode core holds a lithium iron phosphate cell of about 19 Wh: follow its build plan's safety stops. Cut aluminium and steel edges are sharp; printing ASA gives off fumes; concrete is caustic on skin.

## 2. What changed to make it buildable

The concept showed what WellSense does; some of its parts could not be made or fixed as drawn. Each change below keeps what WellSense does, and all of them are recorded in decision record WLS-DDR-004.

*Table 1. Changes from the concept.*

| Component | The concept had | The buildable design has | Why |
| --- | --- | --- | --- |
| FieldNode core | A block on two legs, floating 18 mm off the post | FieldNode's own constructable design, on its V-blocks and band clamps (step 9) | It is built to the FieldNode build plan and fits the same post |
| Junction box mounting | A flat box drawn into the round post, "held" by two bands, one of them above the box | A plate with two V-blocks and two band clamps; the box on the plate by four lugs (Figures 3, 5 and 9) | A band cannot hold a flat box on a round post |
| Junction box inside | A solid block with the board inside it; no cable entries | A hollow bought box; a printed internal plate on its bosses; four entries in the floor (Figures 6 to 12) | Entries in the floor keep water out; the electronics lift out as one piece |
| Barometric sensor | A housing floating beside the post, no fixing, no cable | A flanged housing screwed to the plate below the box, its lead in a gland (step 7) | A flat fixing and a short lead |
| Conduit | A solid rod round the cable with sharp corners, fixed hard to the tube cap | One bend of 100 mm radius, a hub under the box, two saddles, and a flexible tail to the cap (Figures 14, 15 and 23) | A hand bender makes it; the cap lifts off for calibration |
| Seal plate | One solid disc with two gland bosses; no way round an installed riser, no fixing, no hole for the pump cable | Two HDPE halves with spigot rings, an EPDM gasket and wraps, and a band round the rim (Figures 16 to 19) | It fits round the riser and pump cable without pulling the pump |
| Tube support | Not drawn, although 264 N of tube hangs from it at 60 m | A split collar on the tube resting on the seal plate (Figure 18) | A bought part that sets the tube height |
| Tube cap | A cap with a "hanger" boss, nothing carrying the probe | A slip cap with an eye bolt as the cross bolt; a cable support grip hangs from the bolt (Figure 23) | It holds the recorded probe depth and lifts off with the probe |
| Access tube bottom | 3 x 60 mm lengthwise slots and a plug made as part of the tube | Rings of 8 mm drilled holes and a bought end cap (Figures 20 and 21) | A hand drill does it |
| FieldNode lead | A cable into the top of the box with no plug | A lead with an M12 plug through a gland in the box floor, with a drip loop (step 10) | No entry on the top of a box outdoors |
| Locks | Nothing locked; the lockable parts were not specified | A security-head screw on the rim band, an eye bolt on the tube cap with a padlock, and a padlock hasp on the junction box, all fitted from the start (Figures 9a and 23a, step 18) | Keeps passers-by and livestock from opening the wellhead or the box |
| Surface cable | 2 m, no slack | 2.7 m with a 1.1 m service loop in the box (step 17) | The probe is lifted 1 m to calibrate it |

## 3. Making the components

Make and check each component before the assembly step that needs it. Sizes are in millimetres. "Front" is the side facing the well for the junction box and the side facing the equator for the FieldNode core; "left" and "right" are as seen standing in front. Workshop tolerance is 0.5 mm unless a step says otherwise; drawings do not carry tolerances before TRL 4.

### 3.1 Post and footing

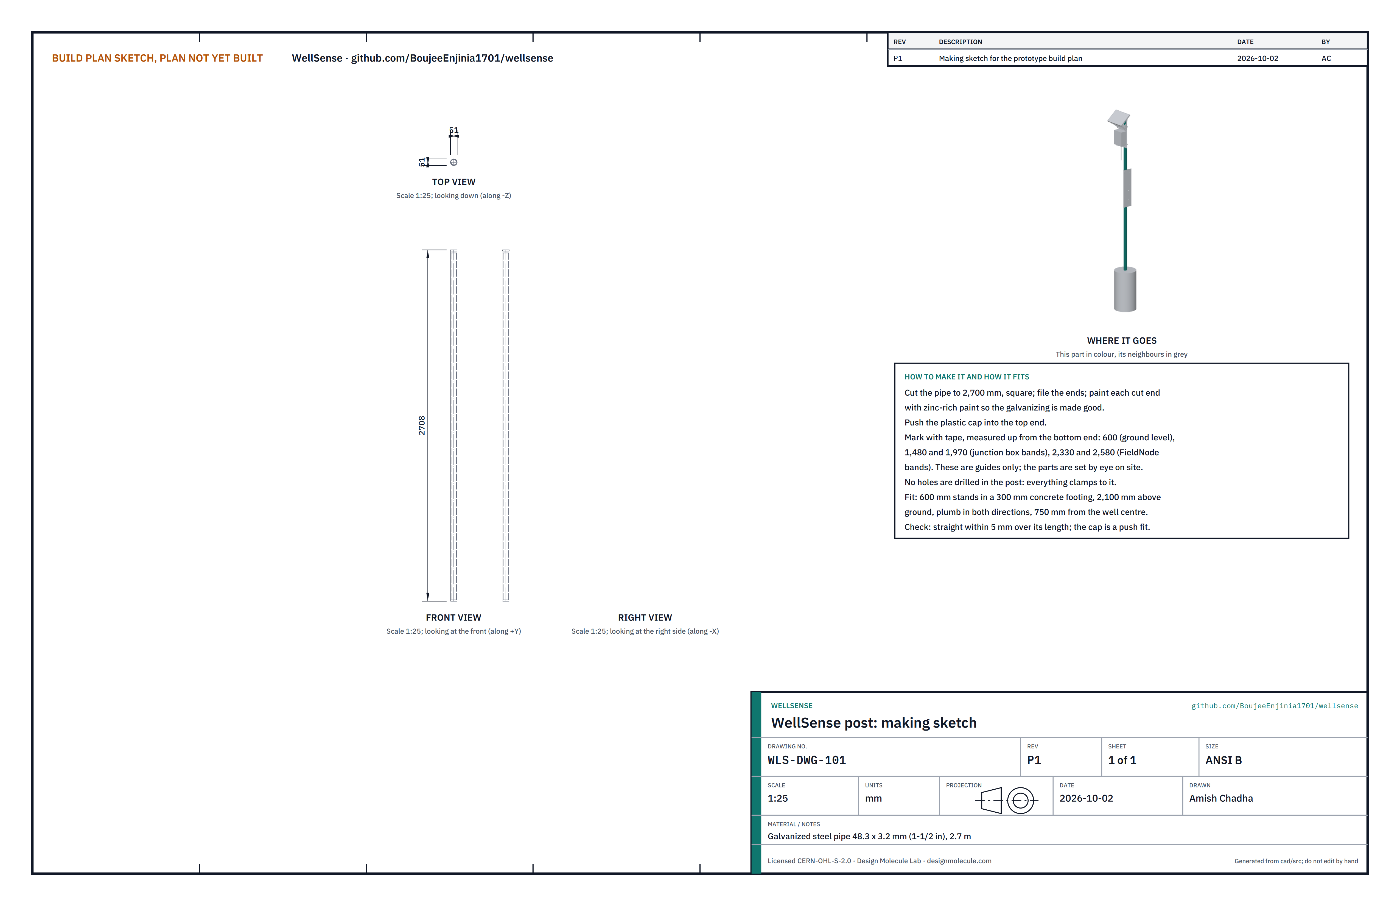
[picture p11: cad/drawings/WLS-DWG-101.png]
Figure 2. Making sketch of the post


*Figure 2. Post making sketch (WLS-DWG-101).*

**What it is and what it is made from.** The upright that carries the junction box and the FieldNode core, 750 mm from the well's centre. Galvanized steel pipe 48.3 mm outside, 3.2 mm wall (1-1/2 in), 2.7 m long, with a push-in plastic cap; set in one 25 kg bag of premixed concrete.

**How to make it.**

1. Cut the pipe to 2,700 mm, square. File the ends and paint each cut end with zinc-rich paint.
2. Push the cap into the top end.
3. Mark with tape, measured up from the bottom end: 600 (ground level), 1,480 and 1,970 (junction box bands), 2,330 and 2,580 (FieldNode bands). The marks are guides; the parts are set on site.
4. No holes are drilled in the post: everything clamps to it.

**How it fits the parts next to it.** The bottom 600 mm stands in a concrete footing 300 mm across, on 50 mm of gravel, plumb both ways (step 1). The junction box plate's V-blocks and the FieldNode core's V-blocks sit on it, each pair held by two band clamps.

**Check before moving on.** Straight within 5 mm over its length; the cap is a firm push fit.

### 3.2 Junction box plate

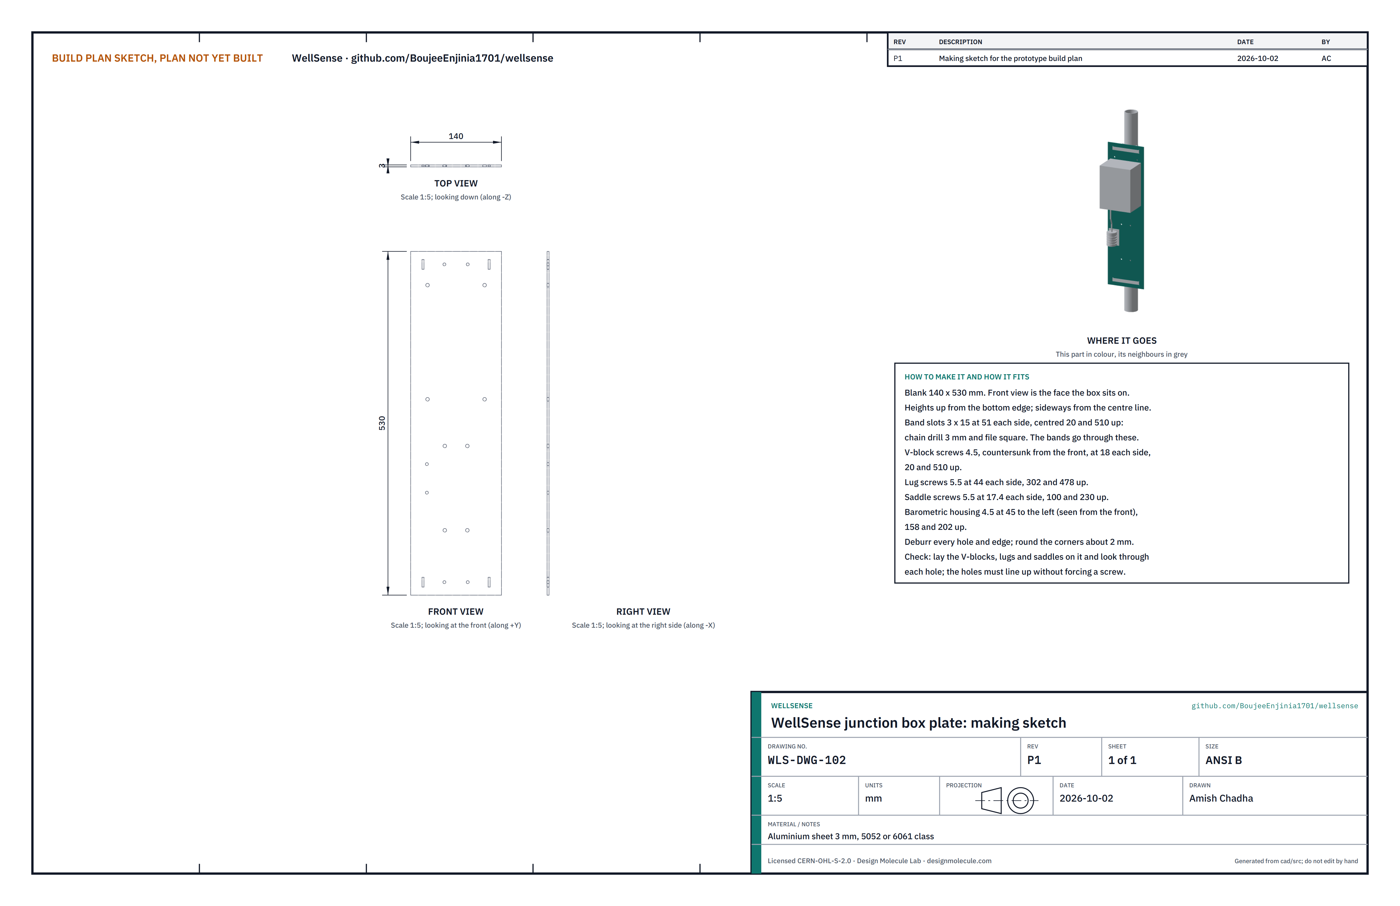
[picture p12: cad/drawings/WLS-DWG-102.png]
Figure 3. Making sketch of the junction box plate


*Figure 3. Junction box plate making sketch (WLS-DWG-102).*

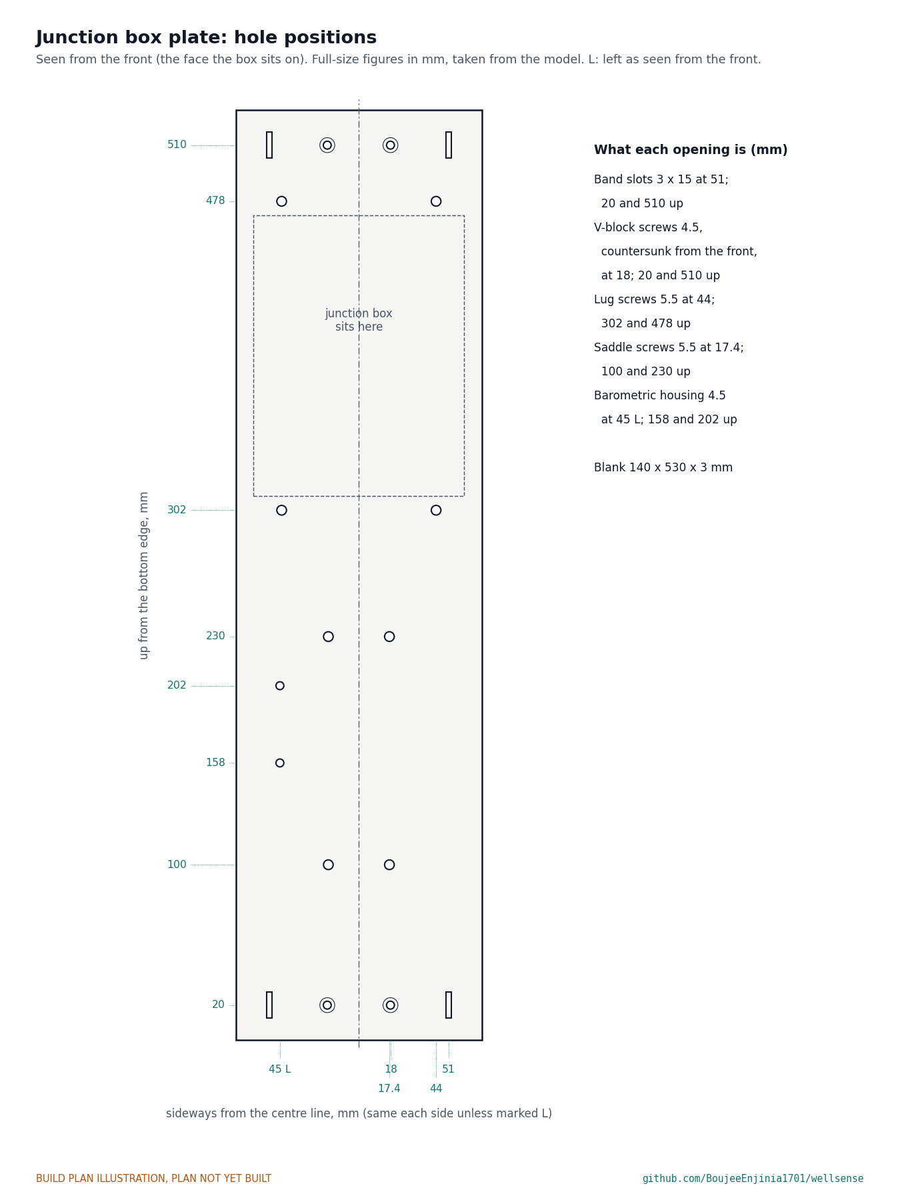
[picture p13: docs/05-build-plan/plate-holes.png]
Figure 3a. Hole positions on the junction box plate


*Figure 3a. Every hole and slot, measured up from the bottom edge and sideways from the centre line.*

**What it is and what it is made from.** The flat plate the junction box, the conduit saddles and the barometric housing are fixed to; it clamps to the post on two V-blocks. Aluminium sheet 3 mm, 5052 or 6061 class, cut to 140 x 530 mm.

**How to make it.**

1. Cut the blank to 140 x 530 mm, square. File the edges and round the corners to about 2 mm.
2. Scribe a centre line down the long side. Choose one face as the front (the box side) and mark it.
3. Mark every hole from Figure 3a: heights up from the bottom edge, sideways from the centre line.
4. Band slots: four slots 3 wide and 15 tall, 51 each side of centre, centred 20 and 510 up. Chain drill with a 3 mm drill and file the slots square.
5. V-block screw holes: four 4.5 mm holes, 18 each side of centre, 20 and 510 up. Countersink them from the front so M4 countersunk screws sit flush.
6. Lug holes: four 5.5 mm holes, 44 each side of centre, 302 and 478 up.
7. Saddle holes: four 5.5 mm holes, 17.4 each side of centre, 100 and 230 up.
8. Barometric housing holes: two 4.5 mm holes, 45 left of centre, 158 and 202 up.
9. Deburr every hole on both faces.

**How it fits the parts next to it.** The V-blocks sit flat on its back face at the top and bottom (Figure 5). The box's back sits flat on its front face between 310 and 470 up, held by four lugs (Figure 9). The saddles and the barometric housing sit flat on its front face below the box.

**Check before moving on.** Lay the V-blocks, lugs and saddles on the plate and look through each hole: the holes must line up without forcing a screw.

### 3.3 V-blocks (make 2)

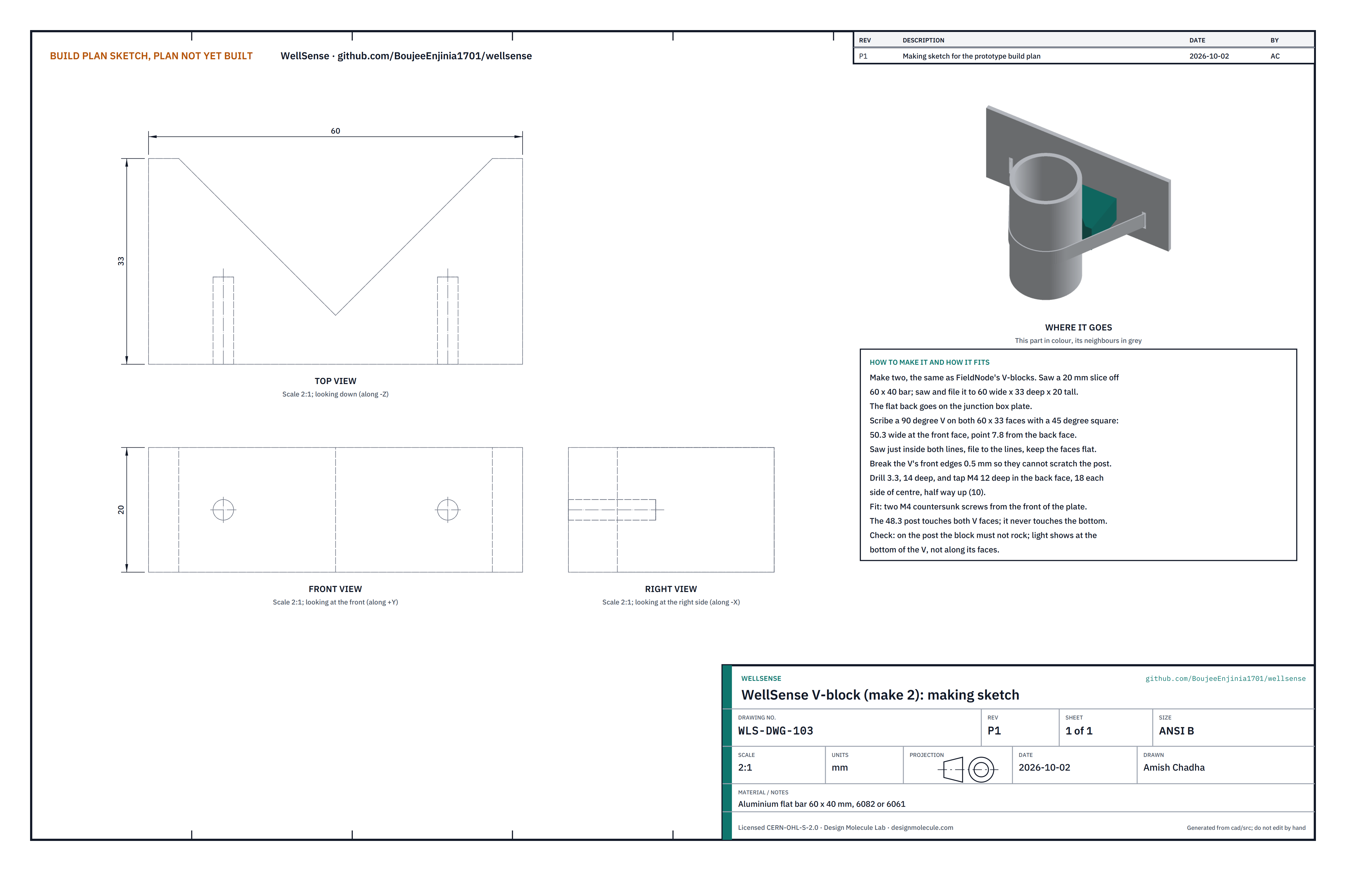
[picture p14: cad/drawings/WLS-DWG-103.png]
Figure 4. Making sketch of the V-block


*Figure 4. V-block making sketch (WLS-DWG-103). The same part as FieldNode's V-block.*

**What it is and what it is made from.** A block with a 90° V cut in it that the post sits in, one at each band clamp. Aluminium flat bar 60 x 40 mm, 6082 or 6061 class.

**How to make it.**

1. Saw two slices 20 mm thick off the bar. Saw and file each to 60 wide, 33 deep and 20 tall. The 60 x 20 face that will sit on the plate is the back face; file it flat.
2. On each 60 x 33 face, scribe the V with a 45° square: two lines from the front face, 50.3 apart where they start, meeting at a point 7.8 from the back face, centred on the width.
3. Saw just inside both lines, then file to the lines. Keep the two V faces flat and square to the block's faces.
4. Break the sharp front edges of the V by 0.5 mm.
5. On the back face, 18 each side of centre and half way up, drill 3.3 mm 14 deep and tap M4 12 deep.

**How it fits the parts next to it.**

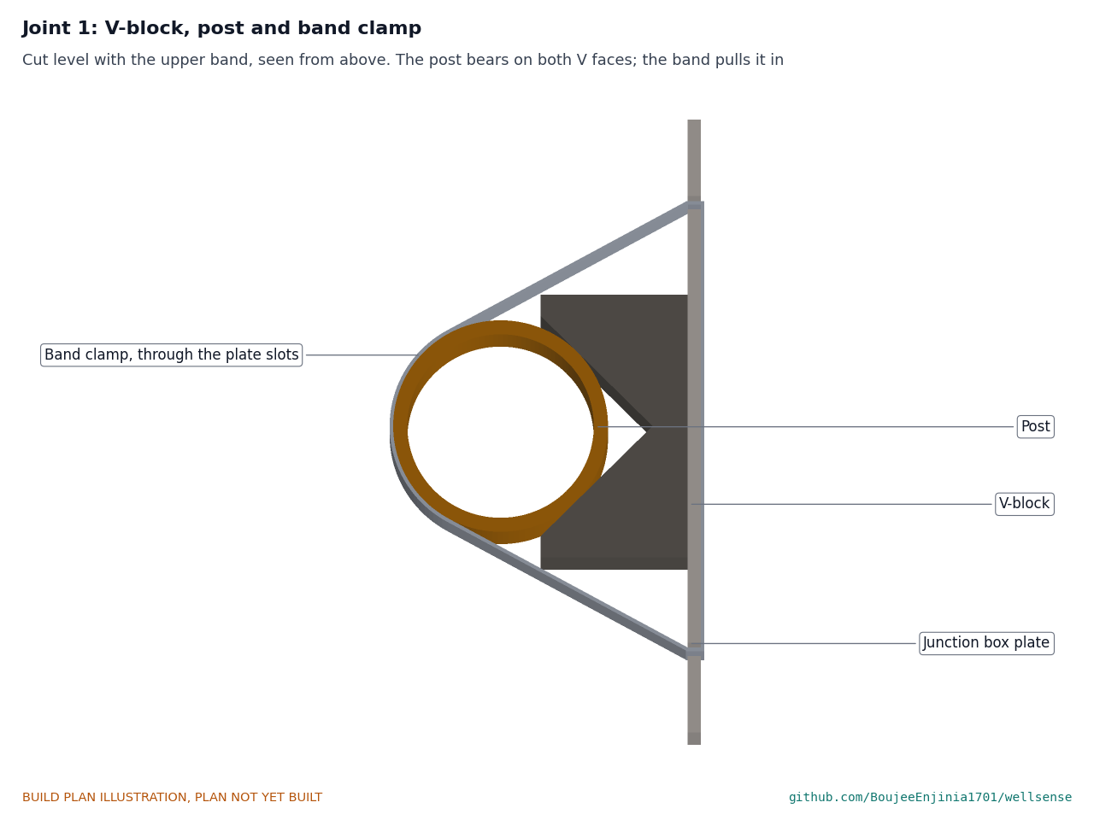
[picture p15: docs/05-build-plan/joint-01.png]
Figure 5. Joint 1: V-block, post and band clamp, seen from above


*Figure 5. The post sits in the V and touches both faces; the band clamp goes round the post and pulls it into the V.*

The back face sits flat on the back of the plate, held by two M4 countersunk screws put in from the front of the plate with a drop of medium threadlocker. The 48.3 mm post touches both faces of the V; it never touches the bottom of the V. The band passes 2 mm clear of the block's outer corners.

**Check before moving on.** Hold the block against the post: it must not rock, and you should see light at the bottom of the V but not along its faces.

### 3.4 Junction box body, drilled, with its entries and lugs

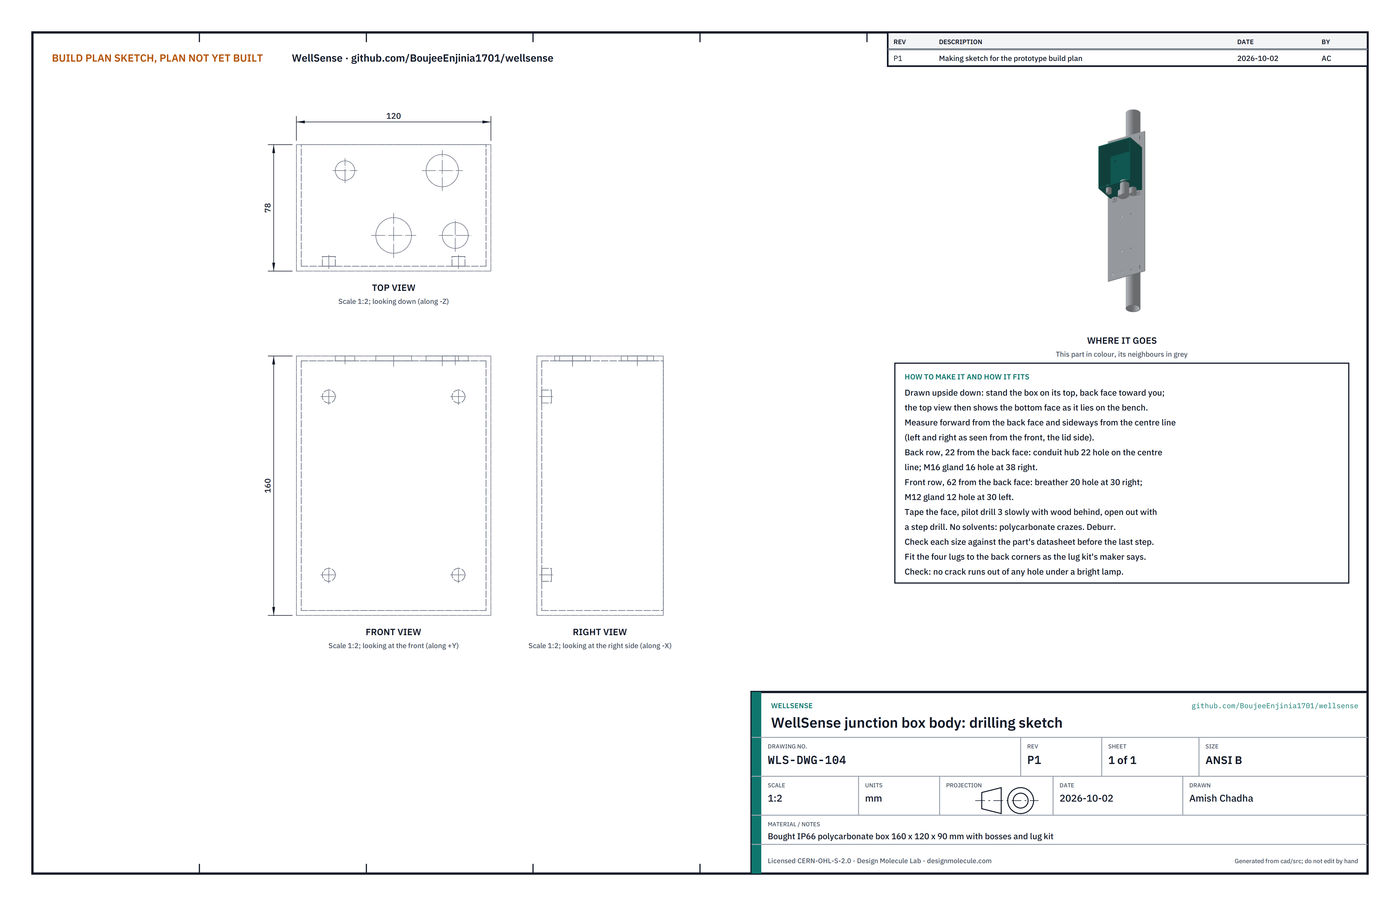
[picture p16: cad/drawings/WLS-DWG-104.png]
Figure 6. Drilling sketch of the junction box body


*Figure 6. Junction box drilling sketch (WLS-DWG-104), drawn upside down so the top view shows the floor.*

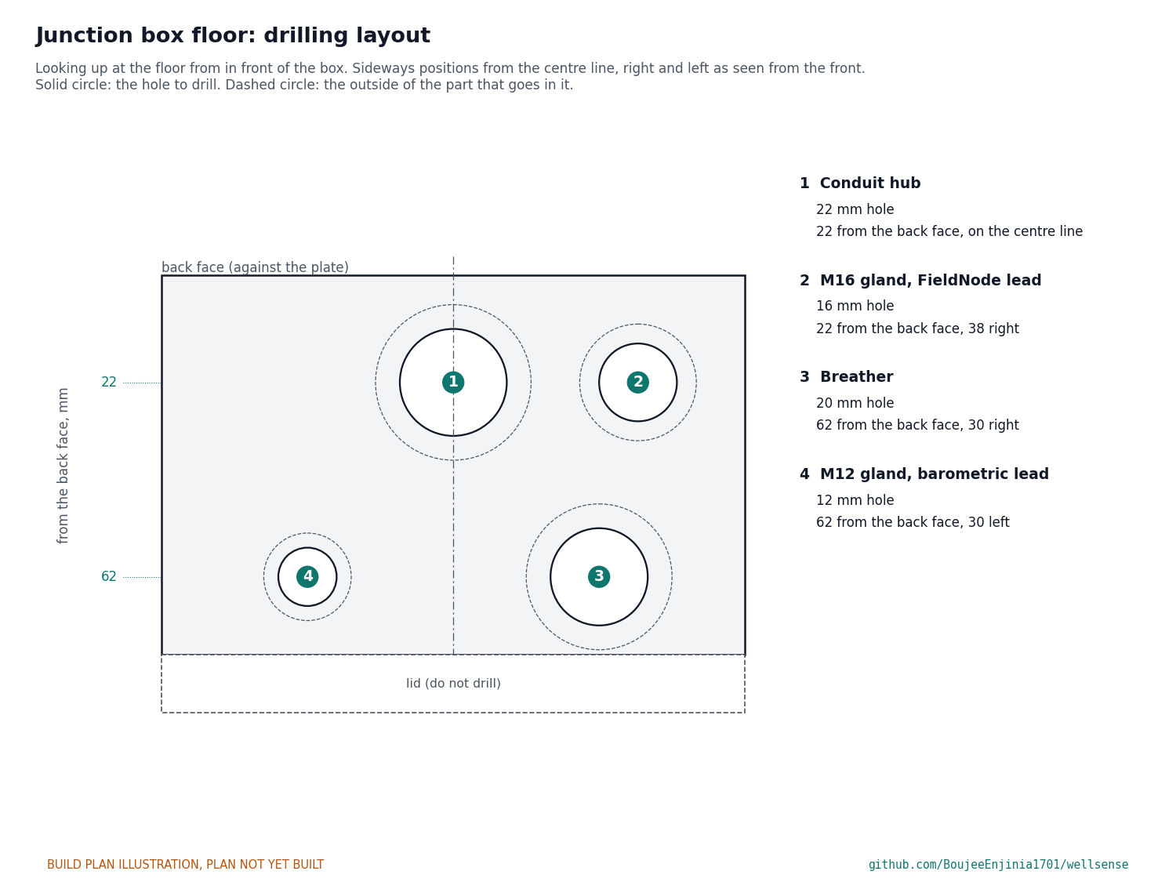
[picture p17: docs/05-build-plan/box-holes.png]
Figure 7. Junction box floor drilling layout


*Figure 7. Drilling layout of the floor.*

**What it is and what it is made from.** A bought grey polycarbonate box, 160 tall, 120 wide and 90 deep, rated IP66, with a gasketed lid on the front, four moulded bosses inside the back wall and the maker's kit of four external mounting lugs. Four holes are drilled in its floor.

**How to make it.**

1. Stand the box upside down on its top on a soft cloth, back face toward you. Cover the floor with masking tape.
2. Mark the holes from Figure 7. Back row, 22 from the back face: the conduit hub on the centre line and the M16 gland 38 right. Front row, 62 from the back face: the breather 30 right and the M12 gland 30 left.
3. Put a block of wood inside under the floor. Pilot drill every hole 3 mm at low speed.
4. Open each hole with a step drill, light pressure, low speed: 22 for the hub, 20 for the breather, 16 and 12 for the glands. Check each size against the part's datasheet before the last step.
5. Deburr inside and out, peel the tape, and clean with water and mild soap only; solvents craze polycarbonate.
6. Fit the four lugs to the box's back corners as the lug kit's maker describes.
7. Fit the hasp kit on the right-hand side wall, as you face the lid, at the middle of the box's height. One stainless tab goes on the body just behind the split between body and lid and one on the lid just in front of it, each on two M3 screws with the kit's sealing washers through 3.2 mm holes. The tabs stand out from the wall 22 mm, 4 mm apart across the split, and each has a 7 mm hole for the padlock.

**How it fits the parts next to it.**

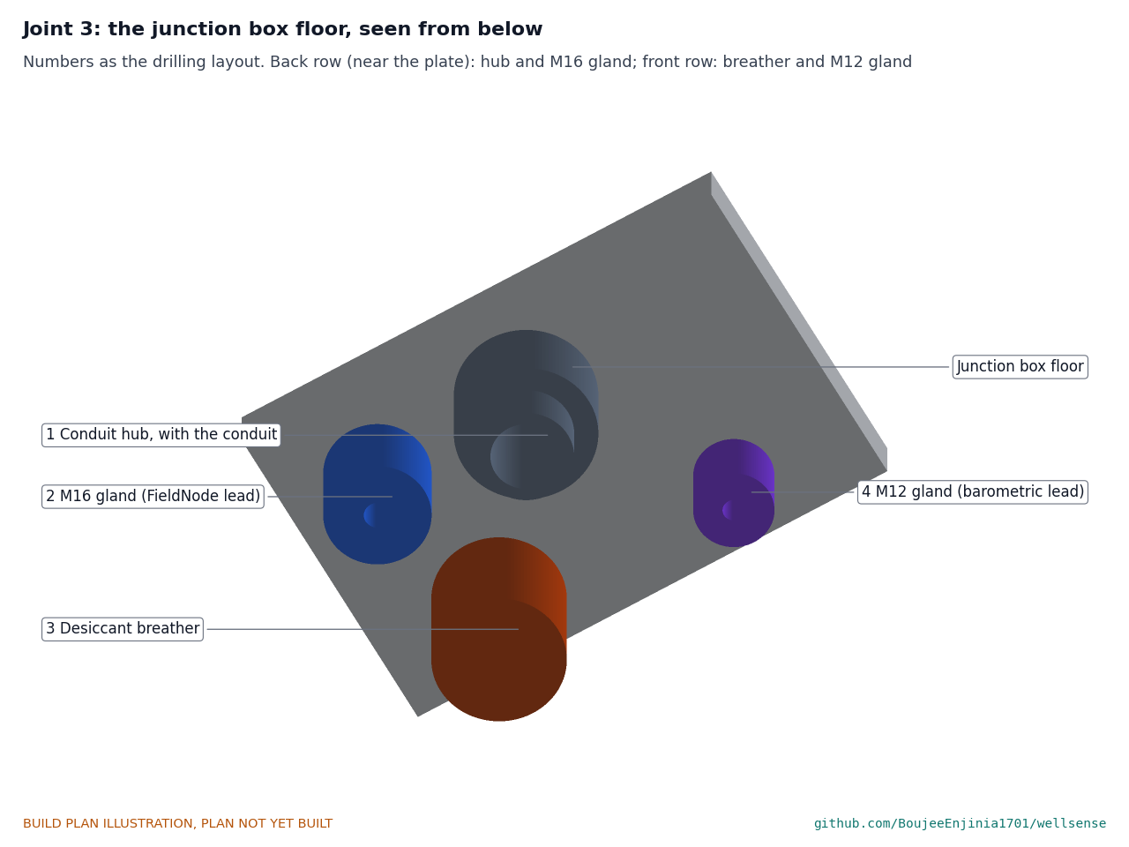
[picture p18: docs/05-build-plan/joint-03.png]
Figure 8. Joint 3: the junction box floor, seen from below


*Figure 8. Hub and M16 gland in the back row, breather and M12 gland in the front row; the conduit comes up into the hub.*

Each entry goes in from below with its seal outside and its nut inside (step 3). The outside bodies are at least 10 mm apart, so a spanner fits each. The box's back sits flat on the plate, held by the lugs:

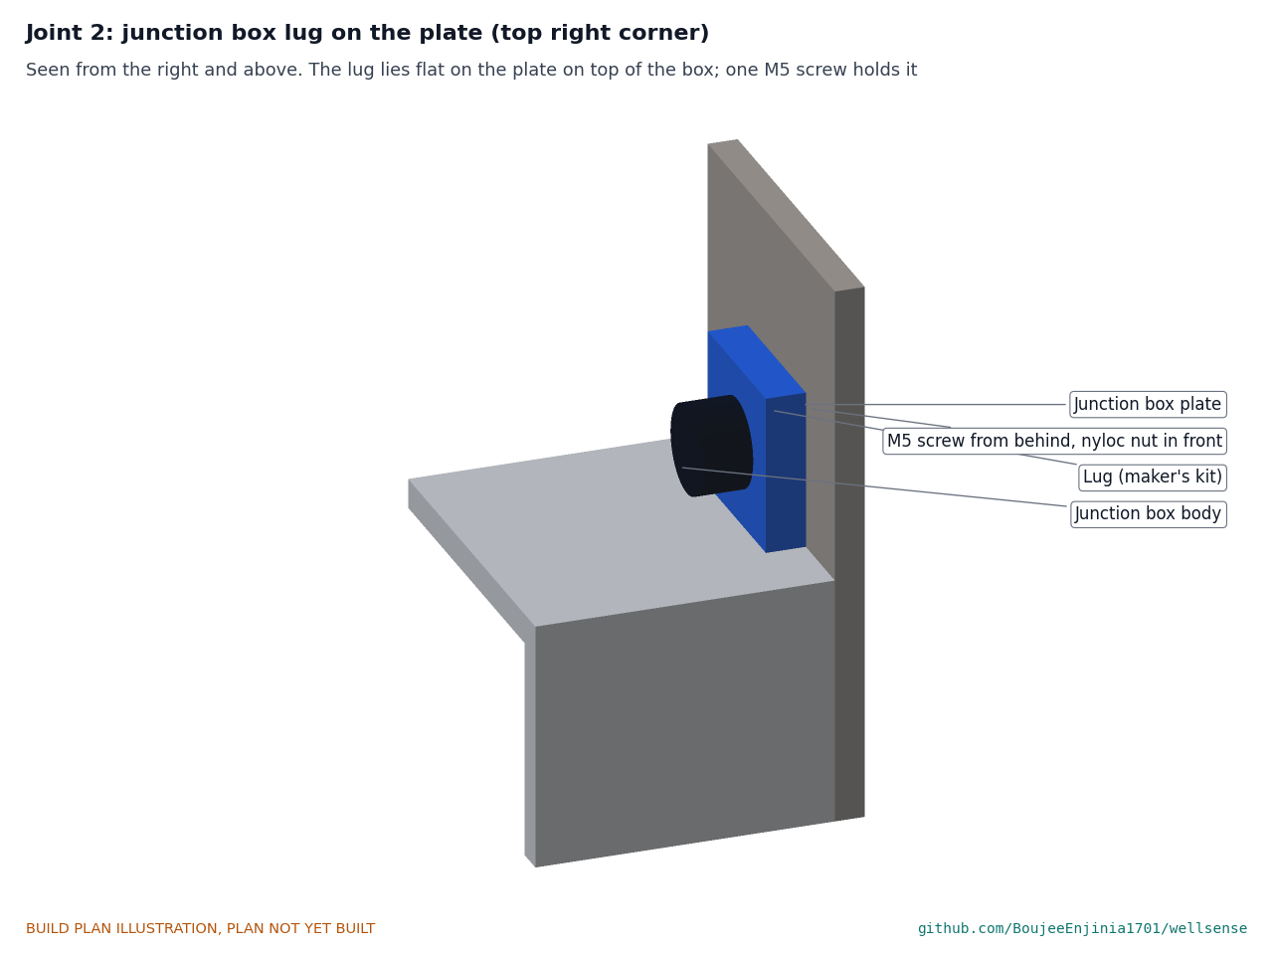
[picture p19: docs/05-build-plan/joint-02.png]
Figure 9. Joint 2: junction box lug on the plate


*Figure 9. Each lug lies flat on the plate beside the box and is held by one M5 button-head screw from behind the plate, nyloc nut in front.*

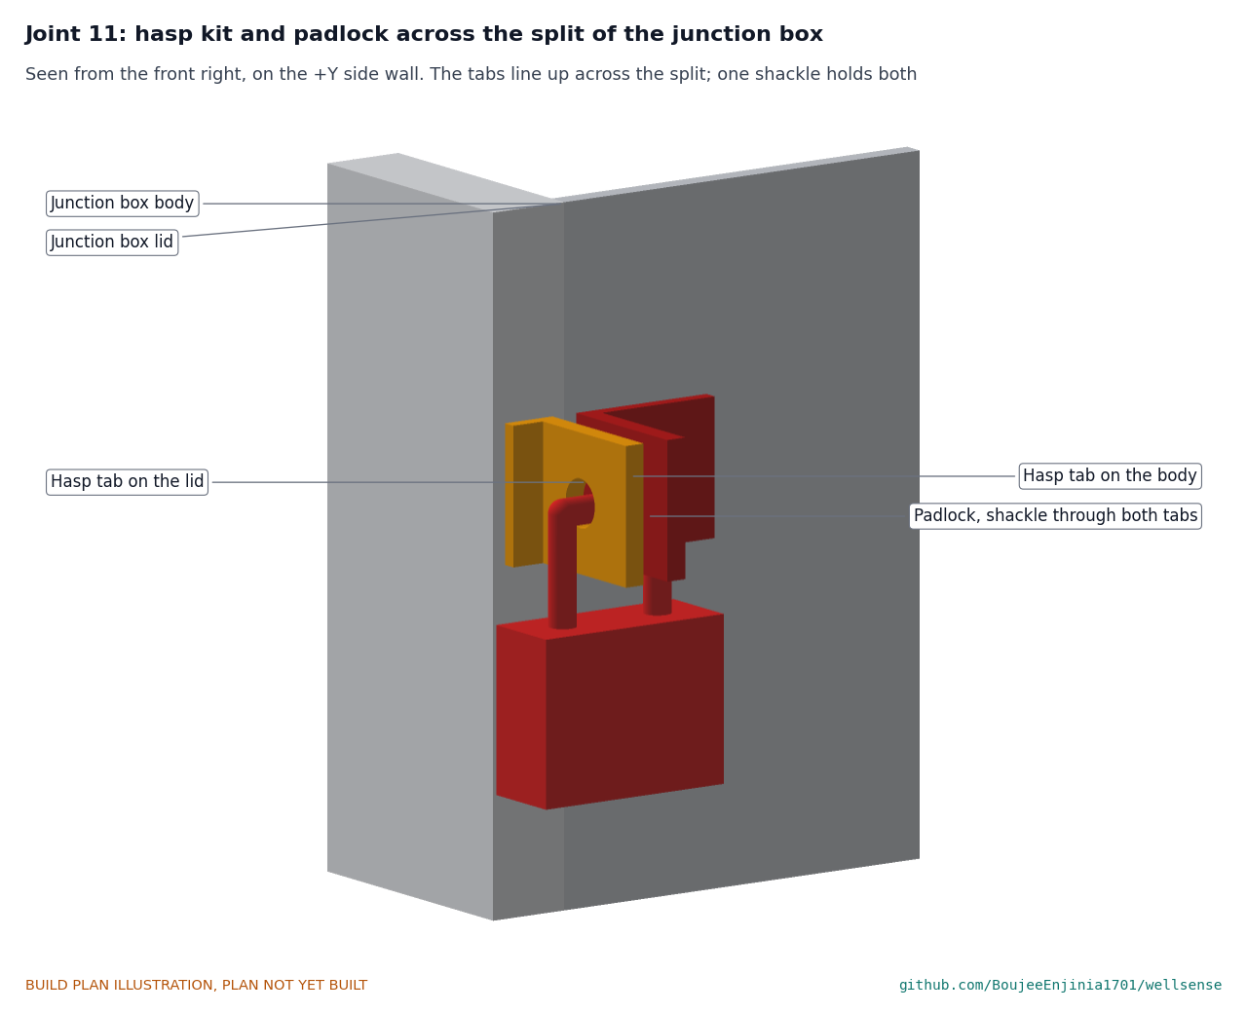
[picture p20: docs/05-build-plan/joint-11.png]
Figure 9a. Joint 11: hasp kit and padlock across the split of the junction box


*Figure 9a. The two tabs line up across the split between the body and the lid; one padlock shackle goes through both holes, so the lid cannot be opened while the padlock is shut.*

**Check before moving on.** No crack runs out from any hole under a bright lamp; the box sits flat on the plate with all four lug holes lined up; the two hasp tab holes line up with the lid shut and a 4 mm rod passes through both.

### 3.5 Internal plate and the interface modules on it

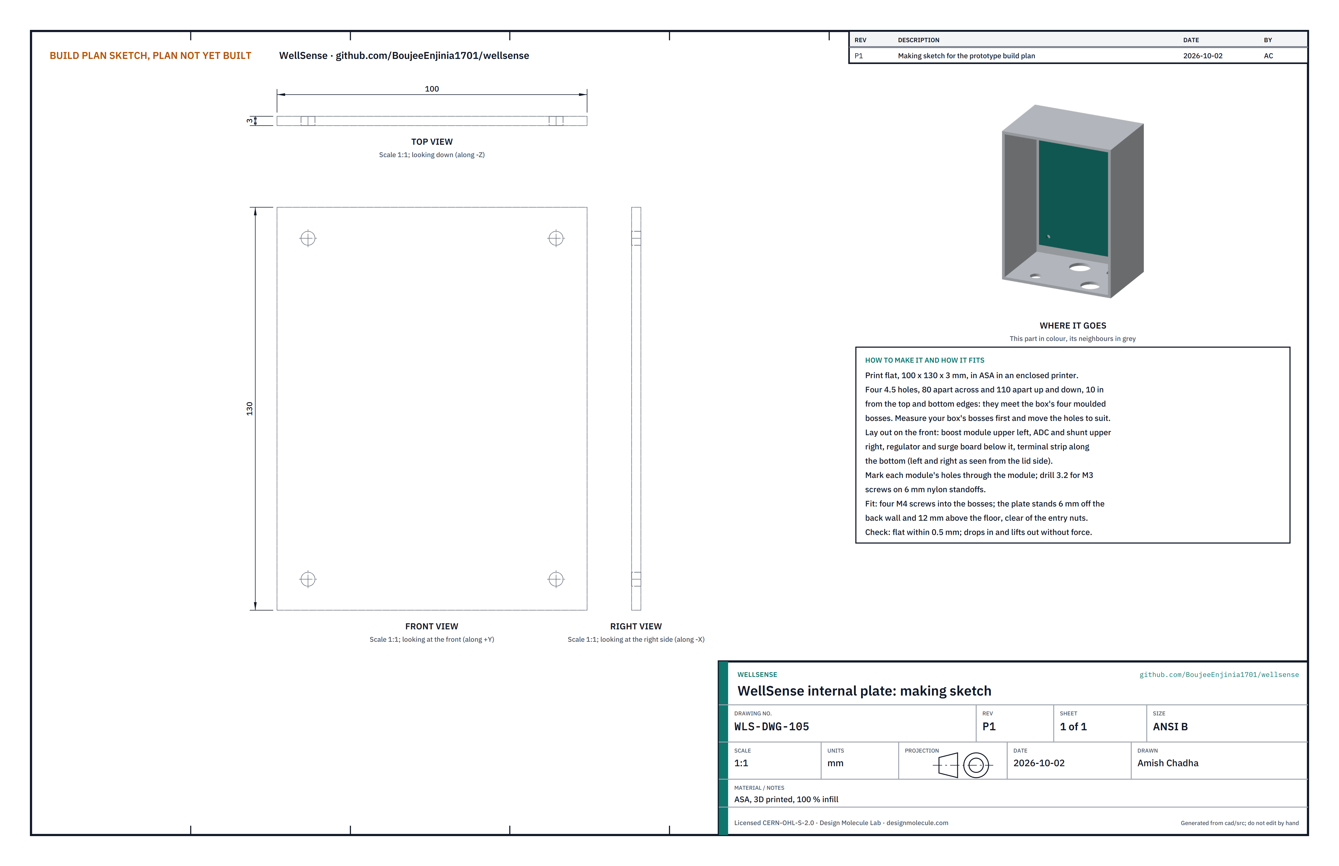
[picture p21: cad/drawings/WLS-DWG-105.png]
Figure 10. Making sketch of the internal plate


*Figure 10. Internal plate making sketch (WLS-DWG-105).*

**What it is and what it is made from.** A printed plate that carries the interface modules and the terminal strip and lifts out of the box as one unit. ASA plastic, 100 x 130 x 3 mm, printed flat at 100 % infill in an enclosed printer.

**How to make it.**

1. Measure the four bosses inside your box. The model assumes they are 80 apart across and 110 apart up and down; move the plate's holes to match your box.
2. Print the plate with four 4.5 mm holes at the bosses, 10 in from the top and bottom edges. Let it cool on the bed so it does not warp.
3. Lay out the parts on the front face as Figure 11 shows: boost module upper left, ADC and shunt module upper right, regulator and surge module below it, terminal strip along the bottom.
4. Mark each module's mounting holes through the module, drill 3.2 mm, and fit the modules on M3 screws with 6 mm nylon standoffs.
5. Wire the modules as Figure 13 shows (section 3.5.1).

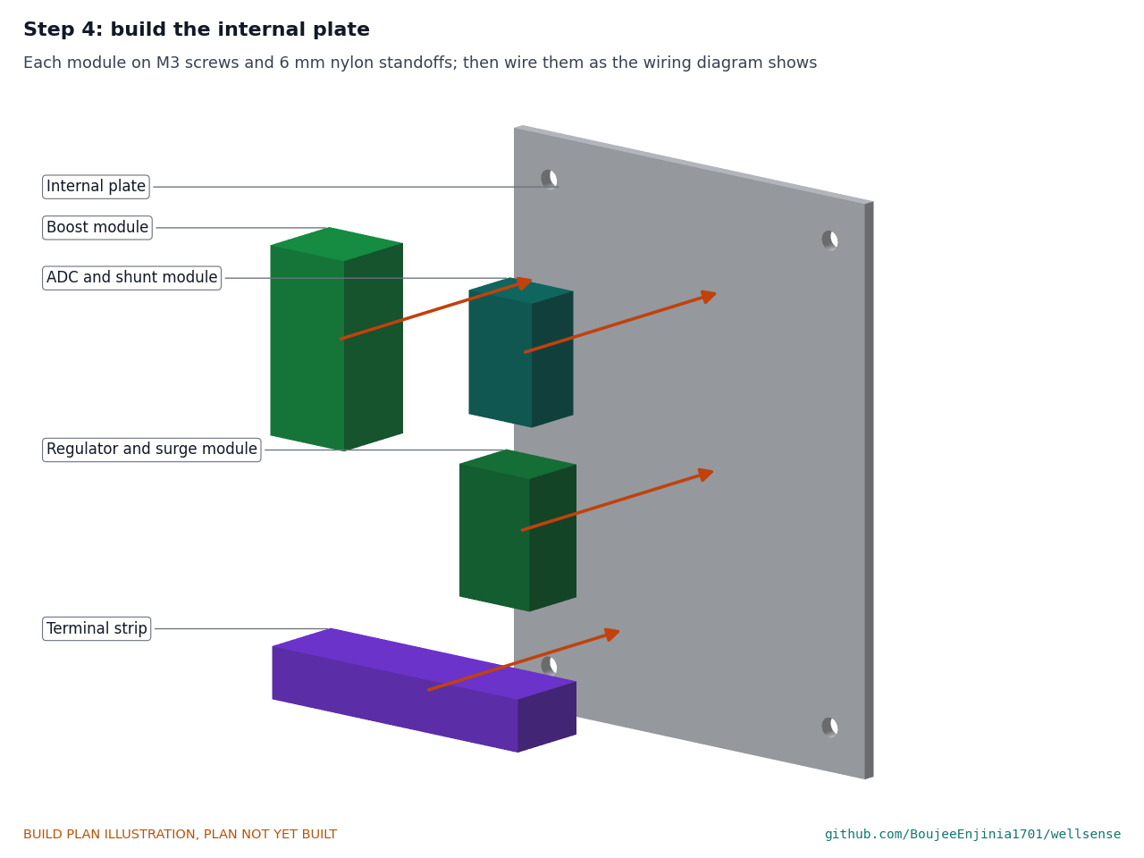
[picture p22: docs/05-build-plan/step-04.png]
Figure 11. Step 4 picture: parts on the internal plate


*Figure 11. Where each part goes on the internal plate.*

**How it fits the parts next to it.**

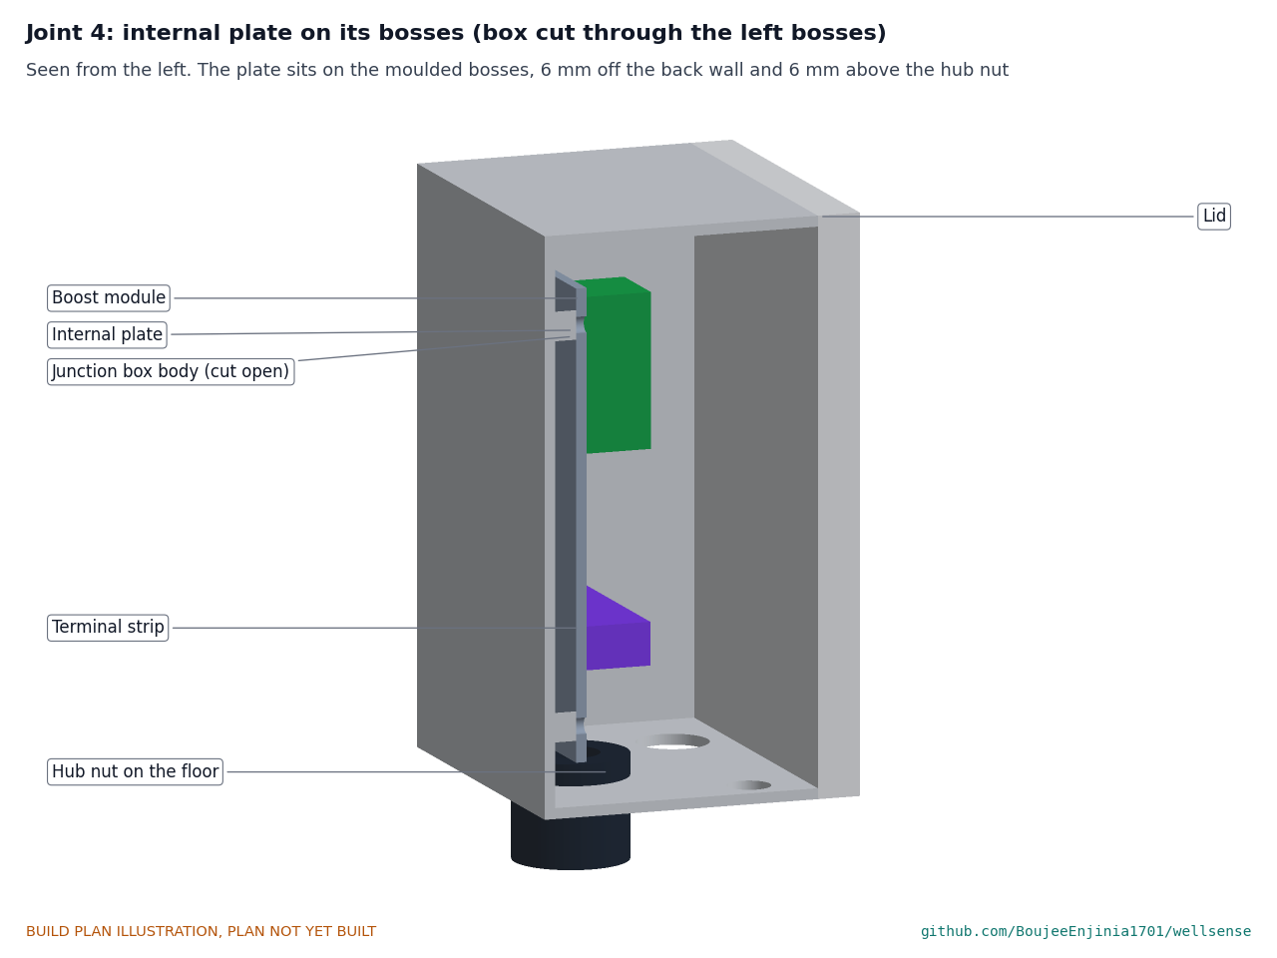
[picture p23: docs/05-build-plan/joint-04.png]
Figure 12. Joint 4: internal plate on its bosses


*Figure 12. The plate sits on the four moulded bosses, 6 mm off the back wall and 12 mm above the floor, clear of the entry nuts, held by four M4 screws.*

**Check before moving on.** The plate is flat within 0.5 mm and drops in and lifts out without force.

#### 3.5.1 Wiring

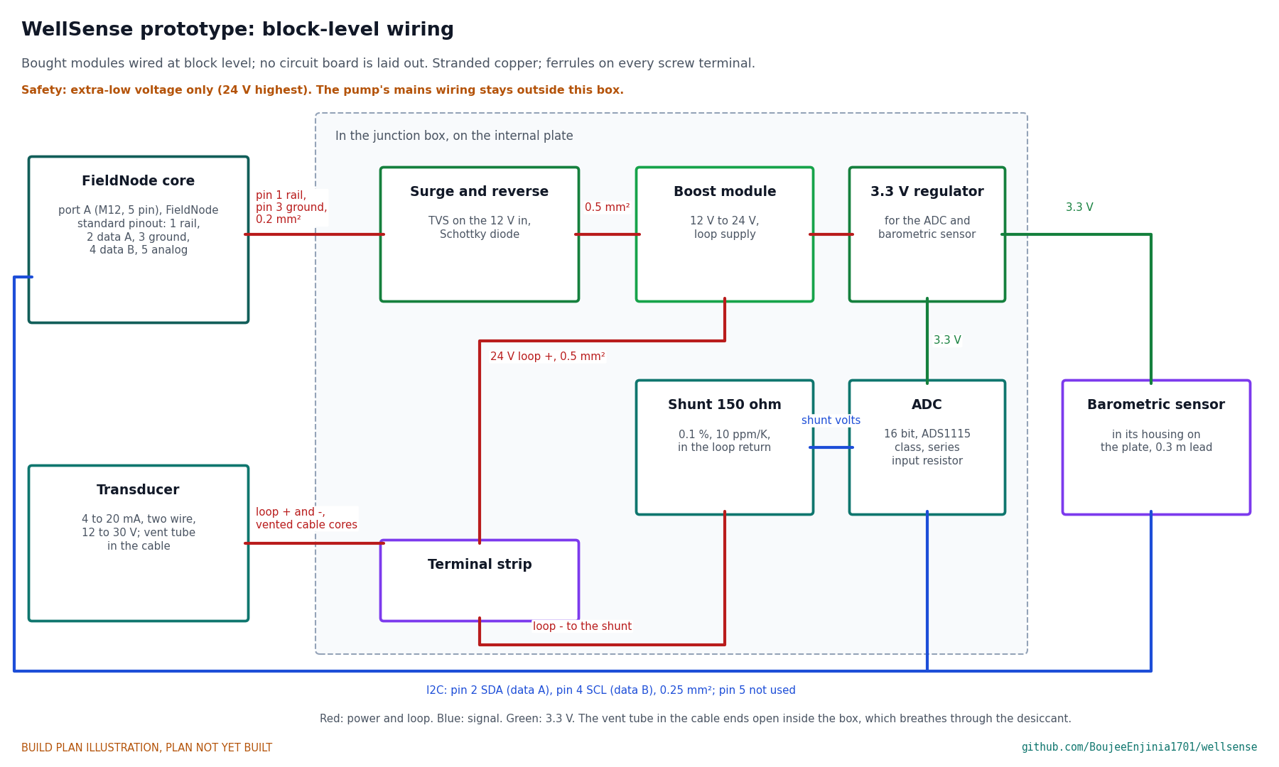
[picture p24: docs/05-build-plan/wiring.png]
Figure 13. Block-level wiring


*Figure 13. Block-level wiring with wire sizes, with the pins of FieldNode sensor port A named. No circuit board is laid out at this stage; bought modules make up the interface board.*

Buy modules that meet this specification:

*Table 2. Modules that make up the interface board.*

| Module | What to buy |
| --- | --- |
| Surge and reverse protection | A TVS diode across the 12 V input and a Schottky diode in series, on a small board |
| Boost module | 12 V in, 24 V out, at least 50 mA, adjustable, about 43 x 21 mm |
| Shunt | 150 Ω, 0.1 %, 10 ppm/K, 0.25 W or more |
| ADC module | 16-bit, ADS1115 class, I2C, with a 1 kΩ to 10 kΩ series resistor added on its input |
| 3.3 V regulator | Low-dropout, 3.3 V, 100 mA or more, feeding the ADC and the barometric sensor |
| Terminal strip | Pluggable, 5.08 mm pitch, about 10 ways |

Wire it like this, with stranded copper and a ferrule on every screw terminal:

1. FieldNode lead to the terminal strip: pin 1 (the switched 12 V rail) and pin 3 (ground), then on to the surge and reverse board: 0.2 mm² in the lead, 0.5 mm² on the plate. This is FieldNode's standard sensor port pinout.
2. Surge board to the boost module input: 0.5 mm².
3. Boost module output (24 V) to the loop + terminal: 0.5 mm².
4. Vented cable cores to the loop + and loop - terminals.
5. Loop - terminal through the 150 Ω shunt to ground: 0.5 mm².
6. Shunt to the ADC input through the series resistor: 0.25 mm², twisted.
7. 12 V to the 3.3 V regulator; regulator to the ADC and to the barometric lead: 0.25 mm².
8. ADC and barometric sensor I2C lines to the terminal strip and back up the FieldNode lead: data A (pin 2) carries SDA and data B (pin 4) carries SCL, 0.25 mm². Pin 5 (analog) is not used and is left unconnected.
9. Leave the vent tube in the vented cable open inside the box; do not crimp or seal it.

**Check before moving on.** Every wire continues end to end; with no supply, the 24 V output and the 12 V input read open to ground; every wire is labelled.

### 3.6 Rigid conduit

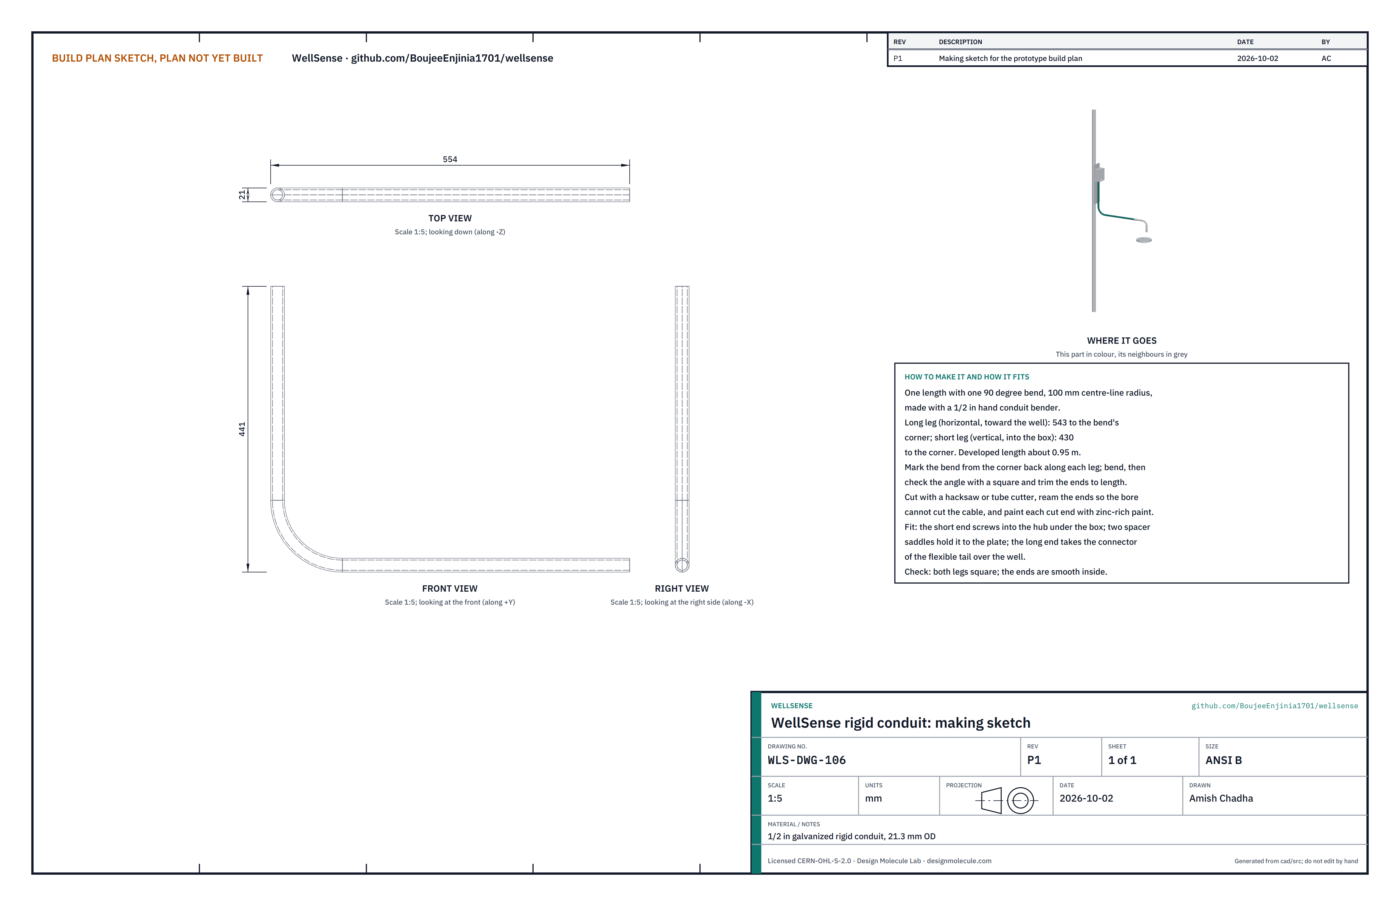
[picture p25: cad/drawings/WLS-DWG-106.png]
Figure 14. Making sketch of the rigid conduit


*Figure 14. Rigid conduit making sketch (WLS-DWG-106).*

**What it is and what it is made from.** The steel pipe that protects the cable from the well to the junction box. 1/2 in galvanized rigid conduit, 21.3 mm outside.

**How to make it.**

1. Cut a length of about 1 m. Ream both ends so the bore is smooth.
2. Bend one 90° bend of 100 mm centre-line radius with a 1/2 in hand conduit bender, so that the long leg runs 543 mm from the bend's corner and the short leg 430 mm.
3. Check the bend with a square and trim both legs to length.
4. Paint each cut end with zinc-rich paint.

**How it fits the parts next to it.**

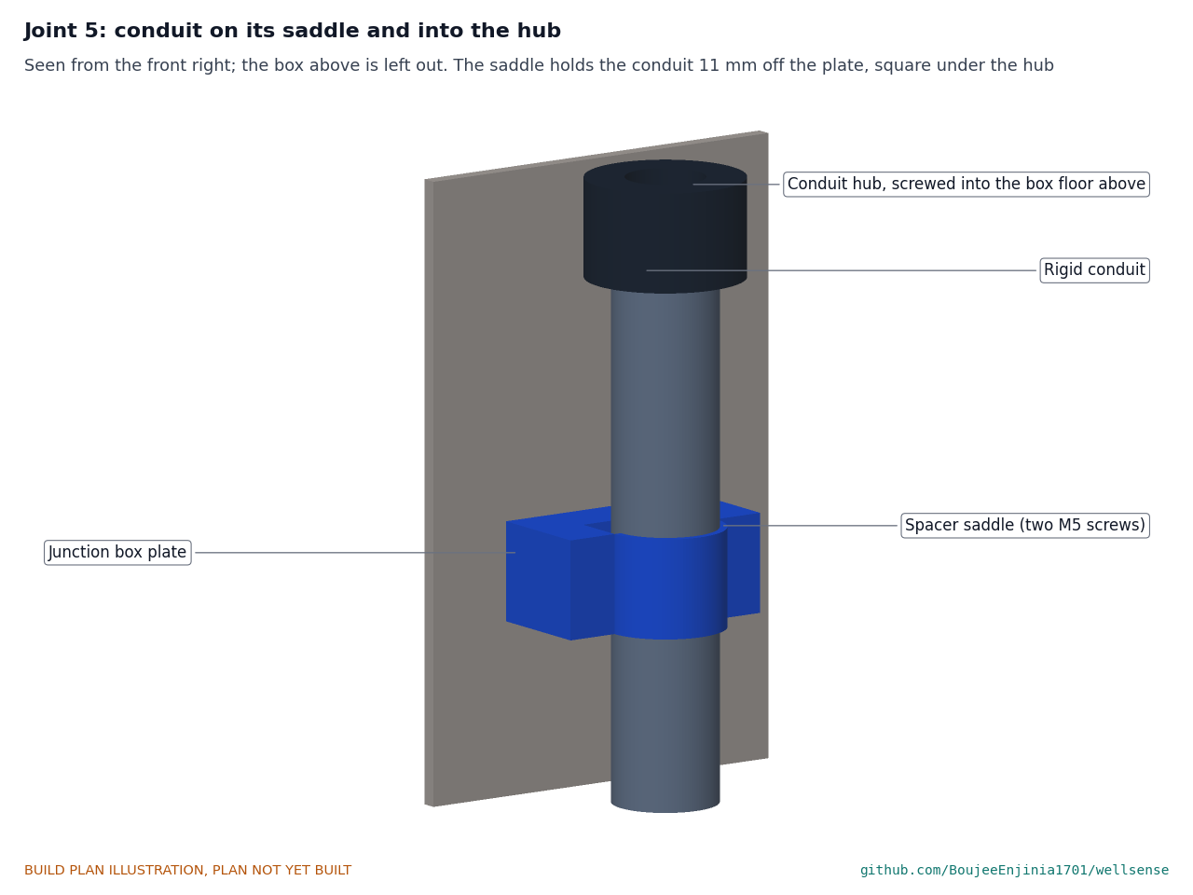
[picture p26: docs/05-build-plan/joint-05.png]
Figure 15. Joint 5: conduit on its saddle and into the hub


*Figure 15. The spacer saddle holds the conduit 11 mm off the plate, square under the hub.*

The short leg stands upright 22 mm in front of the plate and screws into the hub under the box. Two spacer saddles, 100 and 230 mm up the plate, hold it with two M5 screws each through the plate, nyloc nuts behind. The long leg runs level 720 mm above the ground toward the well and takes the flexible tail's connector at its end.

**Check before moving on.** Both legs square to each other; the ends are smooth inside.

### 3.7 Seal plate with spigot rings, gasket and wraps

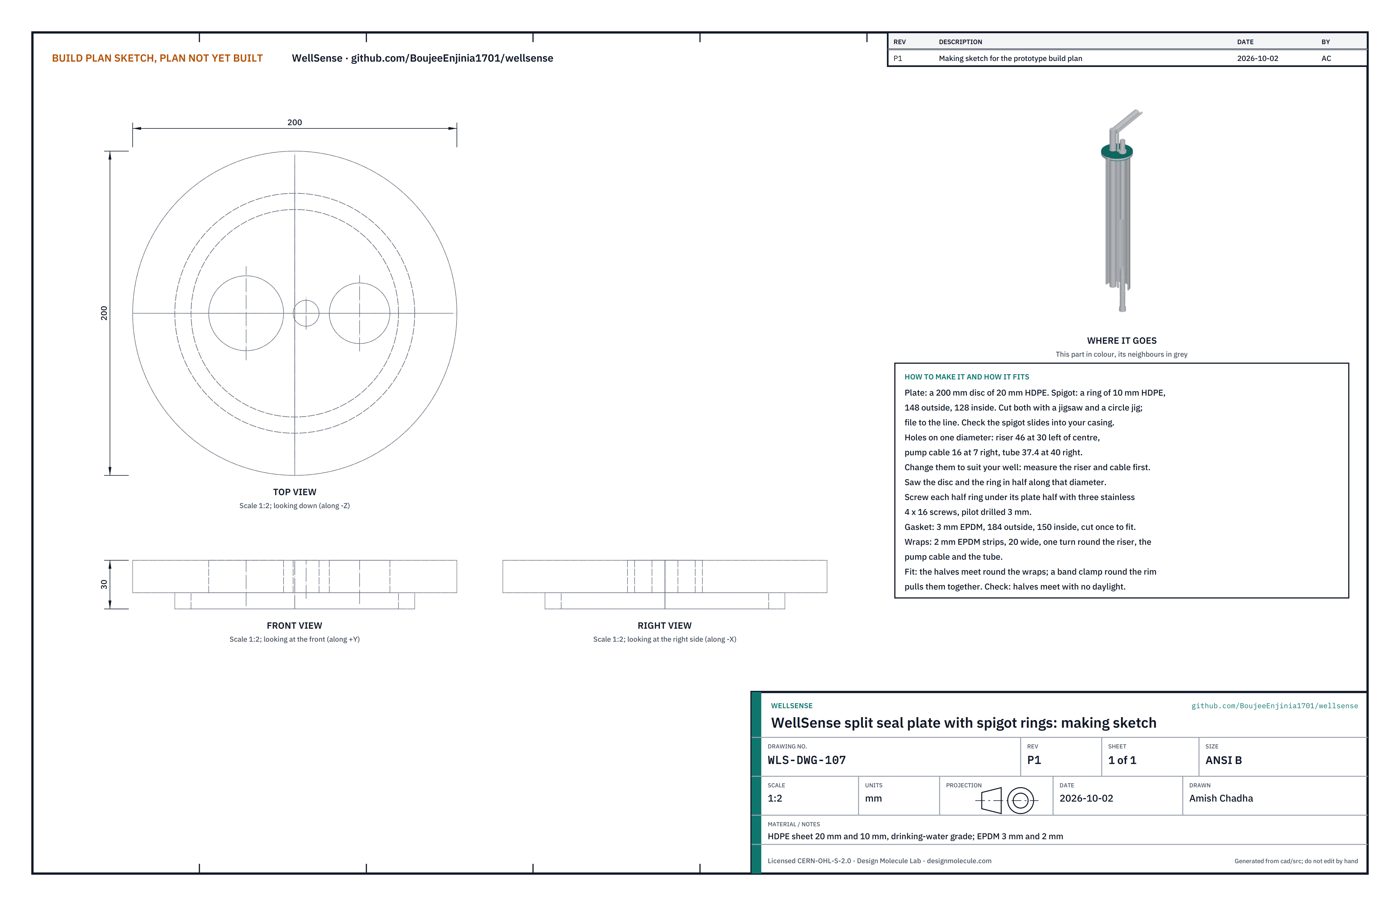
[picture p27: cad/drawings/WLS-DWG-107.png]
Figure 16. Making sketch of the seal plate


*Figure 16. Seal plate making sketch (WLS-DWG-107).*

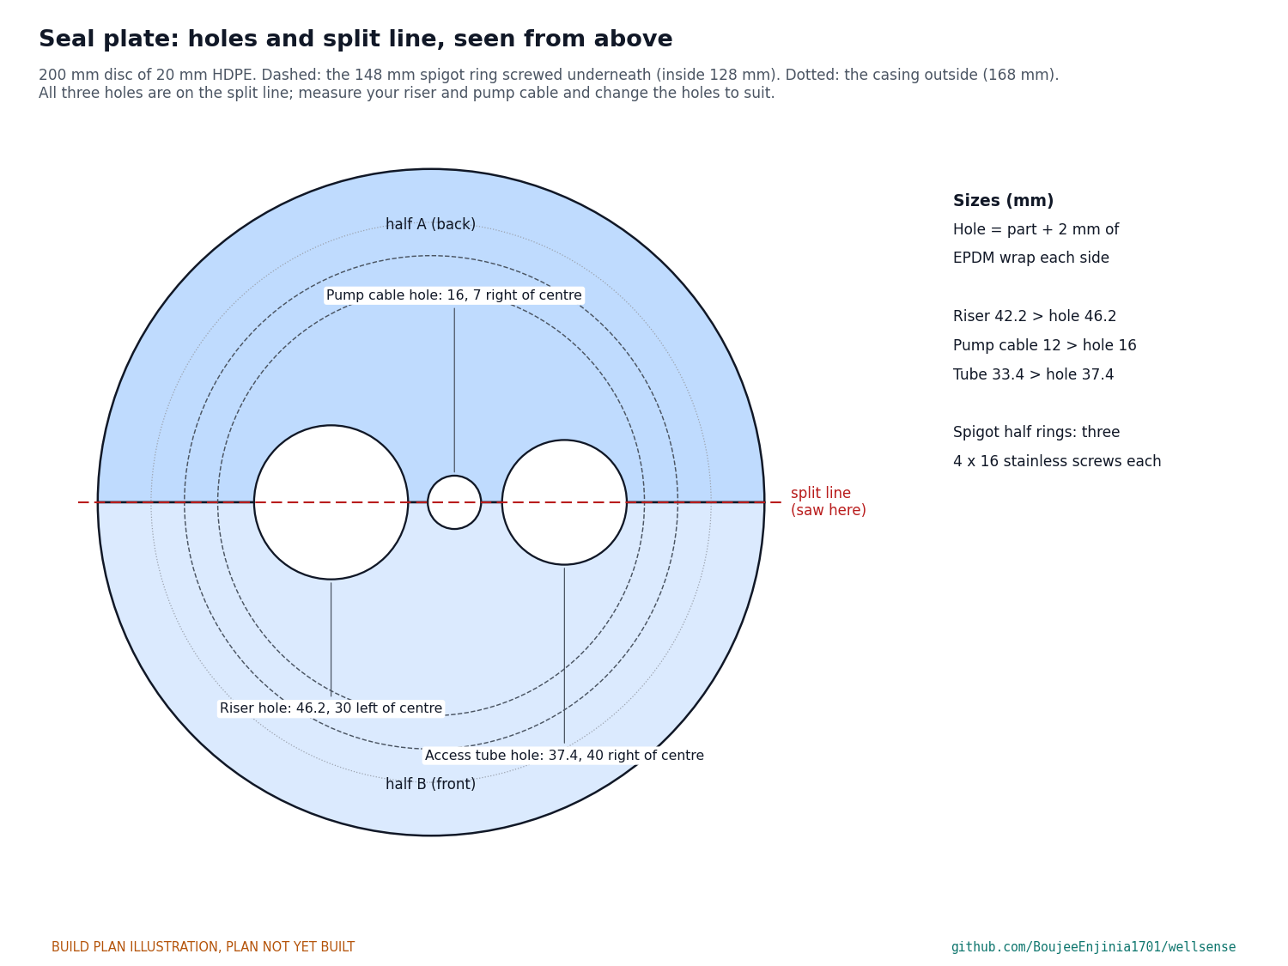
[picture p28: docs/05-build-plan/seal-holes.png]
Figure 17. Seal plate holes and split line


*Figure 17. The three holes all lie on the split line.*

**What it is and what it is made from.** The cover that closes the top of the casing round the riser, the pump cable and the access tube, and carries the tube. Drinking-water grade HDPE sheet 20 mm (plate) and 10 mm (spigot ring); EPDM rubber sheet 3 mm (gasket) and 2 mm (wraps).

**How to make it.**

1. Measure the riser and the pump cable at the well. The design uses a 42.2 mm riser and a 12 mm cable; each hole is the part plus 2 mm of rubber each side.
2. Cut a 200 mm disc from the 20 mm sheet and a ring 148 mm outside and 128 mm inside from the 10 mm sheet, with a jigsaw and a circle jig, then file to the line. Check the ring slides into the casing.
3. Scribe a diameter across the disc. On it, bore the riser hole 46 mm at 30 left of centre, the pump cable hole 16 mm at 7 right and the tube hole 37.4 mm at 40 right, with hole saws or a step drill.
4. Saw the disc and the ring in half along that diameter, keeping the cut straight.
5. Screw each half ring under its plate half, centred, with three stainless 4 x 16 screws in 3 mm pilot holes.
6. Cut the gasket from 3 mm EPDM, 184 mm outside and 150 mm inside, and cut it once so it can go round the riser.
7. Cut three wraps from 2 mm EPDM, 20 mm wide, each one turn long for the riser, the pump cable and the tube.
8. Take the hex screw out of the rim band clamp and fit the security-head screw in its place, so the band can only be undone with the matching bit.

**How it fits the parts next to it.**

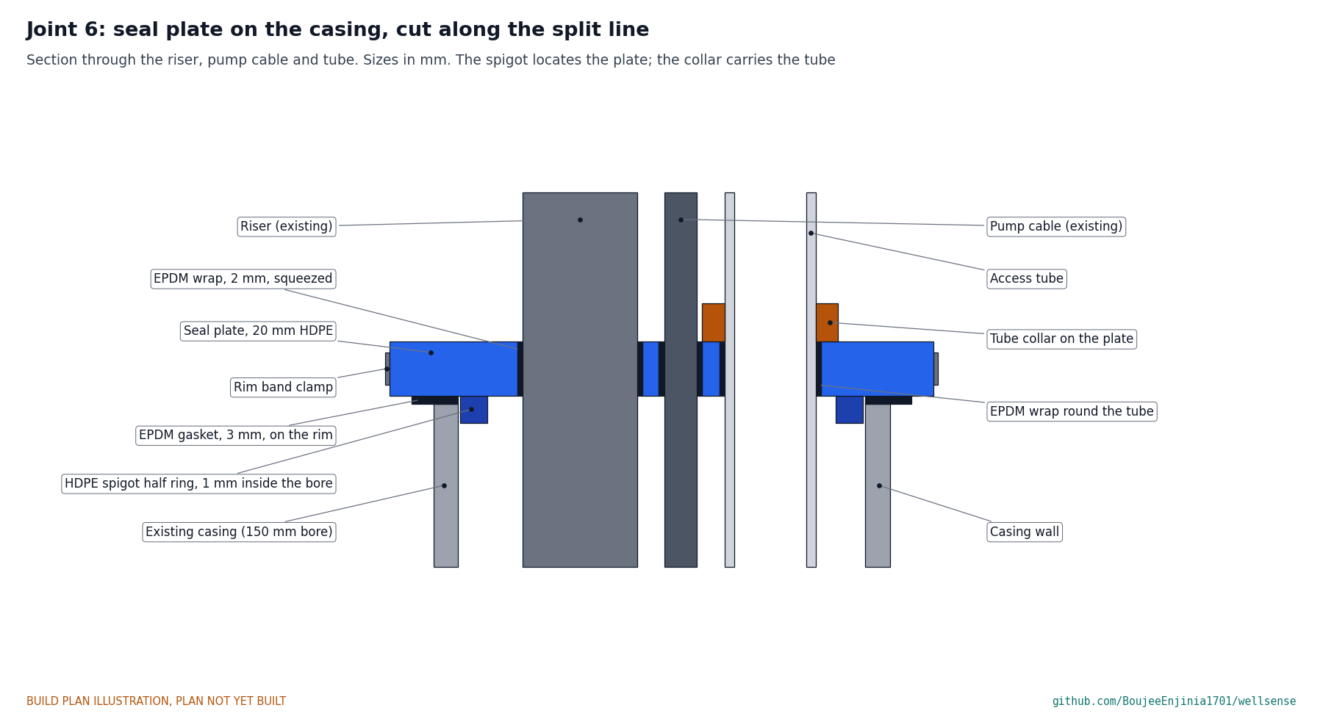
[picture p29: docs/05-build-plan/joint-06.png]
Figure 18. Joint 6: seal plate on the casing, cut on the split line


*Figure 18. The spigot sits inside the casing, the gasket on its rim; the collar on the plate carries the tube.*

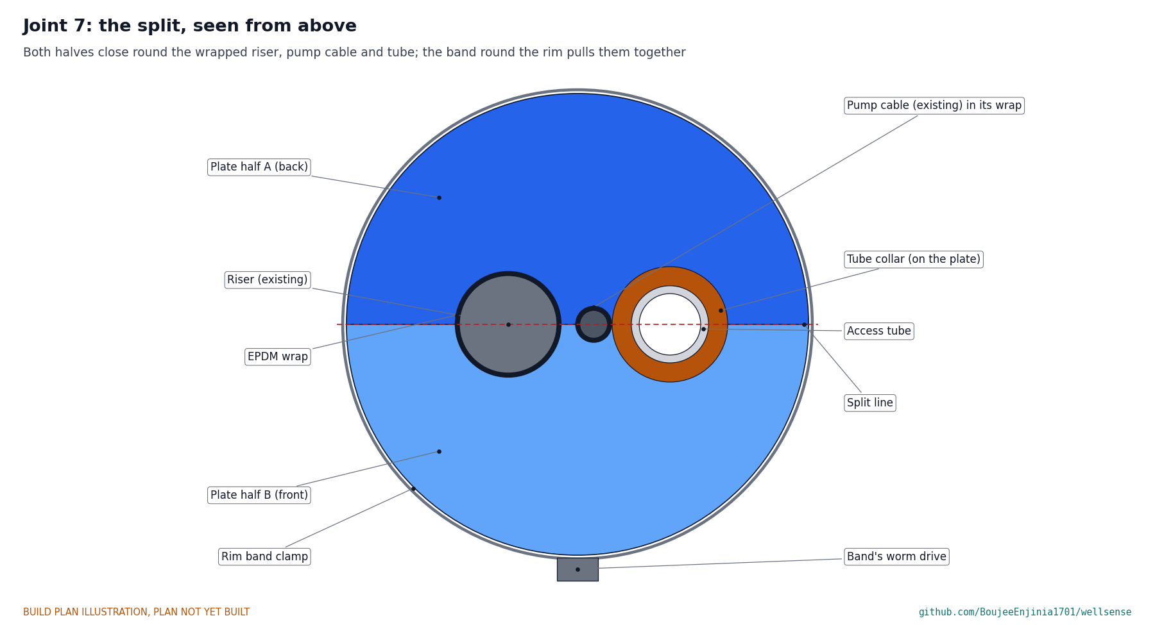
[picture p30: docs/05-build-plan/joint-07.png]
Figure 19. Joint 7: the split, seen from above


*Figure 19. Both halves close round the wrapped riser, pump cable and tube; the band round the rim pulls them together.*

The gasket lies on the casing rim and the plate halves lie on the gasket, their spigots 1 mm inside the casing bore. Each wrap fills the gap between its part and the plate, so tightening the rim band squeezes all three. The tube collar sits on top of the plate. The rim band's security-head screw sits on the band's housing, on the side of the plate away from the riser, with its head clear of the plate rim.

**Check before moving on.** On a trial fit round a short length of riser, the halves meet with no daylight at the split.

### 3.8 Access tube, drilled, with its end cap

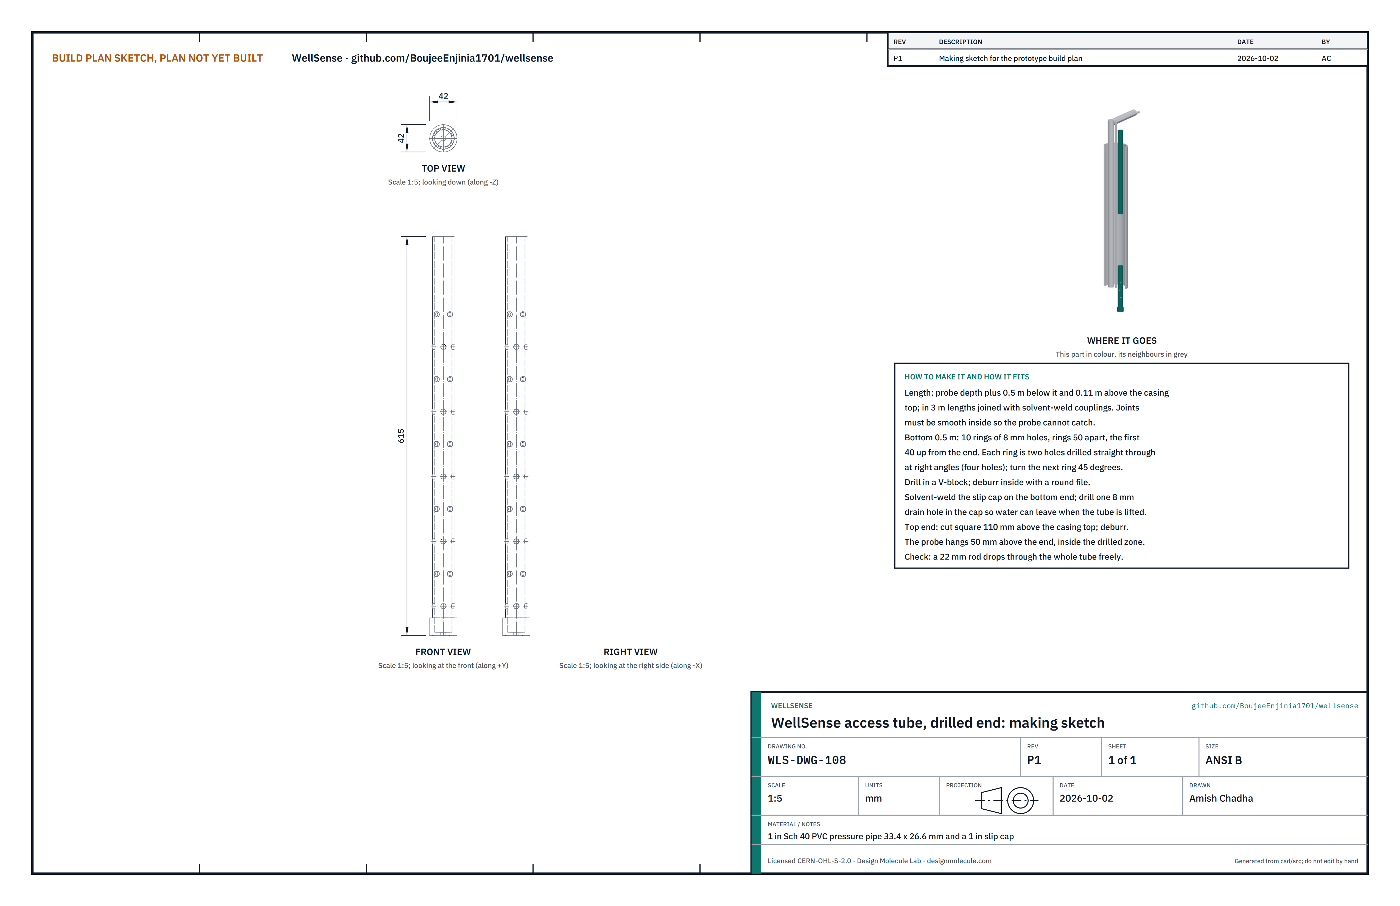
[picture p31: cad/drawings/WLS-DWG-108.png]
Figure 20. Making sketch of the access tube's drilled end


*Figure 20. Access tube making sketch (WLS-DWG-108), drilled end.*

**What it is and what it is made from.** The plastic tube the probe hangs in, beside the riser, so the probe cannot tangle with the pump. 1 in Sch 40 PVC pressure pipe, 33.4 mm outside and 26.6 mm bore, in 3 m lengths, with a 1 in slip cap on the bottom.

**How to make it.**

1. Work out the length: the probe depth plus 0.5 m below the probe plus 0.11 m above the casing top. Join 3 m lengths with solvent-weld couplings, wiping the inside of each joint smooth.
2. Over the bottom 0.5 m, drill ten rings of 8 mm holes 50 mm apart, the first 40 mm up from the end. Each ring is two holes drilled straight through at right angles (four holes); turn the next ring 45°. Hold the tube in a V-block to drill.
3. Deburr each hole inside with a round file.
4. Solvent-weld the slip cap on the bottom end and drill one 8 mm drain hole in it.
5. Cut the top square and deburr.

**How it fits the parts next to it.**

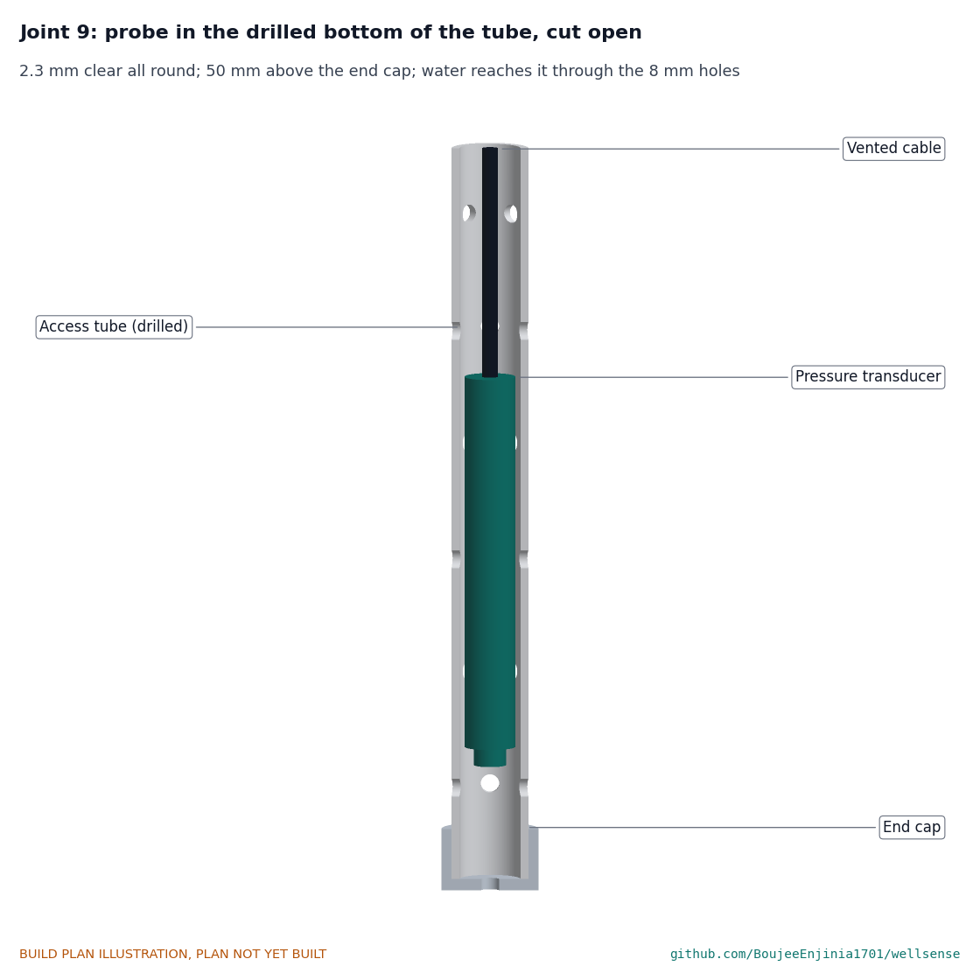
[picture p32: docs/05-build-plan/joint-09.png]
Figure 21. Joint 9: probe in the drilled bottom of the tube


*Figure 21. The 22 mm probe hangs 50 mm above the end cap with 2.3 mm clear all round; water reaches it through the holes.*

The tube hangs beside the riser, 32 mm clear of it and 18 mm from the casing wall, from a collar resting on the seal plate.

**Check before moving on.** A 22 mm rod drops through the whole tube freely.

### 3.9 Tube cap with eye bolt and support grip

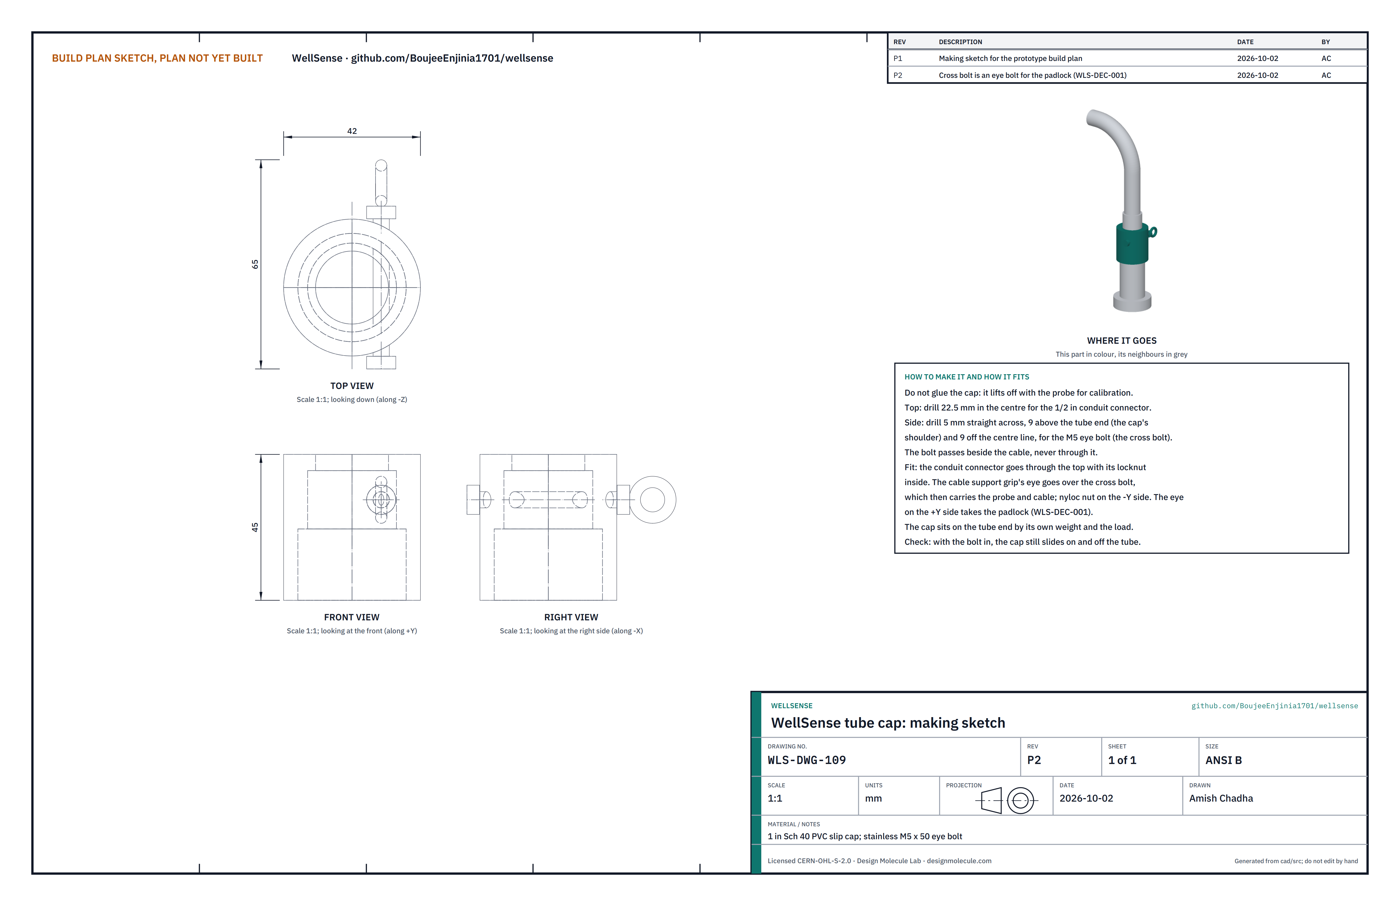
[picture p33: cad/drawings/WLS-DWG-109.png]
Figure 22. Making sketch of the tube cap


*Figure 22. Tube cap making sketch (WLS-DWG-109).*

**What it is and what it is made from.** The cap on the top of the access tube; the probe hangs from it and the conduit's flexible tail plugs into it. A 1 in Sch 40 PVC slip cap, a stainless M5 x 50 eye bolt (a bolt with a swing eye in place of the head) with a nyloc nut, and a stainless single-eye cable support grip for 6 to 8 mm cable.

**How to make it.**

1. Do not glue the cap: it must lift off.
2. Drill 22.5 mm in the centre of the top for the conduit connector.
3. Drill 5 mm straight across the cap, 9 mm above the shoulder the tube end stops against and 9 mm off the centre line, for the eye bolt, which acts as the cross bolt.

**How it fits the parts next to it.**

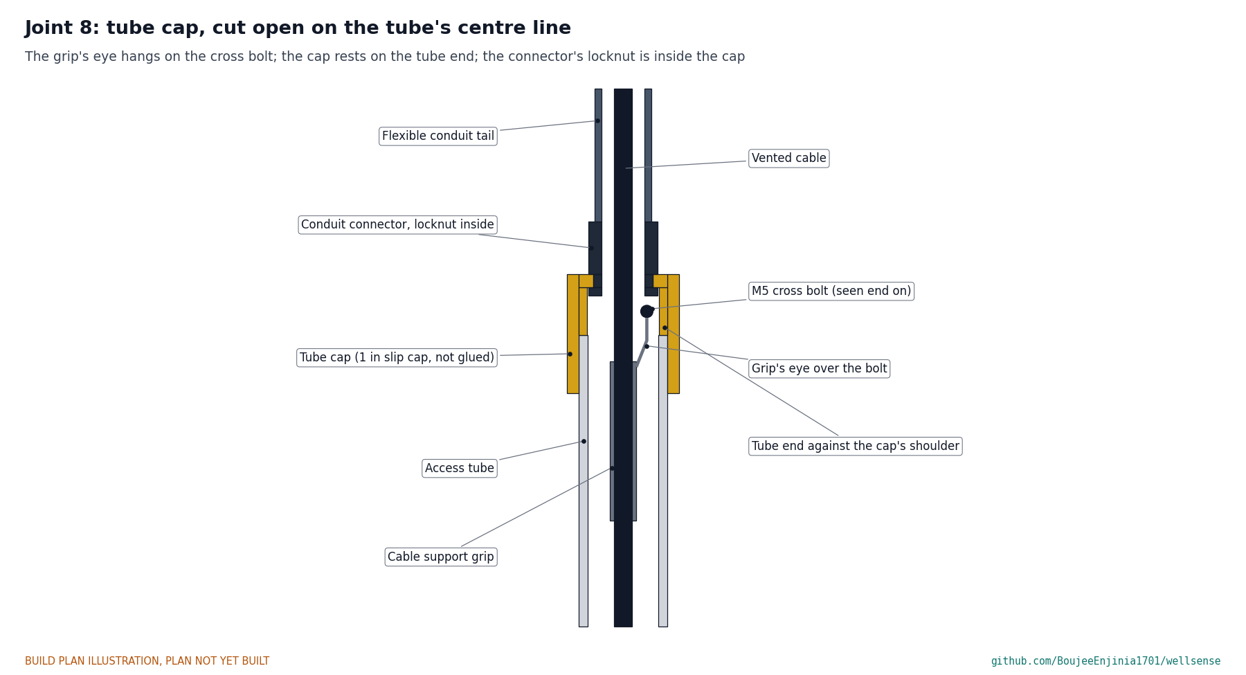
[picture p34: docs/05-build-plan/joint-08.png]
Figure 23. Joint 8: tube cap, cut open


*Figure 23. The grip's eye hangs on the cross bolt; the cap rests on the tube end; the connector's locknut is inside the cap.*

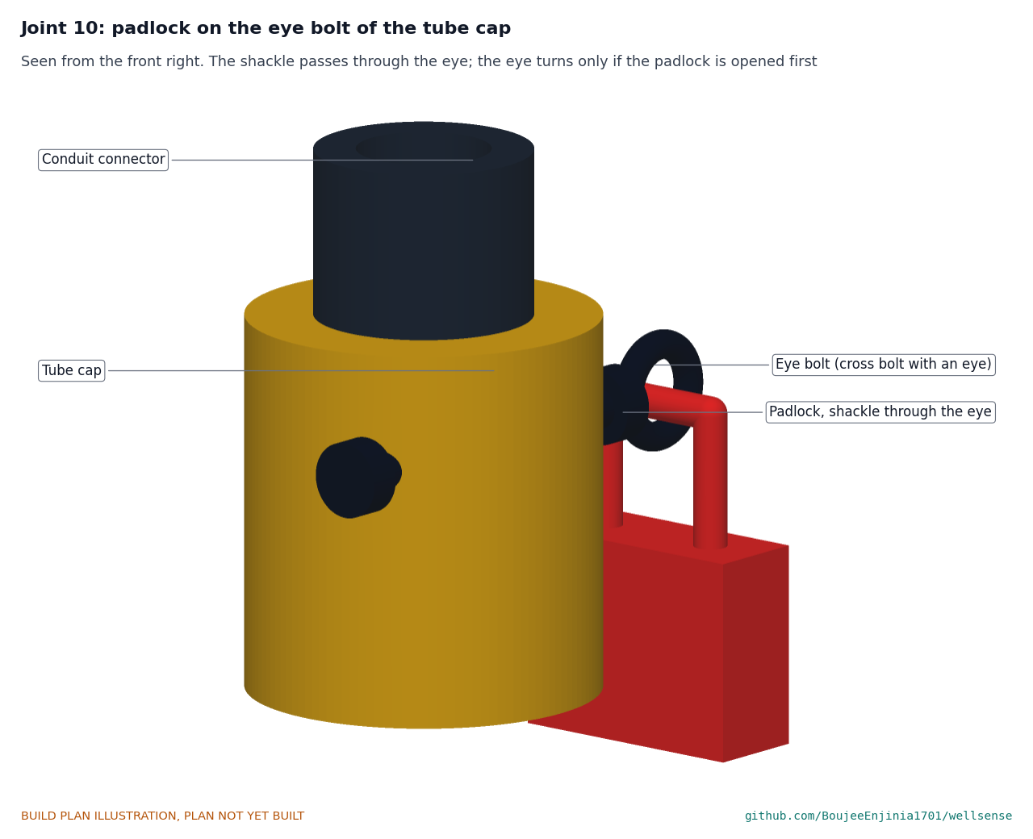
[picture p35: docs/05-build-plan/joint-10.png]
Figure 23a. Joint 10: padlock on the eye bolt of the tube cap


*Figure 23a. The eye of the eye bolt stands out on the right-hand side of the cap, and the padlock's shackle passes through it.*

The connector goes through the top with its locknut inside. The support grip is pushed onto the cable at the mark for the probe depth, and its eye goes over the cross bolt, which carries the probe and cable. The bolt passes beside the cable, 3 mm clear of it. Its swing eye stands out of the cap on one side, with the nyloc nut on the other, and takes the padlock (step 18). The padlock stops the eye bolt being unscrewed, so the grip and the probe cannot be freed; it does not stop the cap being lifted off the tube, which is the job of the lockable steel wellhead cover at sites where the first visit shows open access or livestock.

**Check before moving on.** With the bolt in, the cap still slides on and off the tube by hand, and a 4 mm rod passes through the eye.

### 3.10 FieldNode core

Build one FieldNode core to the FieldNode build plan (FND-BLD-001), without the sun shield unless the site's hottest days pass 30 °C. WellSense uses it unchanged: its V-blocks fit this post, and the WellSense lead plugs into its sensor port A. Leave its fuse out and its cell out of the holder until its own safety stops say otherwise.

### 3.11 Bought components

Buy to specification, not brand. Line numbers are those of the bill of materials.

- **Pressure transducer (line 1).** Vented (gauge), 0 to 10 m of water, 4 to 20 mA two-wire, 12 to 30 V supply, 0.25 % of full scale class, 316 stainless body 22 mm diameter or less, IP68, with a drinking-water certificate.
- **Vented cable (line 2).** Polyurethane or polyethylene jacket, two cores of 0.2 mm² or more, aramid strain member of 400 N or more, vent capillary, about 7 mm; the probe depth plus 2.7 m.
- **Access tube and end cap (line 3).** As section 3.8.
- **Seal plate parts (line 4).** HDPE and EPDM sheet as section 3.7; a stainless worm-drive band clamp for 180 to 210 mm (its hex screw is swapped for the security-head screw of line 16); a split aluminium shaft collar for 1-5/16 in (33.4 mm) pipe; six stainless 4 x 16 screws.
- **Tube cap parts (line 5).** As section 3.9, with an M5 x 50 stainless eye bolt.
- **Junction box (line 6).** As section 3.4, with an M16 gland for 4 to 8 mm cable, an M12 gland for 3 to 6.5 mm cable, a replaceable silica gel breather in an M20 thread, and four M5 x 16 button-head screws with nyloc nuts.
- **Interface modules (line 7).** As Table 2, with M3 screws and 6 mm nylon standoffs.
- **Barometric sensor (line 9).** BMP390 or BME280 class module in a louvred housing about 36 mm across with a flat two-screw flange, and a 0.3 m lead.
- **Post set (line 10).** The pipe and cap of section 3.1, the plate and V-blocks of sections 3.2 and 3.3, two 12 mm stainless worm-drive band clamps, four M4 x 12 countersunk screws.
- **Footing (line 13).** One 25 kg bag of premixed concrete and a bucket of gravel.
- **Conduit set (line 14).** The rigid conduit of section 3.6; 0.3 m of 1/2 in liquid-tight flexible conduit with two straight connectors; two 1/2 in spacer saddles with M5 screws and nyloc nuts; one 1/2 in conduit hub.
- **FieldNode lead (line 15).** 1.5 m of four-core screened cable, about 0.2 mm², with an M12 A-coded 5-pin plug, IP67, wired to pins 1 to 4 and leaving pin 5 unconnected; cable ties.
- **Locks (line 16).** One stainless security-head screw and its bit; two keyed-alike 20 mm stainless padlocks with a 4 mm shackle; one padlockable stainless hasp kit with two M3 screws and sealing washers for each tab.

## 4. Putting it together

In each picture the parts already fitted are grey and the part being fitted is in colour, with an arrow showing the way it goes in. Steps 1 to 11 build the surface unit; steps 12 to 18 fit the wellhead and lock it.

### Step 1: post into its footing

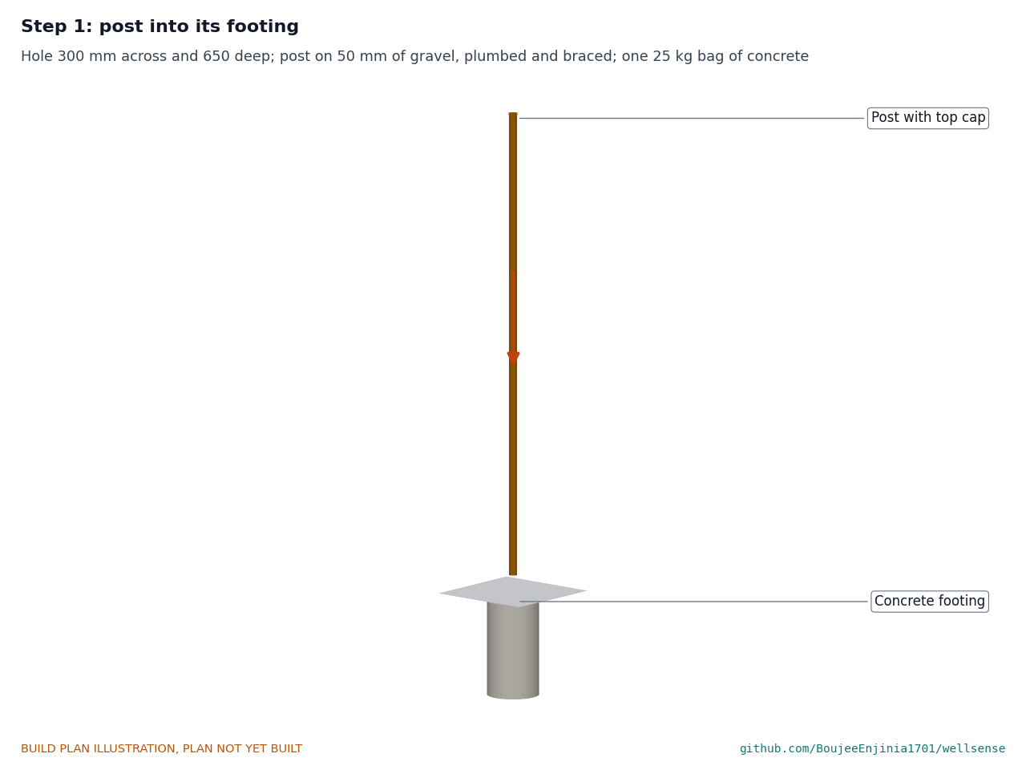
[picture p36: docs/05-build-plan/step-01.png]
Step 1


Dig a hole 300 mm across and 650 mm deep, 750 mm from the well's centre. Put in 50 mm of gravel, stand the post on it with its 600 mm mark at ground level, plumb it both ways and brace it. Pour one bag of concrete, slope the top away from the post, and leave it to cure for two days before loading the post.

### Step 2: V-blocks onto the junction box plate

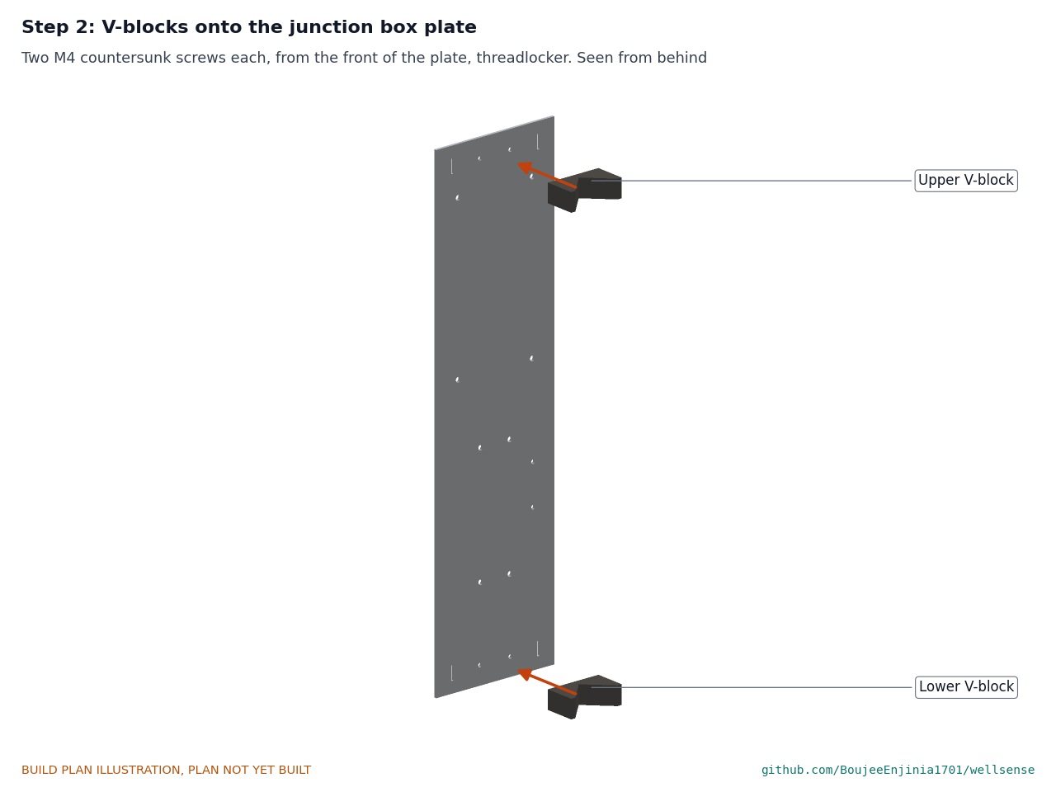
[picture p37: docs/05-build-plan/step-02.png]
Step 2


Two M4 countersunk screws per block, from the front of the plate, with medium threadlocker, snug. The V opens away from the plate.

### Step 3: hub, glands and breather into the box

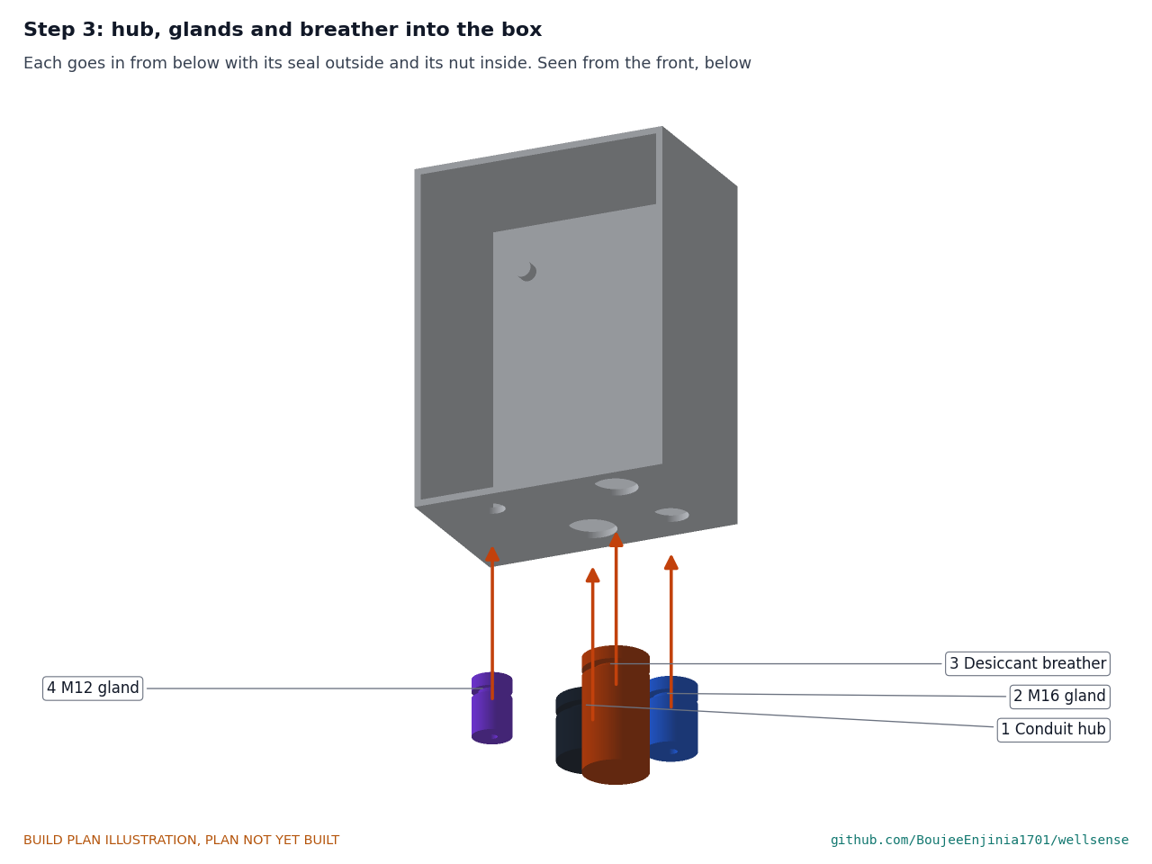
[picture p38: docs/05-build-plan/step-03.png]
Step 3


Each goes in from below with its seal outside and its nut inside, tightened to the maker's torque.

### Step 4: build the internal plate

Step 4

Fit the modules and terminal strip on M3 screws and standoffs and wire them as Figure 13. **Hold point:** the wiring checks of section 3.5.1 pass before going on.

### Step 5: junction box onto the plate

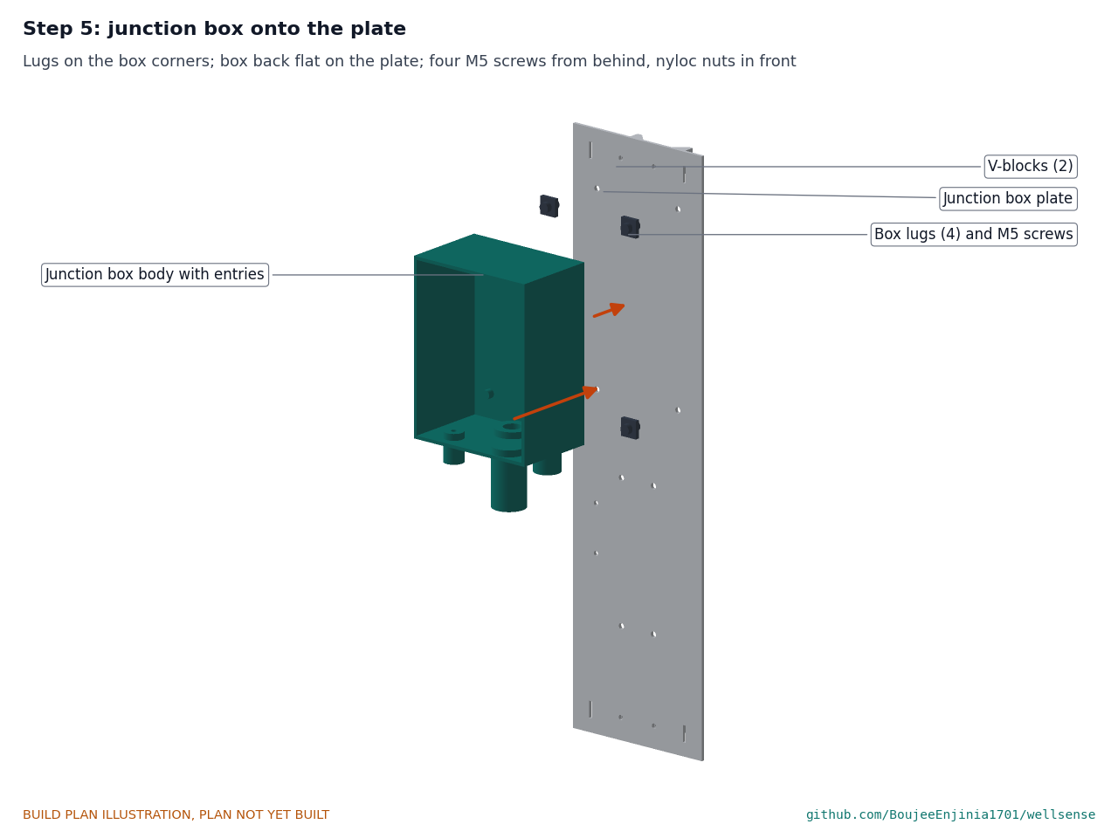
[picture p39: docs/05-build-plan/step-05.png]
Step 5


Hold the box flat on the front of the plate, centred, its bottom 310 mm up the plate. Four M5 button-head screws through the lugs from behind the plate, nyloc nuts in front, snug.

### Step 6: internal plate into the box

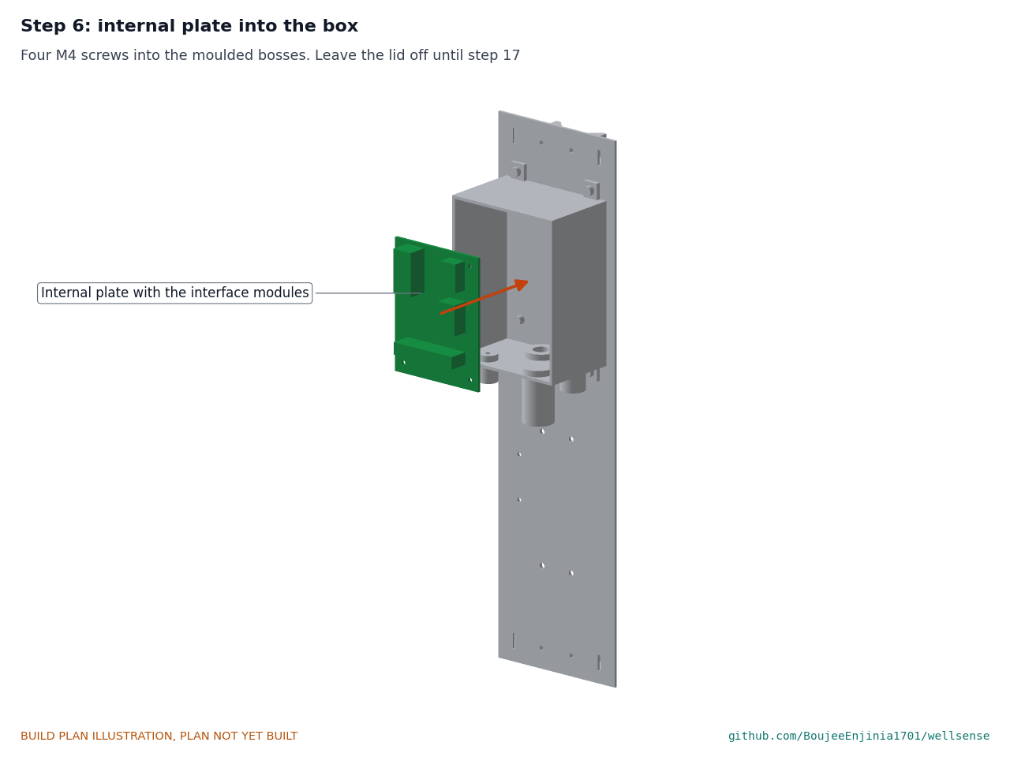
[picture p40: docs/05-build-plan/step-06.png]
Step 6


Four M4 screws into the bosses. Leave the lid off until step 17.

### Step 7: barometric housing onto the plate

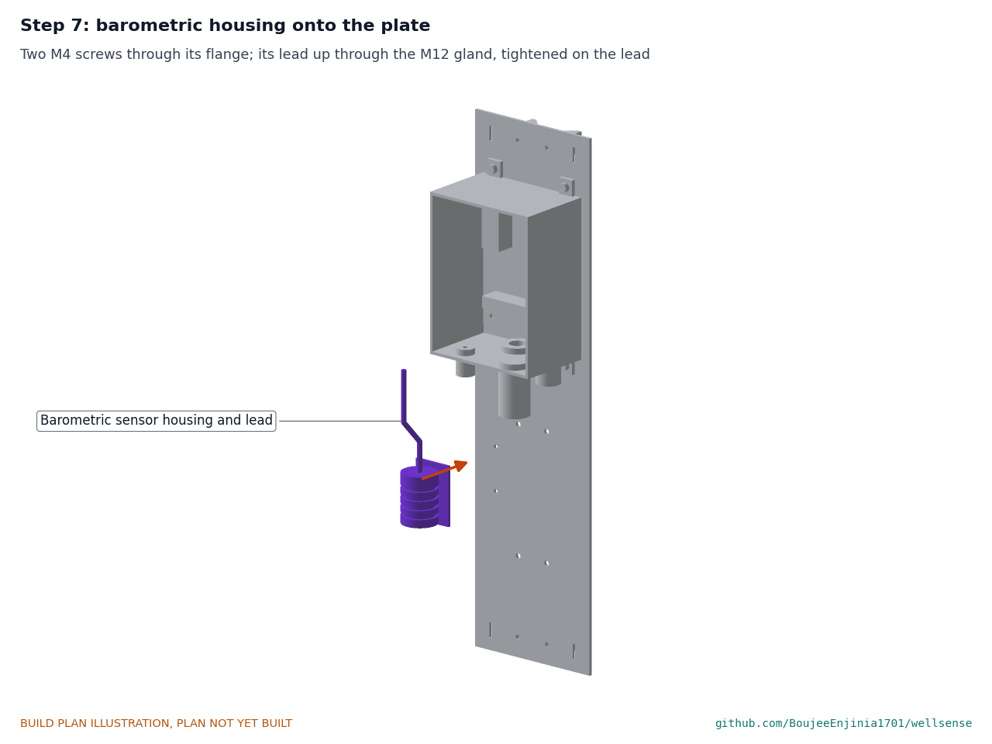
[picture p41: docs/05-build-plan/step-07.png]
Step 7


Two M4 screws with nyloc nuts through its flange and the plate, louvres down. Feed its lead up through the M12 gland and tighten the gland on it.

### Step 8: junction box onto the post

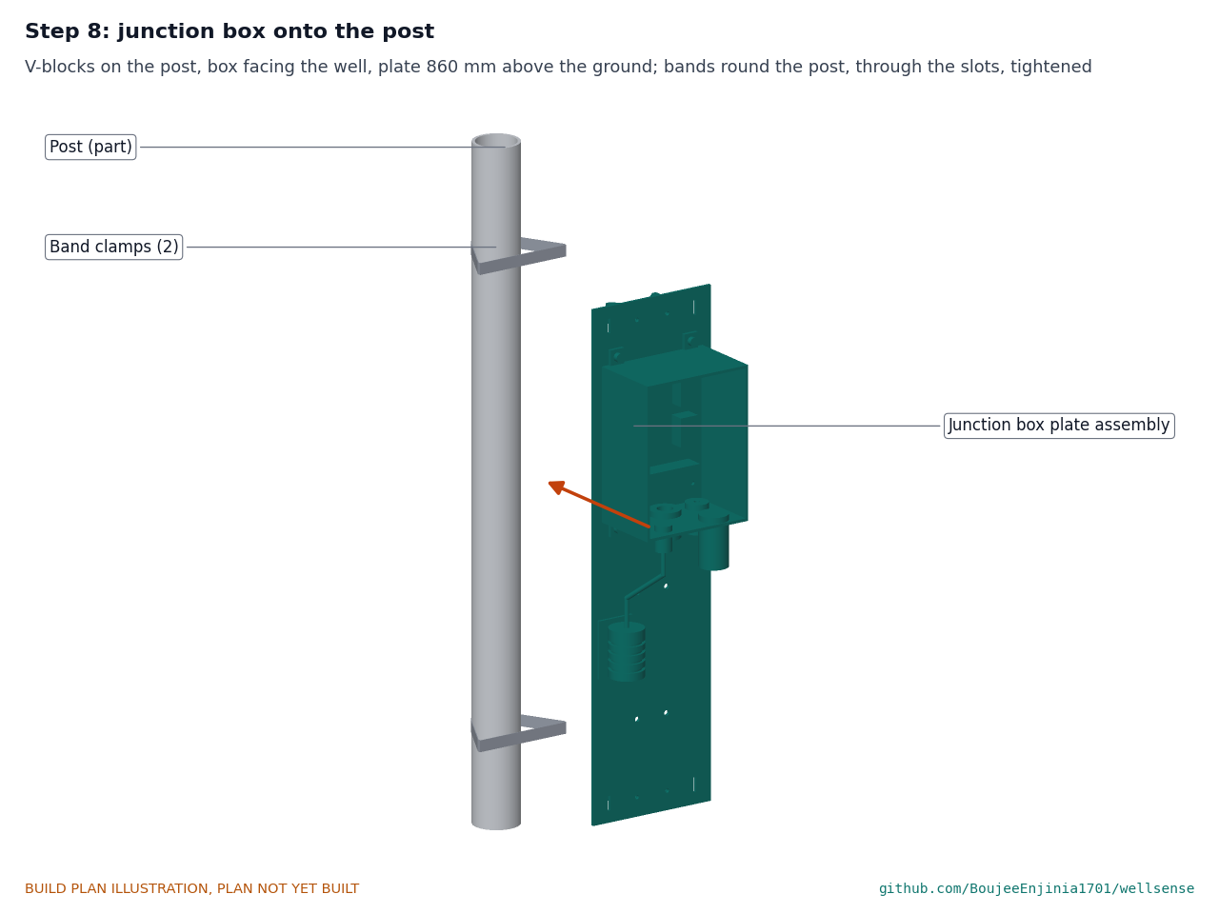
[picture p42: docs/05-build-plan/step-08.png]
Step 8


Hold the plate with both V-blocks on the post, the box facing the well and the plate's bottom edge 860 mm above the ground. Pass each band round the post, through its two slots and across the front of the plate, with the worm-drive housing at the back of the post. Tighten both bands to the band maker's torque and record it.

### Step 9: FieldNode core onto the post

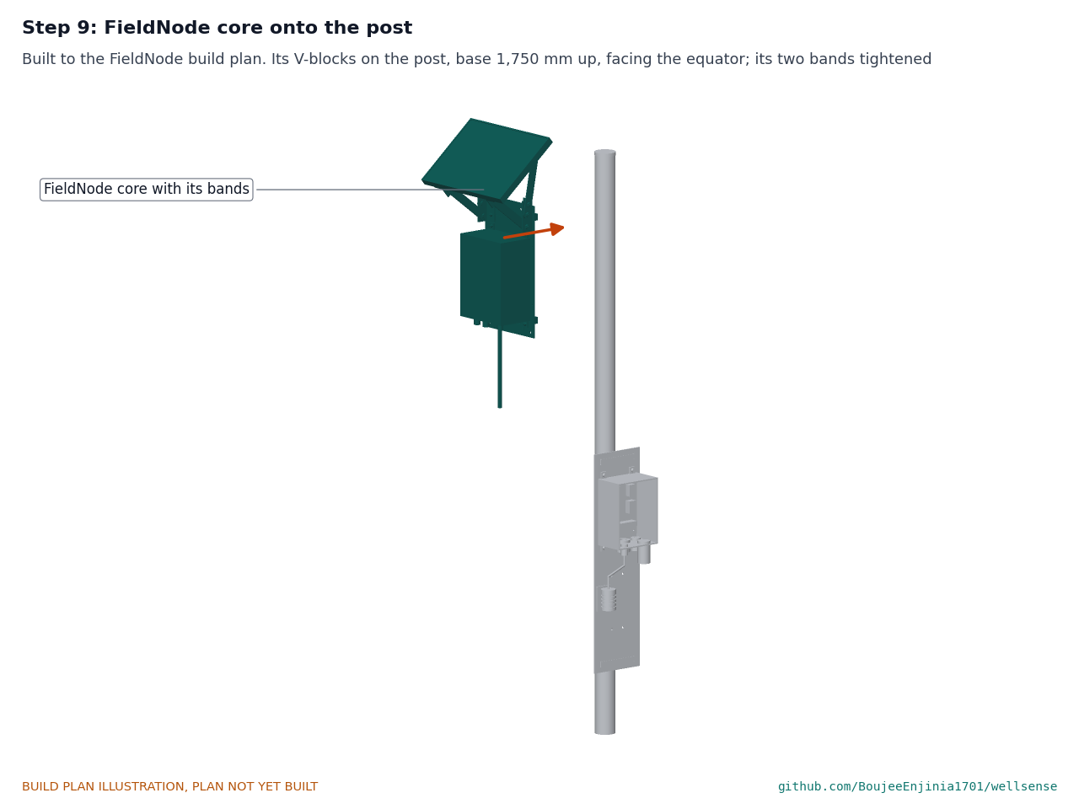
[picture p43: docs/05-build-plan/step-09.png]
Step 9


The core is built to its own plan. Hold it with its V-blocks on the post, the panel facing the equator and its enclosure's base 1,750 mm above the ground, and tighten its two bands as its plan says.

### Step 10: FieldNode lead from the box to port A

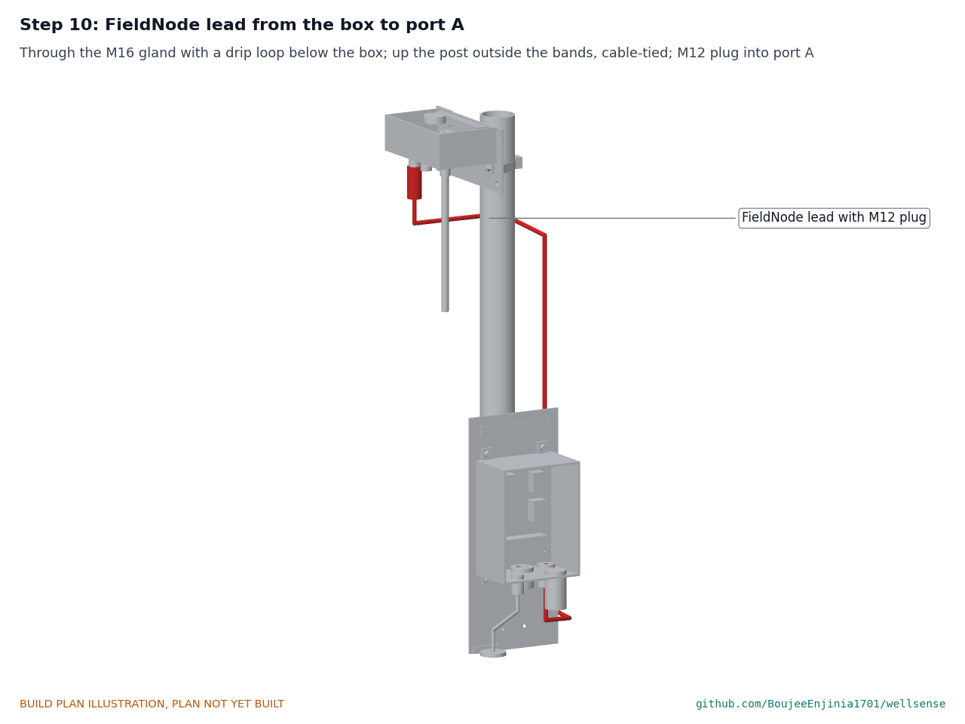
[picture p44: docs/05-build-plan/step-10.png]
Step 10


Push the lead's bare end up through the M16 gland into the box and tighten the gland. Leave a drip loop below the box, run the lead round the edge of the plate and up the side of the post outside the bands, cable-tied every 200 mm, and plug the M12 plug into port A. **Hold point:** the FieldNode core's fuse is still out.

### Step 11: rigid conduit into the hub and saddles

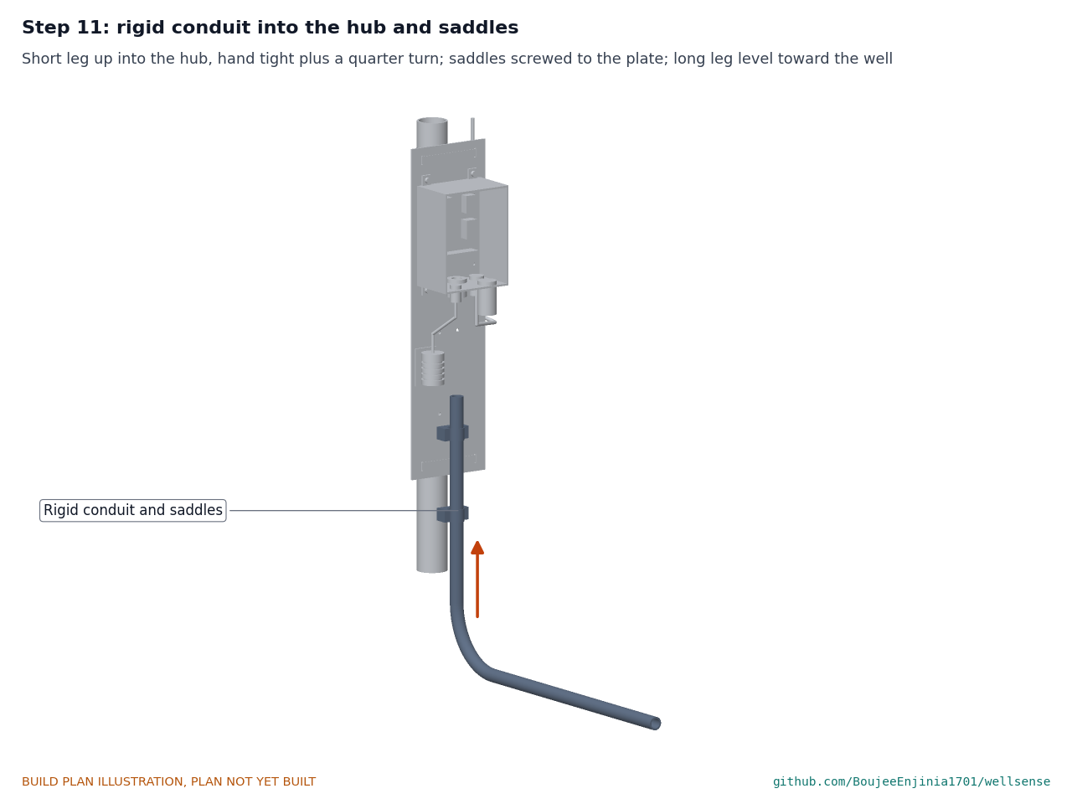
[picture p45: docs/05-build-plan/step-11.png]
Step 11


Screw the short leg up into the hub, hand tight plus a quarter turn, with the long leg pointing at the well. Fit the two spacer saddles round the upright leg and screw them to the plate. Check the long leg is level.

### Step 12: access tube down the casing

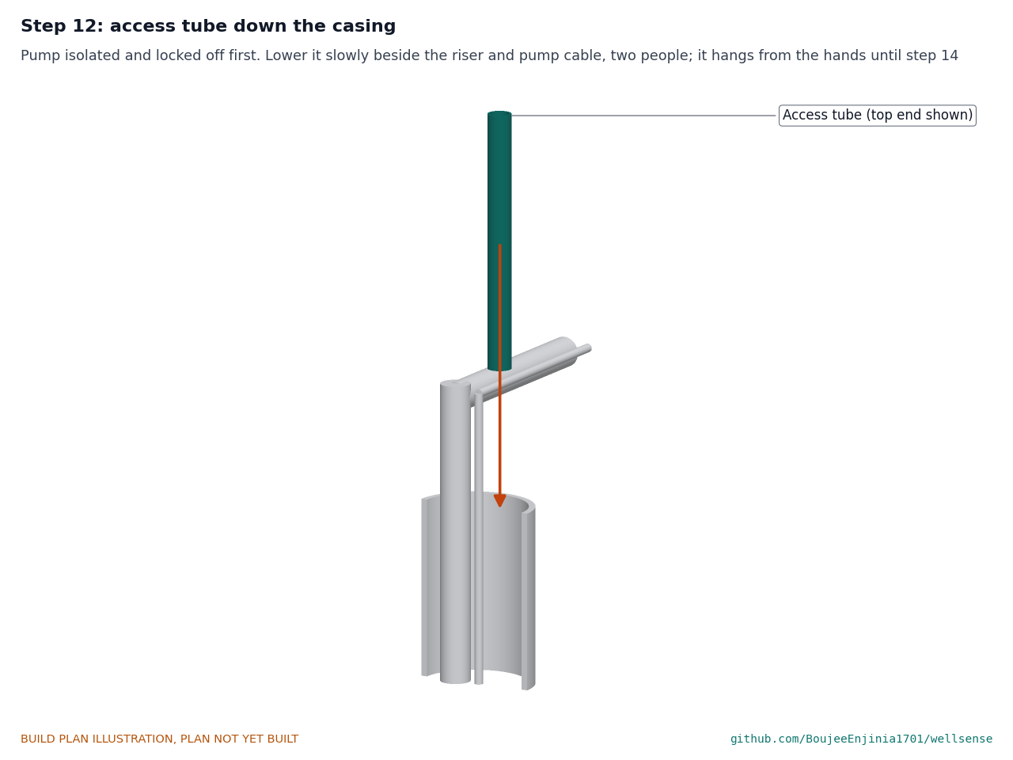
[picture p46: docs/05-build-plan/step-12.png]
Step 12


**Hold point:** at a real well, safety stop S5 first. Disinfect the tube. With two people, lower it end cap first beside the riser and pump cable, hand over hand, until its top is about 110 mm above the casing; hold it there.

### Step 13: gasket, wraps and the two seal plate halves

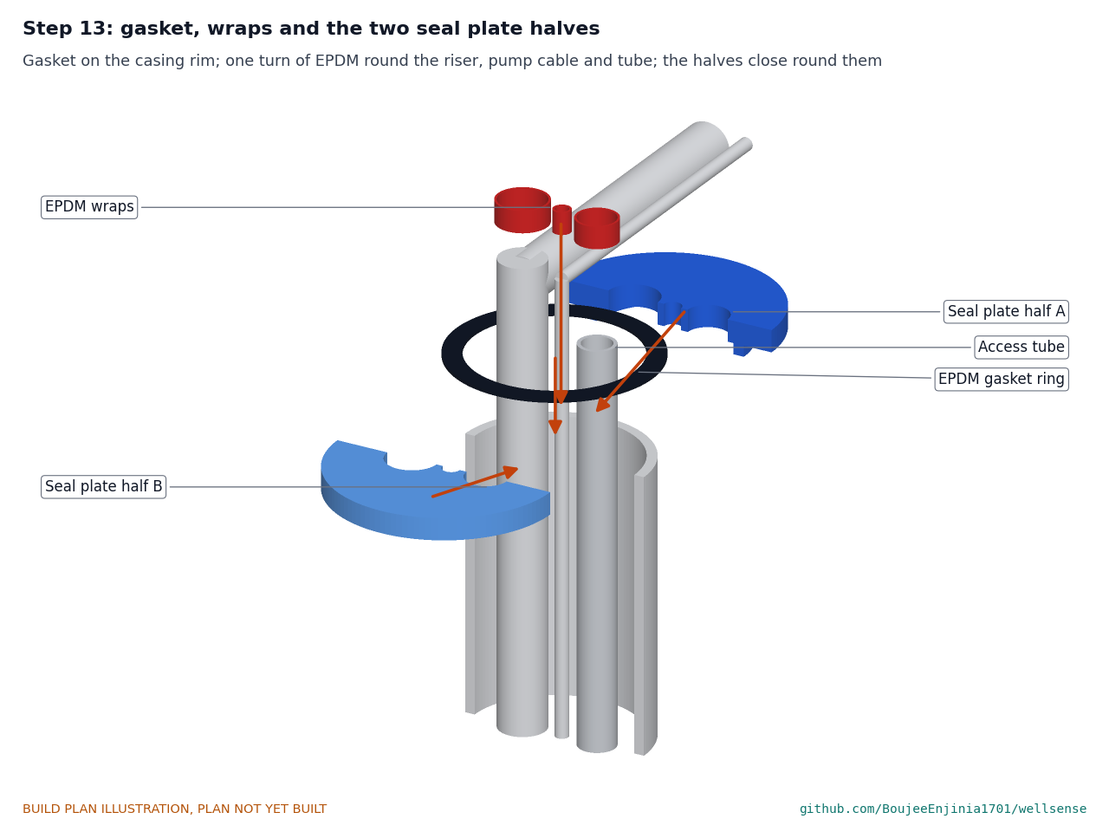
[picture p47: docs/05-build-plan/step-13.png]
Step 13


Lay the gasket on the casing rim. Wrap one turn of EPDM round the riser, the pump cable and the tube at the height the plate will sit. Bring the two halves in from each side so their spigots drop inside the casing and they close round the three wraps.

### Step 14: rim band and tube collar

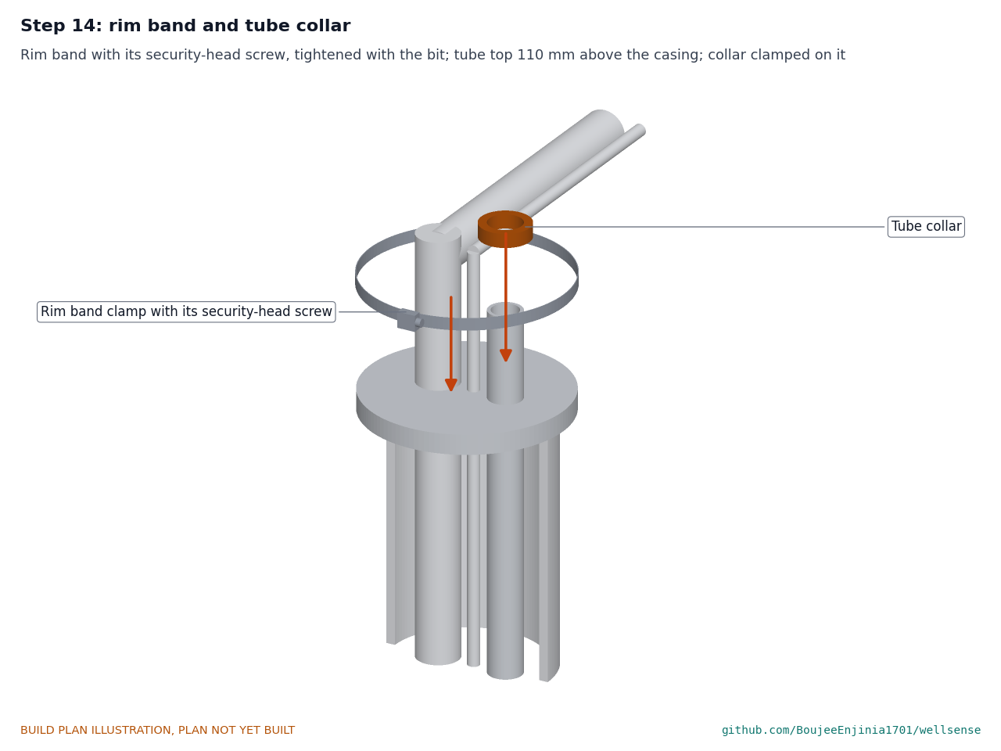
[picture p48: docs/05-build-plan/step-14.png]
Step 14


Put the band round the rim and tighten it with the security-head bit until the halves meet. Set the tube so its top is 110 mm above the casing top, clamp the collar on the tube and let it rest on the plate.

### Step 15: thread the cable

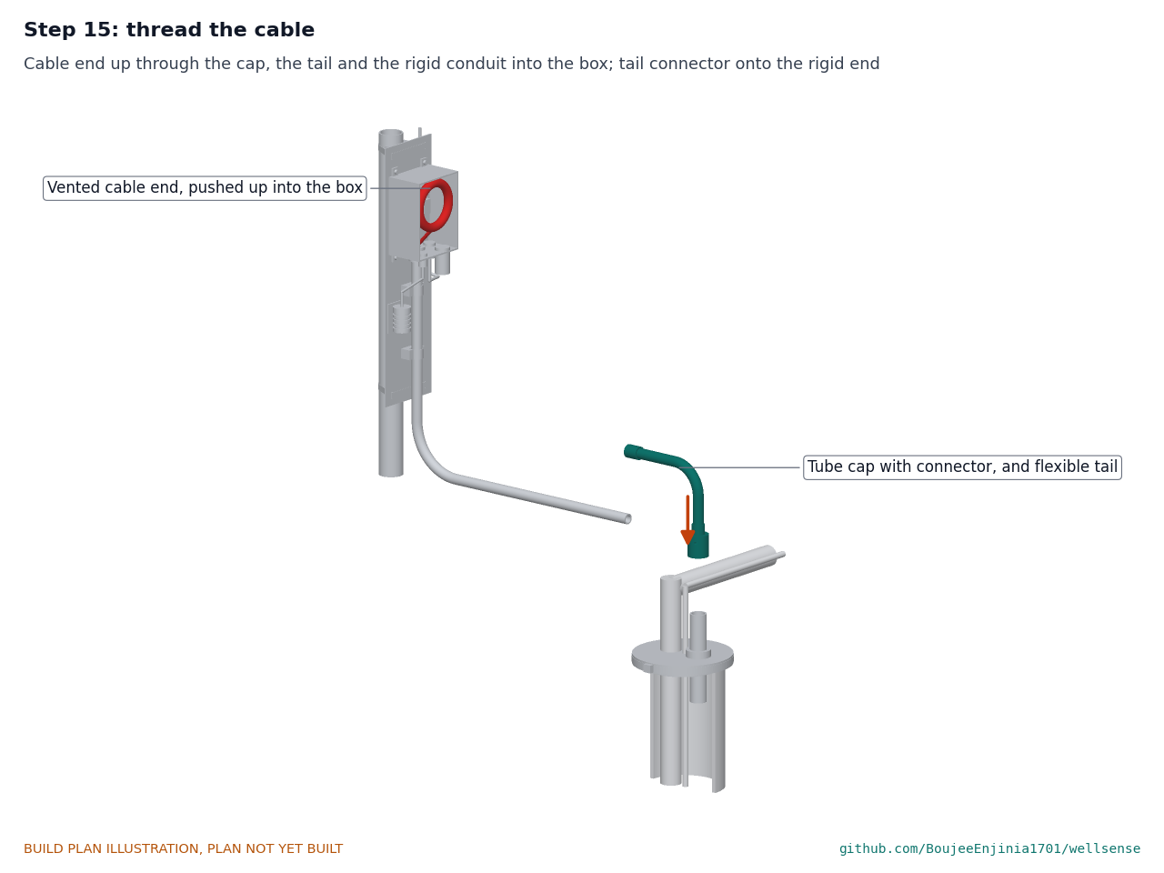
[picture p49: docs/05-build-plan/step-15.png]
Step 15


Fit the conduit connector through the cap and tighten its locknut. Push the cable's free end up through the cap, the flexible tail and the rigid conduit until it comes out of the hub into the box; then screw the tail's far connector onto the end of the rigid conduit. The probe stays on the bench.

### Step 16: lower the probe and hang it

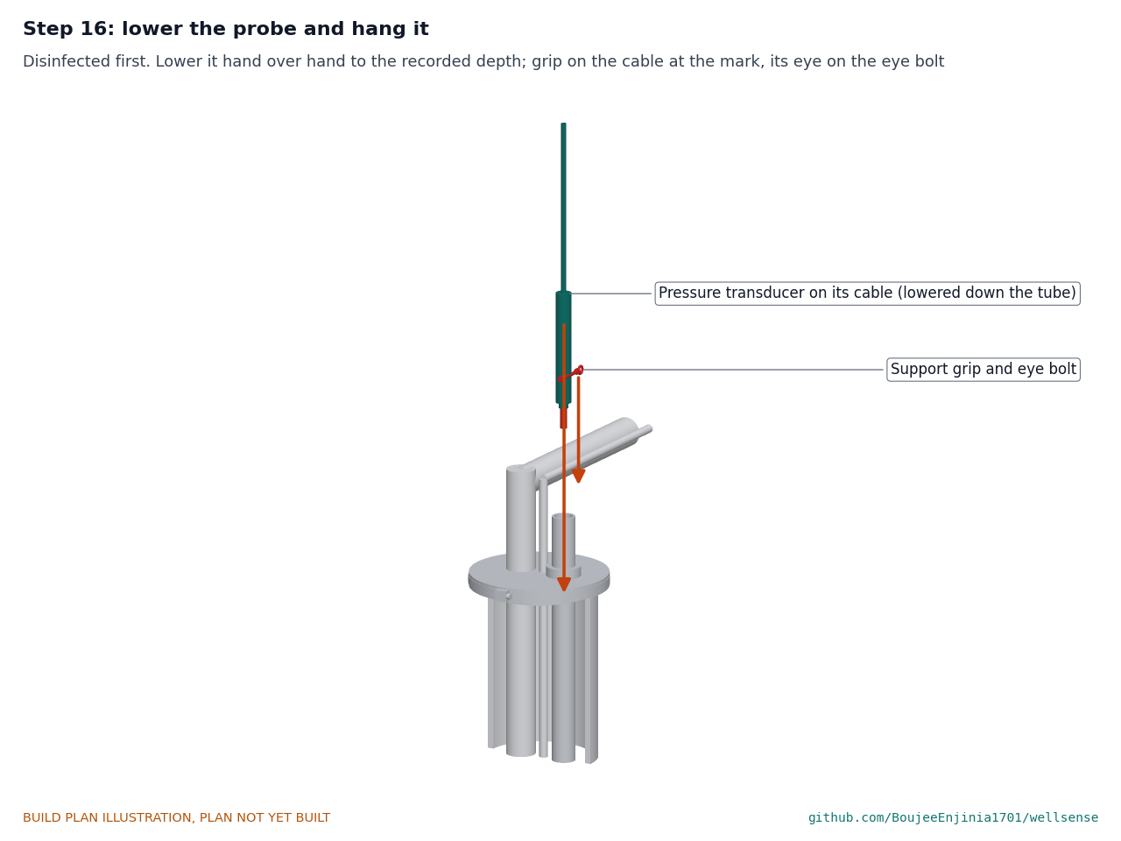
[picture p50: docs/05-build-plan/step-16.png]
Step 16


Disinfect the probe and the cable. Mark the cable at the probe depth from the measuring point (the casing top). Lower the probe hand over hand down the tube, feeding cable from the box end, until the mark is at the cap. Push the support grip onto the cable at the mark, put its eye over the eye bolt, fit the bolt's nut and seat the cap on the tube.

### Step 17: service loop, terminals and lid

Step 17

Coil 1.1 m of cable in the box in front of the internal plate, cut the rest, strip the cores to the terminal strip and leave the vent tube open. Put a fresh charge in the breather. Check the lid gasket is clean and seated with no wire across it, and tighten the lid screws in a cross pattern.

### Step 18: fit the padlocks

Step 18

Hang the first padlock through the eye of the eye bolt on the tube cap and close it. Close the second padlock through the holes of both hasp tabs with the lid shut. Check that the one key opens and closes both, and that the security-head screw on the rim band is tight. Take the key with you.

## 5. First checks

These are the checks a TRL 4 test report would record; this plan only lists them. Requirement numbers are those of WLS-REQ-001.

*Table 3. First checks.*

| Check | Requirement | How | Pass when |
| --- | --- | --- | --- |
| Probe runs freely | R10 | Lower and lift the probe the full tube length | It never catches; the support grip holds it at the mark |
| Seal | R9 | Look along the split, the rim and each wrap under a lamp; pour a cup of water on the plate | Halves meet with no daylight; no water passes into the casing |
| Tube carried by the collar | R2 | Pull down on the tube by hand at the collar | The collar does not slip |
| Loop supply | R8 | Bench supply at 12 V on the lead in place of FieldNode, 100 mA limit; measure at the transducer's terminals with a 20 mA loop calibrator in place of the probe | At least 20 V at 20 mA |
| Loop reading | R3, R4 | Loop calibrator at 4, 12 and 20 mA; read the ADC | Within 0.1 % of 0.60, 1.80 and 3.00 V across the shunt |
| ADC protection | R4 | Calibrator at 25 mA | ADC input stays below its 3.6 V limit |
| Barometric sensor | R15 | Read it over I2C with the box shut | Within 1 hPa of a reference barometer |
| Two-point calibration lift | R4 | Undo the tail's connector at the cap, lift cap and probe 1 m, read, lower, reconnect | The service loop feeds the 1 m without pulling on the terminals |
| Fixings | R16 | Push on the box, conduit and FieldNode core by hand | Nothing moves at any joint; the conduit does not touch the riser |
| Locks | R16 | With both padlocks shut, try to lift the lid, turn the eye bolt and undo the rim band screw with ordinary tools | None of the three can be undone; the one key opens both padlocks |
| Installation time | R11 | Time steps 12 to 18 with two people | 2 h or less at a well with the tube already in place |

## 6. Safety stops

Stop at each point. Carry on only when everything listed is true.

- **S1. Before digging the footing.** Buried services located; the hole is at least 600 mm from the well's apron edge and from any pump cable trench.
- **S2. Before wiring the interface modules.** No supply connected; the boost module output is set to 24 V on the bench, measured, before it is wired to the loop.
- **S3. Before the FieldNode lead is plugged in.** The FieldNode core's fuse is out and its own stop points are followed; the lead's 12 V and ground are checked against port A's pinout with a meter.
- **S4. Before the junction box is closed.** No bare conductor outside a terminal; the vent tube is open; the boost output is 24 V or less.
- **S5. Before any work at a real well (outside this plan).** The pump supply is isolated and locked off, with the key held by the person at the wellhead; the well owner or water authority agrees; a second person is present; the open casing is covered whenever nobody is working at it.
- **S6. Before anything goes into a real well.** The probe, cable, tube, wraps and gasket are disinfected as the local water authority advises, and every wetted part has its drinking-water certificate.
- **S7. Before lowering the tube or the probe.** Two people; the cable or tube is fed hand over hand and never allowed to run; the cable never carries more than its strain member's rating.
- **S8. Before leaving the site.** The seal plate band is tight, the cap is seated, the junction box is shut, both padlocks are closed, and the FieldNode core's own final checks are done.

## 7. Tools, skills and workspace

**Tools.** Hacksaw with a 24 teeth per inch blade; pipe cutter; 1/2 in hand conduit bender; bench vice with soft jaws; bench drill or a drill in a stand; drills 2.5 to 12 mm; step drill to 22 mm; hole saws 38 and 46 mm; countersink; M4 tap and tap drill; jigsaw with metal and plastic blades and a circle jig; flat, half-round and round files; deburring tool; scriber, engineer's square, 45° square, steel rule and calipers; V-block for drilling tube; 3D printer with an enclosure and a bed of at least 100 x 130 mm that prints ASA; soldering iron; ferrule crimper and wire strippers; multimeter; bench power supply with an adjustable current limit; 4 to 20 mA loop calibrator; torque screwdriver; the security-head bit for the rim band screw; spirit level; spade, post-hole digger and bucket.

**Skills.** No certified trade is needed. Basic metalwork and plastic work (marking out, sawing, drilling, filing, tapping, bending conduit), through-hole soldering and crimping, safe use of a bench power supply, and mixing concrete. All circuits are extra-low voltage: 12 V from FieldNode and 24 V in the loop. Working at a real well with a mains-powered pump needs the owner's or water authority's agreement and a person who can isolate the pump safely.

**Workspace.** A bench about 1.2 x 0.6 m; a metalwork corner kept apart from the electronics; a ventilated place for the printer; a yard where the post can be set and the mock-up casing stood upright and held.

**Personal protective equipment.** Safety glasses for cutting, drilling and soldering; cut-resistant gloves for metal edges; gloves and eye protection when mixing concrete; nitrile gloves when using disinfectant and solvent cement; no gloves near a turning drill.

## 8. Where the numbers come from

- Model and constructability checks: `cad/src/model.py` (`python cad/src/model.py --check`, 118 checks); STEP and STL exports in `cad/step/` and `cad/stl/`; FieldNode geometry in `cad/vendor/`.
- Pictures: `cad/src/build_plan_media.py`, using `.kit/build_views.py`; written to `docs/05-build-plan/` and `cad/drawings/WLS-DWG-101` to `WLS-DWG-109`.
- General arrangement: `cad/drawings/WLS-DWG-001.pdf`, Rev P6.
- Calculations: `docs/04-calcs/01-sizing.md` (WLS-CAL-001 v0.5) and `docs/04-calcs/sizing.py`; loop supply [B1], loads [D3] to [D7], cost [H1] to [H3].
- Bill of materials: `bom/bom.csv`.
- Decisions: `docs/decisions/0004-design-for-construction.md` (WLS-DDR-004), with WLS-DDR-001 to WLS-DDR-003.
- Requirements: `docs/03-requirements.md` (WLS-REQ-001 v0.8).
- FieldNode core: the FieldNode build plan FND-BLD-001 and drawing FND-DWG-001.

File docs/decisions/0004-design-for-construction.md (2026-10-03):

---
doc_id: WLS-DDR-004
title: WellSense design for construction
project: WellSense
doc_type: Design decision record
version: "0.3"
status: Draft
date: '2026-10-02'
author: Amish Chadha
license: CERN-OHL-S-2.0
revisions:
- version: "0.1"
  date: '2026-10-02'
  author: Amish Chadha
  change: Changes that make the concept physically buildable, with the reason for each; made under Amish's 2026-09-30 instruction to make the design physically buildable; open for his review
- version: "0.2"
  date: '2026-10-02'
  author: Amish Chadha
  change: Accepted by Amish on 2026-10-02, with A1 (locking fitted from the start) and A2 (vendor copy re-exported) decided
- version: "0.3"
  date: '2026-10-02'
  author: Amish Chadha
  change: A1 carried into the design, with the locks modelled, priced and drawn; cost and document versions updated
---

# 0004: Design for construction

- **Date:** 2026-10-02
- **Status:** draft; accepted. Amish, 2026-10-02: "APPROVED: The open decisions from the last wave (TremorTrace to ZeerBox) came in after the review and aren't on the page either." This approves the recommendation written for each open decision in the design decisions register (WLS-DEC-001 v0.1): every change in Tables 1 and 2 is accepted as made, and A1 and A2 in Table 3 are decided as recorded there.

## Context

On 2026-09-30 Amish asked for every repo to have a prototype build plan that shows how each component is made and how it fits the next, with pictures, and wrote: "If you are realising that the design cannot be built as per concept - fix the design assumptions to match and be physically feasible as you draw the illustrations." The TRL 3 model of WLS-DDR-002 and WLS-DDR-003 was a massing model: it showed what WellSense does, but several parts could not be made or fixed as drawn. Checking it with build123d found, among others, that the junction box overlapped the post by 602 mm³, the interface board sat inside a solid box (63,000 mm³ of overlap), the conduit was a solid rod round the cable (46,400 mm³ of overlap), the barometric housing floated 1 mm off the post with no fixing, and the FieldNode core floated 17.9 mm off the post with nothing holding it.

The changes keep what WellSense does: the same vented 4 to 20 mA probe hung in its own 1 in access tube, the same seal at the wellhead, the same galvanized conduit over the surface cable, the same junction box, interface board, barometric sensor and FieldNode core on a 2.1 m post 0.75 m from the well, the same 15 min readings and the same calibration method. Nothing here changes the pitch or the safety case. Every change is in `cad/src/model.py`, which now runs 99 constructability checks (`python cad/src/model.py --check`): parts that must touch do touch, and parts that must not touch are apart by at least the stated clearance. All 99 pass.

## Decision

*Table 1. Changes made to the model, the BOM and the calculations.*

| # | Problem in the concept | Change made | Why this way |
| --- | --- | --- | --- |
| P1 | The FieldNode core was a massing block on two legs, 17.9 mm off the post with no V-blocks or bands, and its panel bracket was not FieldNode's. | The FieldNode core is now FieldNode's constructable design (FND-DDR-003), built to FND-BLD-001 and drawn from geometry exported from the FieldNode model (`cad/vendor/`). Its V-blocks sit on the WellSense post and its two bands clamp it, base 1,750 mm up. WellSense uses sensor port A. | The post is FieldNode's 48.3 mm design pole, so FieldNode fits it unchanged; one design, one build plan. |
| P2 | The junction box was drawn flat against the round post, overlapping it by 602 mm³, and "held" by two band rings round the post, one of them at 1,450 mm, above the box. A band cannot hold a flat box on a round post. | A 140 x 530 x 3 mm aluminium junction box plate, 42 mm in front of the post axis, held by two V-blocks (the same 60 x 33 x 20 mm part as FieldNode's) and two 12 mm band clamps through slots in the plate. The box sits flat on the plate on its maker's four lugs, one M5 screw each, and faces the well. | The same mounting method as FieldNode, with the same V-block, so one jig and one making sketch serve both. The plate also carries the conduit saddles and the barometric housing. |
| P3 | The junction box was a solid block with the interface board inside it, and it had no cable entries. | The box is a bought IP66 box with four moulded bosses inside its back wall. A printed internal plate on the bosses carries the boost module, the ADC and shunt module, the regulator and surge module and a terminal strip on standoffs. Four entries in the floor, in two rows 22 and 62 mm from the back face: conduit hub, M16 gland for the FieldNode lead, desiccant breather and M12 gland for the barometric lead; outside flanges at least 10 mm apart. | Entries in the floor keep water out; the internal plate lifts out as one piece; the plate clears the entry nuts by 6 mm. |
| P4 | The barometric housing floated 1 mm off the post on the side away from the well, with no fixing and no cable. | A flanged louvred housing screwed to the junction box plate below the box with two M4 screws; its 0.3 m lead enters the box through the M12 gland. | It reads air pressure anywhere near the box; a short lead and a flat fixing. |
| P5 | The conduit was drawn as a solid rod round the cable, with sharp mitred corners a rigid conduit cannot take. It was joined rigidly to the tube cap, so the cap could not come off to lift the probe for the two-point calibration, and nothing held it at the post. | A rigid 1/2 in conduit with one 90° bend of 100 mm radius runs level at 720 mm from the well to the post and up into a hub in the junction box floor; two spacer saddles hold its upright leg to the plate. A 0.3 m liquid-tight flexible tail joins its well end to a connector in the tube cap. The cable carries a 1.1 m service loop coiled in the box, so the probe can be lifted 1 m. | A hand bender makes the bend; the flexible tail lets the cap lift off after one connector is undone; the cable feeds out of the box for the lift. The cable's surface run is now 2.7 m, not 2 m. |
| P6 | The seal plate was one 200 mm disc with two gland bosses. It could not be fitted round an installed riser, which the concept requires, had nothing to locate or hold it on the casing, and had no way through for the pump's power cable. | Two half plates of 20 mm drinking-water HDPE, split on the line through the three holes; a 10 mm HDPE spigot half ring screwed under each half locates it inside the casing; a 3 mm EPDM gasket on the casing rim; one turn of 2 mm EPDM wrap round the riser, the pump cable and the tube, squeezed in the split holes; a worm-drive band round the rim pulls the halves together. | Every part is cut with a jigsaw and drilled; it goes round the riser and pump cable without pulling the pump; the band gives an even squeeze on the wraps. |
| P7 | The calculations said a tube clamp was needed to carry 264 N of tube at 60 m, but none was modelled. | A split aluminium shaft collar on the tube rests on the seal plate. Bearing on the HDPE is 0.24 MPa [D5]. | A bought part; set the tube height by sliding the collar. |
| P8 | The tube cap had a "cable-grip hanger" boss on top, but nothing carried the probe's weight, and the cap could not take the conduit. | A 1 in slip cap, not glued, drilled for the conduit connector in its top and for an M5 cross bolt through its sides. A stainless cable support grip on the cable hangs by its eye from the cross bolt. The cap sits on the tube end. Bearing on the cap walls is 0.79 MPa at 60 m [D6]. | The grip sets and holds the recorded probe depth; the cap, grip and probe lift off together for calibration. |
| P9 | The access tube's slots were 3 x 60 mm, cut lengthwise through both walls, which needs a router; its end plug was drawn as part of the tube. | Ten rings of 8 mm holes over the bottom 0.5 m, two holes drilled straight through at right angles in each ring, alternate rings turned 45°. A bought 1 in slip cap is solvent-welded on the bottom end, with an 8 mm drain hole. | A hand drill and a V-block do it; the 40 holes give about three and a half times the bore's area. |
| P10 | The lead from the junction box to the FieldNode core entered the box through its top, which lets water in, and had no plug or BOM line. | A 1.5 m four-core lead with an M12 plug, BOM line 15: through the M16 gland in the box floor with a drip loop, up the post outside the bands, cable-tied, into FieldNode sensor port A. | Every entry is in a floor; the lead clears the plate, bands and V-blocks by at least 3.5 mm. |
| P11 | The post's top was open. | A push-in plastic cap. | Keeps rain out of the pipe. |

*Table 2. Knock-on changes.*

| Item | Change | Reason |
| --- | --- | --- |
| Cost | Lines 4, 5, 6, 7, 10 and 14 repriced and line 15 added. Value-engineering target: USD 200. Estimated cost of the constructable design: USD 244.40 (USD 44.40 over the target) before the locks of A1; with them USD 262.40 (USD 62.40 over the target); the concept was USD 197.60 [H2], [H2c], [H2d]. Line 8, the FieldNode core, is now FieldNode's constructable base node, $139.00 (was $126.00), outside the target. | Parts added for construction. `budget_usd` is unchanged. |
| Cable | 33 m at the 30 m design depth (was 32 m); surface run 2.7 m including the 1.1 m service loop; loop supply at 60 m still leaves 8.16 V of margin [B1]. | P5. |
| Drawing | WLS-DWG-001 Rev P6 (locks added); WLS-DWG-109 Rev P2; making sketches WLS-DWG-101 to 109 added. | Follows the model. |
| Documents | WLS-CAL-001 v0.5, WLS-REQ-001 v0.8, WLS-PRC-001 v0.8, `bom/bom.csv`, `bom/bom-notes.md`. R12 is now reported against the value-engineering target. No other requirement changed status. | Follows the model. |
| Media | Concept media regenerated from the model. The photoreal renders (`media/render-*.png`), `media/card.png`, `media/social-preview.png` and the appearance model `cad/src/product_model.py` need re-rendering on Amish's Mac. The appearance model `cad/src/product_model.py` was brought into line with the constructable design on 2026-10-02 and the render scenes exported. | They are made with Blender. |

*Table 3. Decided by Amish, 2026-10-02.*

| # | Question | Options | Recommendation |
| --- | --- | --- | --- |
| A1 | Locking (R16). The rim band, tube cap and junction box lid can now be undone with a screwdriver or by hand, which the concept did not address either. | (a) a security-head screw on the rim band, a padlock through the cross bolt's head, and a padlockable hasp kit on the box; (b) a lockable steel cover over the whole wellhead. | (a): small, cheap parts that fit the present design; decide after the first site visit. **Decided by Amish, 2026-10-02:** (a) is fitted on the prototype from the start; (b) at sites where the first site visit shows open access or livestock. The locking parts are now in the model, the BOM (line 16, and an eye bolt in line 5) and the drawings; the padlock on the cap is hung through the eye of an M5 eye bolt, which stops the bolt being unscrewed but not the cap being lifted (the steel cover does that). |
| A2 | The FieldNode core's geometry is copied from the FieldNode model into `cad/vendor/`, so a FieldNode change does not reach WellSense until it is exported again. | (a) keep the copy and re-export it whenever FieldNode's general arrangement is revised; (b) share it through a common library repo. | (a), noted in the review checklist. **Decided by Amish, 2026-10-02: (a).** |

## Consequences

- `design_state: constructable` in `project.yaml`. The build plan WLS-BLD-001 shows every component and step in pictures generated from the model (`cad/src/build_plan_media.py`).
- Requirement status: 1 not met (R9), 4 at risk (R4, R10, R15, R16), 3 not verifiable at TRL 3 (R5, R11, R13), 7 met, and R12 over its value-engineering target (WLS-CAL-001 v0.4).
- The seal plate hole sizes follow the design well's riser and pump cable; at a real well they are set from the measured riser and cable. The enclosure's boss spacing and lug kit, the collar's grip rating and the drinking-water certificates of the HDPE and EPDM are confirmed when parts are bought (WLS-DEC-001).
- TRL stays 3. Nothing in this record authorizes building or testing.

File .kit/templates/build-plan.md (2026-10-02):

---
doc_id: PRJ-BLD-001
title: Project prototype build plan
project: Project name
doc_type: Build plan
version: "0.1"
status: Draft
date: YYYY-MM-DD
author: Amish Chadha
license: CERN-OHL-S-2.0
revisions:
  - version: "0.1"
    date: YYYY-MM-DD
    author: Amish Chadha
    change: First build plan; design made constructable
---

# Project prototype build plan

**Plan, not yet built.** How to build the first proof-of-concept prototype, component by component. Building and testing to it is TRL 4 work. Decisions still to be made are kept in the design decisions register (`docs/06-design-decisions.md`), not here.

## 1. What you are building

Every component, pulled apart and numbered in build order

One short paragraph: what the prototype is, how many components, which are made and which are bought, and the main ways they are made.

## 2. What changed to make it buildable

| Component | The concept had | The buildable design has | Why |
| --- | --- | --- | --- |

## 3. Making the components

### 3.1 Component name

Making sketch

**What it is and what it is made from.**

**How to make it.**

1. Mark out ...
2. Cut ...

**How it fits the parts next to it.**

Close-up of the joint

**Check before moving on.**

## 4. Putting it together

### Step 1: ...

Step 1

## 5. First checks

| Check | Requirement | How | Pass when |
| --- | --- | --- | --- |

## 6. Safety stops

## 7. Tools, skills and workspace

## 8. Where the numbers come from

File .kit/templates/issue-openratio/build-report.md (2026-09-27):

---
name: Build report
about: Tell us what happened when you built, printed or tested part of this design
title: "Build report: "
labels: build-report
---

This is a research and educational prototype, not a medical device. It is a TRL 3 concept and is not released for fabrication. If you build any part of it, you do so at your own risk. Reports help everyone.

**What you built** (part, sub-assembly or test)

**Materials, tools and settings**

**What worked**

**What did not work, with photos or measurements if you have them**

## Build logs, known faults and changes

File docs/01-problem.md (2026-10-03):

---
doc_id: WLS-PRB-001
title: WellSense problem statement
project: WellSense
doc_type: Problem statement
version: "0.6"
status: Draft
date: '2026-10-02'
author: Amish Chadha
license: CERN-OHL-S-2.0
revisions:
- version: "0.1"
  date: '2026-09-25'
  author: Amish Chadha
  change: Initial scaffold
- version: "0.2"
  date: '2026-09-25'
  author: Amish Chadha
  change: Populate to TRL 2 (problem, users, context, constraints, prior work)
- version: "0.3"
  date: '2026-09-25'
  author: Amish Chadha
  change: Reflect WLS-DDR-001 (budget covers WellSense parts only) and the TRL 3 cost and access findings of WLS-CAL-001
- version: "0.4"
  date: '2026-09-25'
  author: Amish Chadha
  change: Recommendations accepted by Amish (DDR-002)
- version: "0.5"
  date: '2026-09-26'
  author: Amish Chadha
  change: Budget approved by Amish; constraint now $200
- version: "0.6"
  date: '2026-10-02'
  author: Amish Chadha
  change: Partner and region answered by Amish's decision of 2026-10-02 (WLS-DEC-001)
---

# WellSense problem statement

Groundwater is falling in many regions, yet most wells have no measurement, so over-pumping is noticed only when wells run dry. The people who share an aquifer need a cheap, trustworthy record of how the water level in their own wells moves through the day, the season and the years, in a form they can read and discuss.

## The problem

Groundwater supplies about half of the water withdrawn for domestic use worldwide, including drinking water for most rural people, and about 25 % of irrigation water ([UNESCO, World Water Development Report 2022](https://www.unesco.org/reports/wwdr/2022/en)). A synthesis of in situ records from about 170,000 monitoring wells in 1,693 aquifer systems found rapid declines of more than 0.5 m a year widespread in the twenty-first century, and accelerating declines in 30 % of regional aquifers ([Jasechko et al., Nature, 2024](https://www.nature.com/articles/s41586-023-06879-8)). The same study shows recoveries where pumping was regulated or recharge increased, as in the Bangkok basin, so measured decline can be reversed when people act on it.

Most wells that people actually draw from are not monitored. Official networks use a small number of dedicated observation wells, and data reach village councils, farmer groups and handpump committees late or not at all. Owners learn that the aquifer is falling when the pump starts to suck air or the handpump runs dry, and the usual response is to drill deeper. In the United States, new wells are being built deeper 1.4 to 9.2 times more often than shallower ([Perrone and Jasechko, Nature Sustainability, 2019](https://www.nature.com/articles/s41893-019-0325-z)), a stopgap that the authors call unsustainable.

Commercial water level loggers exist and work well, but they cost several hundred dollars each before telemetry, need vendor software, and are usually owned by an agency rather than the community. There is no open, low-cost reference design that a community group, a WASH organization or a school can build, check and repair.

## Users and context

| User | Need | Context |
| --- | --- | --- |
| Village water committee or farmer group sharing an aquifer | See whether the water table is falling, how fast, and how it responds to pumping and rain; set local rules | Rural India, sub-Saharan Africa, Mexico, Middle East; shared tube wells and boreholes |
| Handpump or borehole caretaker | Know when static level approaches the pump intake before the supply fails | Community water points, often no grid power |
| Farmer with a private irrigation well | Plan pumping hours and crop choice; avoid dry wells | Seasonal peaks in the dry season |
| WASH NGO, utility or groundwater agency | Low-cost network densification between official monitoring wells | Programme monitoring, drought early warning |
| Hydrogeology student or researcher | Open, inspectable data and hardware for teaching and small studies | Universities, schools |

Typical wells are 100 to 200 mm (4 to 8 in) boreholes 20 to 150 m deep with a submersible pump or handpump riser inside, or large-diameter dug wells. Static water levels lie from a few metres to more than 50 m below ground, with seasonal swings of several metres in intensively pumped areas. The wellhead may be exposed to sun, flooding, livestock and tampering. Mobile coverage is patchy; the lab's shared node, FieldNode, reports over LoRaWAN to a TwinKit gateway or a public network.

## Constraints

- Garage-buildable prototype, $200 USD in WellSense parts per well at a 30 m probe depth, with the FieldNode core costed in the FieldNode repo (WLS-DDR-001, D1, and WLS-DDR-002, both decided by Amish on 2026-09-25; the figure was raised from $190 to $200 by Amish on 2026-09-26). With the surface conduit added under WLS-DDR-002 the parts cost $197.60 at 30 m, so the budget holds to about 31.3 m (WLS-CAL-001 v0.3).
- Built on the lab's shared FieldNode core for power, radio and enclosure; WellSense adds only the probe, wellhead parts and interface.
- No change to the water supply: nothing in the well may contaminate the water, and the well must stay sealed.
- Must work beside an existing pump and riser without pulling them where possible; the probe body is limited to 22 mm so it runs freely in a 1 in access tube (WLS-DDR-002).
- Data belongs to the community that hosts the well. Readings are water levels only; the owner decides what to share.
- Hand tools only for installation; parts available from plumbing, electrical and online suppliers.

## Prior work

- **Commercial loggers.** Absolute-pressure loggers with barometric compensation and vented 4 to 20 mA transducers are the standard tools in groundwater monitoring. They are accurate and robust but closed and costly for community use.
- **Standard methods.** The U.S. Geological Survey publishes procedures for measuring well water levels with a steel tape, an electric tape and a submersible pressure transducer ([Cunningham and Schalk, USGS Techniques and Methods 1-A1, 2011](https://pubs.usgs.gov/tm/1a1/)). WellSense follows the same logic: a transducer for the continuous record and a manual tape for the datum and periodic checks.
- **Open loggers.** The Cave Pearl Project showed that an Arduino-class logger built from breakout boards can run for more than a year on three AA cells for $25 to $50 before sensors ([Beddows and Mallon, Sensors, 2018](https://www.mdpi.com/1424-8220/18/2/530)).
- **Community groundwater management.** In the Andhra Pradesh Farmer Managed Groundwater Systems project, farmers took fortnightly measurements of static and pumping water levels in their own wells, ran rain gauges and drew up crop-water budgets before the winter season; about half a million farmers in 661 habitations took part ([FAO, *Smallholders and Sustainable Wells*, 2013](https://www.fao.org/4/i3320e/i3320e.pdf)). WellSense aims to make that record continuous and cheap.

## Out of scope

- Water quality (conductivity, nitrate, arsenic). A conductivity probe could share the port later.
- Pump control or metering of abstraction.
- Aquifer modelling beyond simple trend and drawdown charts.

## Open questions

- First partner and region for co-design: an Indian farmer group, an African handpump programme or a US groundwater agency? Decided by Amish, 2026-10-02 (WLS-DEC-001): a participatory groundwater management group in India that works with farmer groups on shared aquifers; the first candidate to approach is ACWADAM in Pune, with its well sizes setting the design well and the FieldNode core at its sites on the IN865 band; not yet approached.
- How much access to the wellhead can a community give: can an access tube be added without pulling the pump? WLS-CAL-001 shows a 1 in tube fits beside the riser of a 150 mm well in plan, but only an installation trial can show whether it can be lowered past an installed pump's riser and cable.
- Who holds and publishes the data, and in what language and form do users want the dashboard?

## User research and co-design

This design is for communities the author is not part of, so requirements come from the people who will use it.

- [ ] Identify a local partner organization (Helpful Engineering network, NGO or university)
- [ ] Run co-design sessions with intended users; record who, where and what was learned
- [ ] Validate load, distance, terrain and cost assumptions in the field
- [ ] Revise requirements (REQ) from findings before freezing the design

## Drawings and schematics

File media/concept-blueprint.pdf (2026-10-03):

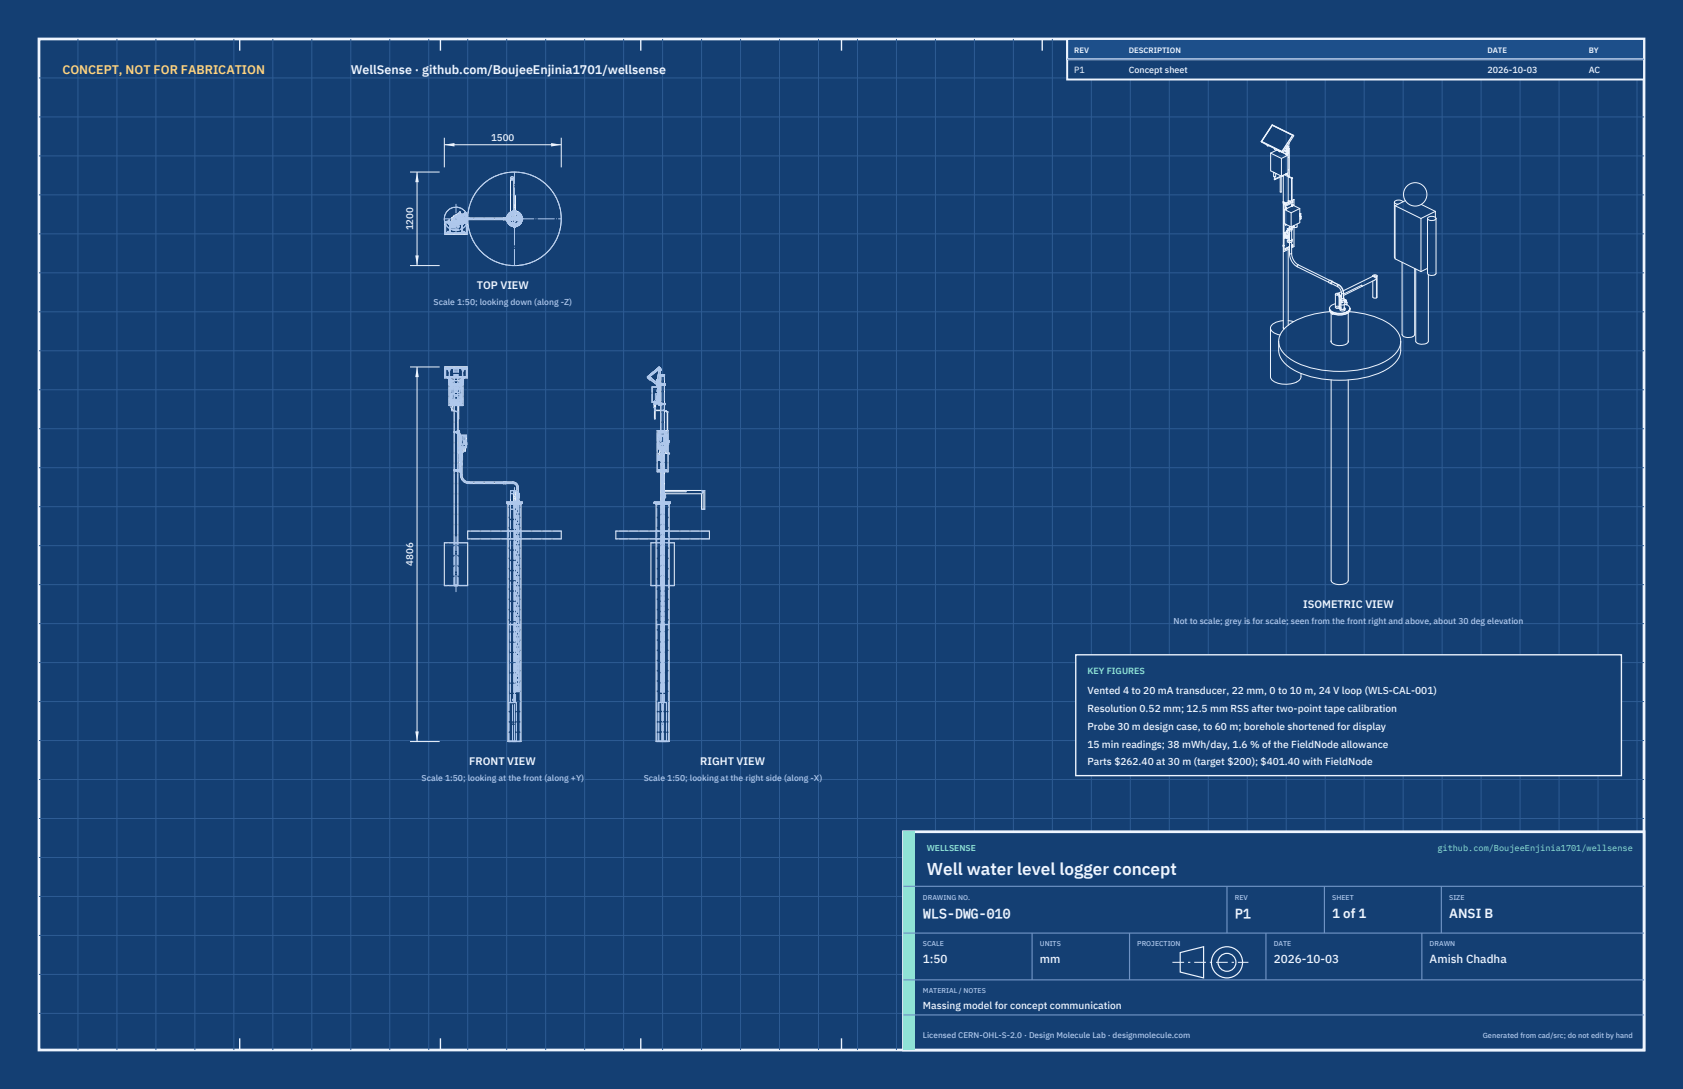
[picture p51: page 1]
CONCEPT, NOT FOR FABRICATION; WellSense · github.com/BoujeeEnjinia1701/wellsense; FRONT VIEW; TOP VIEW; RIGHT VIEW; ISOMETRIC VIEW; REV; DESCRIPTION; DATE; Concept sheet; WELLSENSE; github.com/BoujeeEnjinia1701/wellsense; DRAWING NO. WLS-DWG-010; REV P1; SHEET 1 of 1; SIZE ANSI B; SCALE 1:50; UNITS mm; PROJECTION; DRAWN Amish Chadha; Licensed CERN-OHL-S-2.0 · Design Molecule Lab · designmolecule.com; Generated from cad/src; do not edit by hand

Scale 1:50; looking down (along -Z)

Not to scale; grey is for scale; seen from the front right and above, about 30 deg elevation

KEY FIGURES
Vented 4 to 20 mA transducer, 22 mm, 0 to 10 m, 24 V loop (WLS-CAL-001)
Resolution 0.52 mm; 12.5 mm RSS after two-point tape calibration
Probe 30 m design case, to 60 m; borehole shortened for display
15 min readings; 38 mWh/day, 1.6 % of the FieldNode allowance
Parts $262.40 at 30 m (target $200); $401.40 with FieldNode

Scale 1:50; looking at the front (along +Y)

Scale 1:50; looking at the right side (along -X)

Well water level logger concept

MATERIAL / NOTES
Massing model for concept communication

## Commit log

2026-09-25 Initial scaffold: standard open hardware layout, CERN-OHL-S v2 + MIT licenses
    Claude-Session: https://claude.ai/code/session_01XuhhSU4W6fYhgCfURbrkut
    [bom.csv]
2026-09-25 Populate to TRL 2: problem, requirements, precis, concept media, BOM and README use cases
    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
    [bom.csv]
2026-09-26 Advance to TRL 3: DDR-001, CAL-001 sizing, parametric model with STEP/STL, GA drawing, priced BOM; TRL 4 on hold
    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
    [bom.csv, results.csv, wellsense-assembly.step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]
2026-09-26 Accept all recommendations (DDR-002), switch footer to designmolecule.com, add README write-up with new inspiration point
    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
    [bom.csv, results.csv, wellsense-assembly.step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]
2026-09-26 Strengthen sources, apply approved budgets, add CITATION.cff and CONTRIBUTORS.md with credits
    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
    [results.csv]
2026-09-27 Product appearance model and photoreal renders
    Adds cad/src/product_model.py (appearance model for renders only, all main
    dimensions from model.py) and Blender renders in media/render-*.png,
    captioned with the project, repository and viewing direction. README leads
    with the product render; trl stays 3.
    Also applies Amish's 2026-09-27 decision: FieldNode panel faces away from the post in model.py (WLS-DDR-003).
    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
    [wellsense-assembly.step, wellsense-assembly.stl, wellsense-post.step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]
2026-10-01 Image quality pass: legible exploded views, flow diagrams and drawing sheets
    Kit 1.6.1 image layout: the parts list sits in its own column, number bubbles sit on visible parts and never overlap, small parts get a leader, pictures are cropped to the subject, flow labels keep numbers with their units, and sheet captions and the revision table no longer overprint. Concept images, blueprint and general arrangement sheet regenerated; repo-specific labels moved clear of other text and lines.
2026-10-02 Kit 1.7.0: constructable design, illustrated build plan and design decisions register
    The design is now constructable: every part can be made and fits its neighbours, with each change recorded in a Design for construction decision record (made under Amish's 2026-09-30 instruction; ope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
    FlexHand also credits Dr. Geeti Chadha as a contribut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
    [bom.csv, results.csv, wellsense-assembly.step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]
2026-10-03 Carry approved follow-ups into the design and redo photoreal renders
    Amish approved the follow-up actions from the open-decision sign-off ("APPROVED CHANGES, COMPLETE THESE", 2026-10-02), the design-for-construction change tables in ten repos, the last wave's open dec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
    [bom.csv, results.csv, wellsense-assembly.step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]
2026-10-28 Kit 1.9.1 upgrade: pipeline documents and detailed CAD for every option
    Kit 1.9.1 installed (.kit, CLAUDE.md, .claude/commands). Kit 1.8 pipeline: STEM check with fixes under the 2026-10-23 standing instruction, concept options with the current design as option A, URS, PRS, generated RTM, REG, FEA, RSK with design FMEA, MKT, PLN and DDR; kit 1.9 D3 model of every option passing cad/fidelity.json; independent review recorded in the STEM check. Amish's 2026-10-25 decisions recorded where he approved a recommendation; all others proposed, awaiting Amish. Product renders and the options picture follow in a later commit where not yet included.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
2026-10-29 Add Cycles product renders and the concept options picture
    Blender Cycles renders of the kit 1.9.1 model, rendered on Amish's Mac and captioned; media/options.png from the D3 option models (this also clears the failing docs check, which needs the picture); cards and PDFs rebuilt. The options picture labels option A as the current design unless project.yaml records Amish's choice.
2026-10-29 Add the concept options picture rendered from the D3 option models
    media/options.png from Blender Cycles panels of every option, rendered on Amish's Mac; the label reads CURRENT DESIGN unless project.yaml records Amish's choice. Clears the docs check, which needs th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

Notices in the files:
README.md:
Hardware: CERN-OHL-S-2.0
